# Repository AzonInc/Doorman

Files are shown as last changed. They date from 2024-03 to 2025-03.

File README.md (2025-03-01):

<h1 align="center">
    <br>
    Doorman S3
    <br>
    <br>
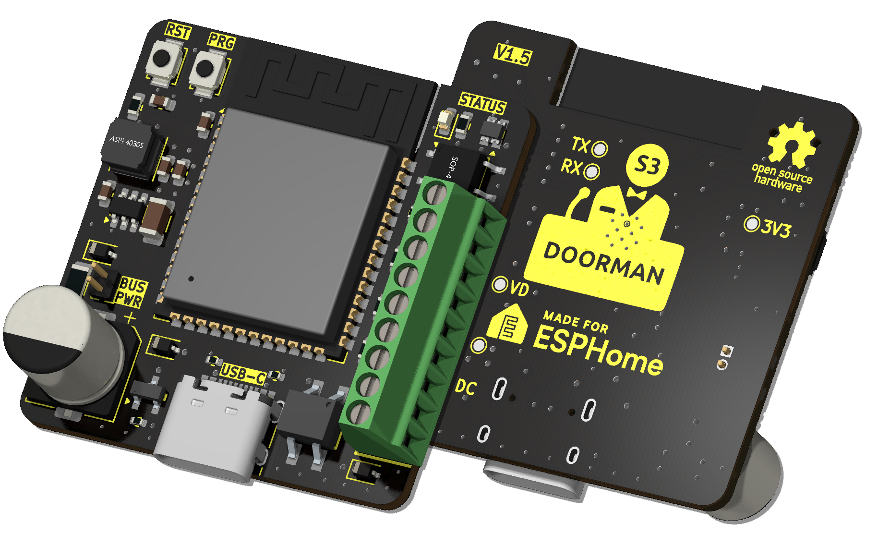
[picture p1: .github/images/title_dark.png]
Doorman S3
    
    <br>
</h1>

**Doorman S3** is a versatile intercom gateway designed to connect your [TCS](https://www.tcsag.de/) or [Koch](https://www.kochag.ch/) intercom system to any home automation platform. It's also compatible with rebranded versions of [Niko](https://www.niko.eu/), [Scantron](https://scantron.dk/), and older [Jung](https://www.jung-group.com/) intercom models.

But that's not all - the **Doorman S3** is more than just an intercom bridge. With its integrated relay, you can simulate button presses to control door openers or lights, supporting up to **40V** and a maximum of **2.5A**. 

Even if your intercom system isn't directly listed, if it operates on a **2-wire bus** in the **14-24V DC range**, you may still be able to implement other protocols. Additionally, you can monitor voltage levels from older intercom systems to trigger actions based on those readings.

For more information on the manufacturing process, head to the **Manufacturing** section further down.

---

<div id="toc">
  <ul style="list-style: none">
    <summary>
      <h1>🚀 Getting started</h1>
    </summary>
  </ul>
</div>

Before diving into the installation process, visit the [Doorman Docs](https://doorman.azon.ai/) for comprehensive setup guides. If you have questions, don't hesitate to reach out on [Discord](https://discord.gg/t2d34dvmBf) or [GitHub Issues](https://github.com/azoninc/doorman/issues). I'm here to assist!

---

<div id="toc">
  <ul style="list-style: none">
    <summary>
      <h1>📦 Interested in buying one?</h1>
    </summary>
  </ul>
</div>

You can get fully assembled **Doorman S3** units with the **[Stock Firmware](firmware/stock-firmware)** pre-installed and ready for immediate integration into **Home Assistant**. 

For inquiries, feel free to reach out via:
- [Discord](https://discord.gg/t2d34dvmBf)
- [E-Mail](mailto:flo@azon.ai?subject=Doorman)

---

<div id="toc">
  <ul style="list-style: none">
    <summary>
      <h1>🛠️ Built Your Own Hardware?</h1>
    </summary>
  </ul>
</div>

Check out the [TC:BUS ESPHome component documentation](https://doorman.azon.ai/reference/esphome-component) for detailed instructions on integrating your DIY hardware with the TC:BUS. Whether you're expanding your **Doorman project** or using it as a starting point for your own system, this resource will guide you through seamless integration.

---

<div id="toc">
  <ul style="list-style: none">
    <summary>
      <h1>🤖 Features</h1>
    </summary>
  </ul>
</div>

- **ESP32-S3 Powered** for robust performance
- **USB-C port** for effortless flashing (because USB-C is just cool 😎)
- **Compact design** fits into any setup
- **Configurable WS2812B RGB LED** for event-based visual indicators
- **Two additional GPIOs** for easy expansion (e.g., I²C sensors)
- **Solid-state relay** for switching up to 40V (max. 2.5A)—perfect for older intercom systems
- **External Button** (G + BTN) for manual triggering
- **Bridge Rectifier** for correcting polarity on bus-wire input
- **TC:BUS Communication** for door functions and detecting the doorbell
- **Nuki Bridge functionality** with the [Nuki Bridge Firmware](https://doorman.azon.ai/guide/firmware/nuki-bridge-firmware) (Note: Incompatible with Nuki app but works with **Home Assistant** app)

---

<div id="toc">
  <ul style="list-style: none">
    <summary>
      <h1>✔️ Compatibility</h1>
    </summary>
  </ul>
</div>

If your TCS or Koch intercom uses **screw terminals labeled `a`, `b`, and `P`** and operates on **24V DC**, it's most likely compatible with **Doorman**.

For more in-depth compatibility information, refer to the [Compatibility Docs](https://doorman.azon.ai/guide/hardware-compatibility).

---

<div id="toc">
  <ul style="list-style: none">
    <summary>
      <h1>🛠️ Manufacturing</h1>
    </summary>
  </ul>
</div>

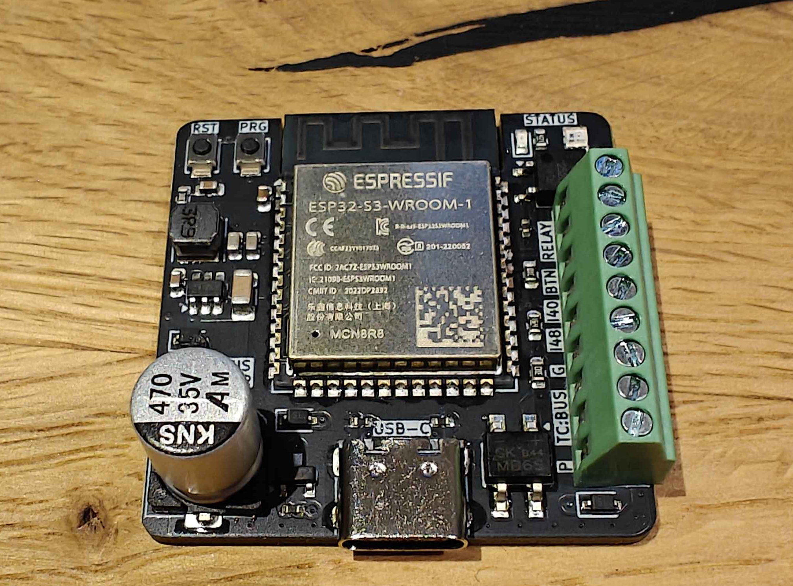
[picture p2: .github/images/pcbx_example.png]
PCBX Delivery


A huge thanks to [PCBX](https://www.pcbx.com/?mtm_campaign=review&mtm_kwd=BD&mtm_source=flo) for manufacturing and sponsoring 10 awesome PCBs for this project! Your support means a lot to us, and your prices are seriously hard to beat. We're thrilled to have you on board!

If you're looking for a reliable PCB manufacturer for your own project, definitely check out [PCBX](https://www.pcbx.com/?mtm_campaign=review&mtm_kwd=BD&mtm_source=flo). While their production might take a little longer than some others, the unbeatable prices and super-easy part sourcing make it absolutely worth it. They handle everything for you!  

You can find all the necessary files for manufacturing the **Doorman-S3** [here](https://github.com/azoninc/doorman/tree/master/pcb).

---

<div id="toc">
  <ul style="list-style: none">
    <summary>
      <h1>🙌 Contributing</h1>
    </summary>
  </ul>
</div>

Contributions to the **Doorman** project are always welcome! Whether it's code improvements, bug fixes, or documentation updates, your help is greatly appreciated. Please feel free to open a **Pull Request**.

---

<div id="toc">
  <ul style="list-style: none">
    <summary>
      <h1>🚩 Repository Structure</h1>
    </summary>
  </ul>
</div>

The repository is organized as follows:
- **`blueprints`**: Automation Blueprints for Home Assistant
- **`components`**: External component files for ESPHome
- **`docs`**: Documentation
- **`enclosure`**: STL design files for the enclosure
- **`firmware`**: ESPHome configuration files
- **`pcb`**: KiCad schematic and PCB design files

---

<div id="toc">
  <ul style="list-style: none">
    <summary>
      <h1>📜 Credits</h1>
    </summary>
  </ul>
</div>

The **Doorman S3** project heavily relies on contributions from several key sources. Without their efforts, this project wouldn't be where it is today. ❤️

**[TCSIntercomArduino](https://github.com/atc1441/TCSintercomArduino)**\
Different Methods to read from and write to the TCS Bus.\
Feel free to watch the [Reverse Engineering Video](https://www.youtube.com/watch?v=xFLoauqj9yA) if you're interested.

**[tcs-monitor](https://github.com/Syralist/tcs-monitor)**\
An mqtt monitor for listening to the TCS Bus.\
You can find more information in this [Blog Post](https://blog.syralist.de/posts/smarthome/klingel/).

**[Doorman](https://github.com/peteh/doorman)**\
A lot of this Doorman project is based on peteh's one.\
The main goal is to provide a proper PCB for his Doorman Project.

**[ESPHome_nuki_lock](https://github.com/uriyacovy/ESPHome_nuki_lock)**\
This module builds an ESPHome lock platform for Nuki Smartlock (nuki_lock).

**[AStrehlau](https://github.com/AStrehlau)**\
Thank you so much for your time, patience, expertise, and every piece of invaluable advice that helped make this project better, smaller, and more affordable.

**[calibanorg](https://github.com/calibanorg)**\
Thank you so much for your support, both in terms of encouragement and financial assistance, in the development of Doorman.

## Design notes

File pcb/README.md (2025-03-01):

# PCB KiCad Files

This directory contains everything PCB related.
You can also find an interactive BOM [here](https://github.com/azoninc/doorman/tree/master/pcb/bom).

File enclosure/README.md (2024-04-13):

# Enclosure Files

This directory contains all the STL Files to be able to print your own enclosure.

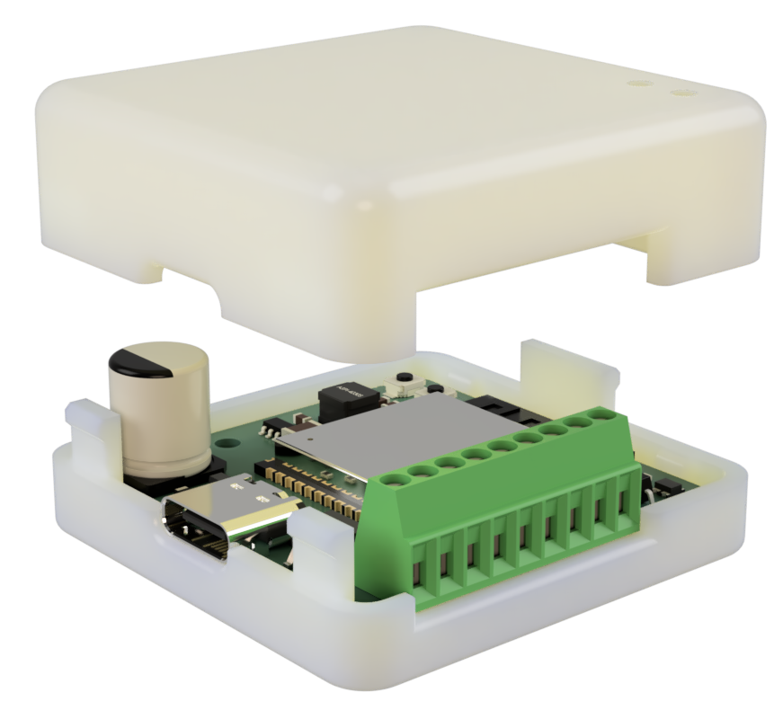
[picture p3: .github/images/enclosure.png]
Doorman S3


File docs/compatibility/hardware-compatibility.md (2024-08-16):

# Can I use Doorman?
If your TCS or Koch Intercom got a, b and P labeled Screw Terminals and is operating on 24V DC it's likely compatible.

There are also some rebranded Niko intercoms which are counterparts of the TCS and Koch ones.

:::danger READ - BEFORE YOU ORDER
Since this is a product of reverse engineering, there is no way to be 100% certain that a your intercom will or won't work without testing it yourself.

1. Make sure to check the wiring and measure the voltage before ordering a Doorman.

2. There is no guarantee that Doorman will work with your intercom due to the fact that every building is wired unique.

3. As stated below it is always possible that some other devices (your neighbors) using the P-line are taking too much current so it's not sufficient to power Doorman anymore. 

**You should understand this risk before purchasing.** If you have any questions, please contact me and I will be happy to help!
:::

## Wiring
If your Intercom is connected in 2-wire mode and you dont have a separate 24V P-Line you need to use an external Power Supply via USB-C or P (+5V to +30V DC) and B (Ground) Screw Terminal.
If it is connected in 3-wire mode you should be able to use the P-Line to power your Doorman in most cases.

::: tip
On some installations the a and b wires are twisted but it doesn't matter because Doorman has an integrated bridge rectifier to handles that for you.
Consider that when you check the voltage level on a, b and P lines.
:::

#### Intercom Screw Terminal Explanation
- **a** is usually the Bus line (+24V)
- **b** is usually GND
- **P** is the +24V line in 3-wire mode or just the apartment doorbell button in 2-wire mode

::: danger
**DO NOT USE THE +24V P-LINE AND USB-C AT THE SAME TIME**
:::

## Check the power supply
Use a multimeter to check the DC voltage.
Since the a and b lines can be twisted you have to measure the polarity first.

#### Expected voltage
- Between a and b: ~ 24.0V
- Between P and b: ~ 23.2V

::: warning
The minimum output current of the intercom power supply **must be 60mA** in order to achieve a stable operation!

However it is possible that some other devices using the P-line are taking too much current so it's not sufficient to power Doorman anymore.

A best case scenario would be that you can use the P-line with 60mA. That doesn't work for everyone tho.

**Please power your Doorman with an external Power Supply (USB-C or Screw Terminal) if your intercoms power supply provides less than 60mA or whenever you notice an unstable operation.** 
:::

## Known issues

Some intercom phones having a TTC1-B-1 connector module cause problems because the a and P Connector are somehow connected. However it's not clear which models are affected yet.

::: danger Problem
A loud beeping noise occurs whenever someone is talking.
:::

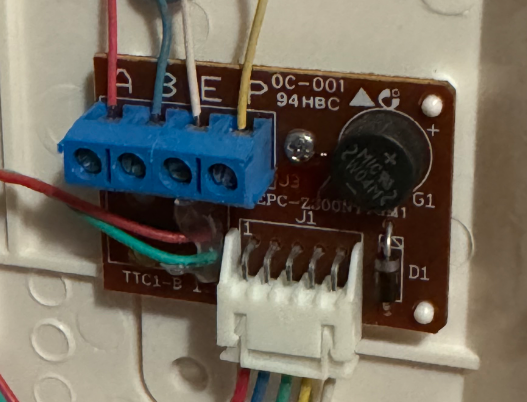
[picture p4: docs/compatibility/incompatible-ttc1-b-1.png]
ttc1-b-1-module


## Tested Hardware

- TCS ISH3030 / ISH3130
- TCS ISW3030 / ISW3130

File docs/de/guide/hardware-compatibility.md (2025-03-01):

# Kann ich Doorman benutzen?

Wenn deine [TCS](https://www.tcsag.de/), [Koch](https://www.kochag.ch/) oder [Scantron](https://scantron.dk/) Innenstation die Anschlussklemmen `a`, `b` und `P` hat und mit 24V DC betrieben wird, ist sie wahrscheinlich kompatibel.

Einige umgelabelte [Niko](https://www.niko.eu/) und ältere [Jung](https://www.jung-group.com/) Innenstationen, die den TCS- und Koch-Modellen entsprechen, könnten ebenfalls passen.

:::danger WICHTIG - BEVOR DU BESTELLST
Da dieses Produkt durch Reverse Engineering entwickelt wurde, gibt es keine Garantie, dass deine Sprechanlage ohne Tests funktioniert.

1. Überprüfe die Verkabelung und miss die Spannung, bevor du Doorman bestellst.
2. Es gibt keine Garantie, dass Doorman mit deiner Innenstation funktioniert, da die Verkabelung in jedem Gebäude einzigartig ist.
3. Andere Geräte an der `P`-Leitung (z.B. Geräte deiner Nachbarn) könnten zu viel Strom ziehen und Doorman beeinträchtigen.

**Verstehe diese Risiken, bevor du einen bestellst.** Wenn du Fragen hast, kontaktiere mich gerne und ich helfe dir weiter!
:::

## Verkabelung
**2-Draht-Modus:**\
Wenn deine Innenstation im 2-Draht-Modus angeschlossen ist und du keine separate 24V `P`-Leitung hast, verwende etweder die `BUS PWR` Jumper (ab rev. 1.5), eine externe Stromversorgung über USB-C oder die Schraubklemmen `P` (+5V bis +30V DC) und `G` (Ground).

**3-Draht-Modus:**\
Wenn sie im 3-Draht-Modus angeschlossen ist, solltest du in den meisten Fällen die `P`-Leitung zur Stromversorgung vom Doorman nutzen können.

::: tip
Bei einigen Installationen sind die `a`- und `b`-Drähte verdreht, das wird aber von dem integriertem Brückengleichrichter korrigiert.

Berücksichtige dies beim Überprüfen der Spannung auf den Leitungen `a`, `b` und `P`.
:::

#### Erklärung der Innenstation-Anschlussklemmen
- **a:** In der Regel die Bus-Leitung (+24V)
- **b:** Normalerweise Ground
- **P:** Entweder die +24V-Leitung im 3-Draht-Modus oder der Klingelknopf der Wohnung im 2-Draht-Modus. Oftmals gibt es trotzdem eine 24V Leitung irgendwo versteckt.

::: danger VORSICHT
**BENUTZE NICHT DIE +24V `P`-LEITUNG UND DEN USB-C PORT GLEICHZEITIG!**

**SCHLIEßE AUF KEINEN FALL EINE STROMQUELLE AN DIE TC:BUS-TERMINALE AN, SONST KÖNNTE DAS RICHTIG SCHADEN ANRICHTEN!**
:::

## Überprüfe die Stromversorgung
Verwende ein Multimeter, um die DC-Spannung zu messen.\
Miss zuerst die Polarität, da die `a`- und `b`-Leitungen verdreht sein können.

#### Erwartete Spannung
- Zwischen `a` und `b`: ~ 24,0V
- Zwischen `P` und `b`: ~ 23,2V

::: warning
Die Stromversorgung der Gegensprechanlage **muss mindestens 60mA Ausgangsstrom liefern**, um stabil zu funktionieren.

Wenn andere Geräte an der `P`-Leitung zu viel Strom ziehen, reicht es möglicherweise nicht aus, um Doorman zu betreiben.

**Verwende eine externe Stromversorgung (USB-C oder Schraubklemme), wenn die Stromversorgung deiner Sprechanlage weniger als 60mA liefert oder wenn du eine instabile Funktion bemerkst.**
:::

## Bekannte Probleme

Innenstationen mit einem TTC1-B-1 Anschlussmodul verursachen Probleme, da die `a`- und `P`-Anschlüsse verbunden sind.
Ab Hardware Revision `1.5` gibt es eine neue Anschlussmethode, welche nur noch ein leises, aber dennoch wahrnehmbares Rauschen im Lautsprecher erzeugt.

::: danger Problem von älteren Hardware revisionen vor 1.5
Es tritt ein lautes Piepen auf, wenn jemand spricht.
:::

ttc1-b-1-module

## Verifizierte Modelle

Schau dir die [unterstützten Modelle und Einstellungen](../../reference/esphome-component.md#model-setting-availability) an.  
Modelle mit verfügbaren Einstellungen sind auf jeden Fall kompatibel. Falls dein Modell nicht dabei ist, erstelle bitte ein Issue, um die Kompatibilität zu überprüfen.

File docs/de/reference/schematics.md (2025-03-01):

# Schaltpläne

Die Schaltpläne des Doorman-S3 sind vollständig Open Source. Du kannst alle Dateien im [GitHub-Repository](https://github.com/azoninc/doorman/tree/master/pcb) einsehen.

Nutze die interaktiven Viewer unten, um PCB- und Schaltplan-Designs anzusehen. Versuche die Seite neu zu laden, falls du Probleme mit den Viewern hast.

## Schaltplan-Viewer

<kicanvas-embed src="https://raw.githubusercontent.com/azoninc/doorman/master/pcb/doorman.kicad_sch" controls="full"></kicanvas-embed>

## PCB-Viewer

<kicanvas-embed src="https://raw.githubusercontent.com/azoninc/doorman/master/pcb/doorman.kicad_pcb" controls="full"></kicanvas-embed>

## Interactive BOM
Klicke [hier](../ibom.html){target="_self"}, um den interaktiven BOM-Viewer zu öffnen.

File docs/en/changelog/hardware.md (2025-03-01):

# PCB Revision History & Changelog
Welcome to the complete history of all PCB updates! This page highlights the new features, improvements, and changes made in each revision.

## 1.6.0 <Badge type="warning" text="Next" />
- Extend ground plane around power supply section
- Low impedance voltage divider
- Power supply redesign
- Add more filter capacitors to for noise on the bus

## 1.5.0 <Badge type="tip" text="Current" />
- Power supply redesign based on the reference design
- New method to power the Doorman-S3 via TC:BUS using a jumper cap
- Connected GPIO10 to the BUS line, thus it's not needed to change the firmware to work with the voltage anymore
- Removed copper around the wifi antenna to improve signal strength
- New ESPHome Logo

## 1.4.0
- Added a diode to prevent multiple power sources damage the circuit

## 1.3.0
Initial release

## 1.2.0
No changelog available / Development Board

## 1.1.0
No changelog available / Development Board

## 1.0.0
No changelog available / Development Board

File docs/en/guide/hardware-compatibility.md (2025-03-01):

# Can I use Doorman?
If your [TCS](https://www.tcsag.de/), [Koch](https://www.kochag.ch/) or [Scantron](https://scantron.dk/) indoor station has `a`, `b`, and `P` labeled screw terminals and operates on 24V DC, it's likely compatible.

Some rebranded [Niko](https://www.niko.eu/) and older [Jung](https://www.jung-group.com/) indoor stations, which are counterparts to the TCS and Koch models, may also be compatible.

:::danger READ - BEFORE YOU ORDER
Since this product is the result of reverse engineering, there is no guarantee that your indoor station will work without testing it yourself.

1. Check the wiring and measure the voltage before ordering a Doorman.

2. There is no guarantee that Doorman will work with your intercom due to the unique wiring in each building.

3. Other devices on the `P`-line (e.g., your neighbors' equipment) may draw too much current, potentially affecting Doorman's performance.

**Understand these risks before purchasing.** If you have any questions, please contact me, and I will be happy to help!
:::

## Wiring
**2-Wire Mode:**\
If your indoor station is connected in 2-wire mode and you don't have a separate 24V `P`-line, use either the `BUS PWR` jumper (starting with rev. 1.5), an external power supply via USB-C or the `P` (+5V to +30V DC) and `b` (Ground) screw terminals.

**3-Wire Mode:**\
If connected in 3-wire mode, you should be able to use the `P`-line to power your Doorman in most cases.

::: tip
In some installations, the `a` and `b` wires are twisted, but this is handled by Doorman's integrated bridge rectifier. Consider this when checking the voltage levels on the `a`, `b`, and `P` lines.
:::

#### Indoor Station Screw Terminal Explanation
- **a:** Typically the Bus line (+24V)
- **b:** Typically Ground
- **P:** The +24V line in 3-wire mode or the apartment doorbell button in 2-wire mode

::: danger
**AVOID USING THE +24V `P`-LINE AND USB-C PORT AT THE SAME TIME.**\
**NEVER CONNECT A POWER SOURCE TO THE TC:BUS TERMINALS - DOING SO CAN CAUSE SEVERE DAMAGE.**
:::

## Check the Power Supply
Use a multimeter to check the DC voltage.\
Measure the polarity first since the `a` and `b` lines can be twisted.

#### Expected Voltage
- Between `a` and `b`: ~ 24.0V
- Between `P` and `b`: ~ 23.2V

::: warning
The intercom power supply **must have a minimum output current of 60mA** for stable operation.

If other devices using the `P`-line draw too much current, it may not be sufficient to power Doorman.

**Use an external power supply (USB-C or screw terminal) if your intercom's power supply provides less than 60mA or if you notice unstable operation.** 
:::

## Known Issues

Indoor stations with a TTC1-B-1 connector module cause issues because the `a` and `P` lines are connected.
Starting with revision `1.5` this issue is addressed with a new power supply option which will only produce a subtle, yet noticeable hissing sound on the speaker using the mentioned module.

::: danger Problem for revisions older than 1.5
A loud beeping noise occurs whenever someone is talking.
:::

ttc1-b-1-module

## Verified Hardware

Check out the [supported models and settings](../reference/esphome-component.md#model-setting-availability).  
Models with available settings are guaranteed to be compatible. If your model isn't listed, please open an issue to verify its compatibility.

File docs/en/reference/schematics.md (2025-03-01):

# Schematics

The schematics for the Doorman-S3 are fully open source and available for reference. You can also access the KiCad source files in the [GitHub repository](https://github.com/azoninc/doorman/tree/master/pcb).

To view the PCB and schematic designs, use the interactive viewers below. If you encounter any issues with the viewers, try refreshing the page.

## Schematics Viewer

<kicanvas-embed src="https://raw.githubusercontent.com/azoninc/doorman/master/pcb/doorman.kicad_sch" controls="full"></kicanvas-embed>

## PCB Viewer

<kicanvas-embed src="https://raw.githubusercontent.com/azoninc/doorman/master/pcb/doorman.kicad_pcb" controls="full"></kicanvas-embed>

## Interactive BOM
Click [here](../ibom.html){target="_self"} to open the interactive BOM viewer.

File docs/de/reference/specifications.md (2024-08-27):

# Doorman Hardware-Spezifikationen
Hier findest du ein paar Infos zur Nutzung:

## Stromversorgung
Dank des breiten Spektrums des Spannungswandlers kann der Doorman S3 mit einer Spannung von 5 bis 30V DC betrieben werden.

## Gleichrichterbrücke
Die Gleichrichterbrücke sorgt dafür, dass die Polarität der Busleitung passt. Du musst dir darüber keine Gedanken machen.

## Relais
Beim Doorman-S3 wird ein Solid-State-Relais verwendet. Dieses kann Lasten bis zu 40V bei maximal 2,5A schalten.

## Externer Button
An der BTN Schraubklemme hängt ein 10 kΩ Pull-up Widerstand. Du kannst den Button an die Schraubklemmen BTN und G anschließen.

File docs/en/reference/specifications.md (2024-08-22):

# Doorman Hardware specifications
You can find a few information here about how to use 

## Power supply
Thanks to the wide voltage converter, the Doorman S3 can operate with a supply voltage ranging from 5 to 30V DC.

## Bridge Rectifier
The Bridge Rectifier will correct the Bus wire polarity. You don't have to worry about it.

## Relay
The relay is a solid-state type, capable of switching loads up to 40V with a maximum current of 2.5A.

## External Button
It is a pull-up button with a 10 kΩ resistor. You can connect the button to BTN and G screw terminals.

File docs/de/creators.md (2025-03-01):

<script setup>
import { VPTeamMembers } from 'vitepress/theme'

const members = [
  {
    avatar: 'https://www.github.com/azoninc.png',
    name: 'AzonInc',
    title: 'Ersteller vom Doorman-S3 PCB und der ESPHome-basierten Firmware',
    links: [
      { icon: 'github', link: 'https://github.com/azoninc' },
    ],
    sponsor: 'https://github.com/sponsors/azoninc',
  },
  {
    avatar: 'https://www.github.com/peteh.png',
    name: 'peteh',
    title: 'Entwickler der original Doorman custom Firmware',
    links: [
      { icon: 'github', link: 'https://github.com/peteh' },
    ],
    sponsor: 'https://github.com/sponsors/peteh',
  },
  {
    avatar: 'https://www.github.com/astrehlau.png',
    name: 'AStrehlau',
    title: 'Electronics Engineer',
    links: [
      { icon: 'github', link: 'https://github.com/astrehlau' },
    ]
  },
  {
    avatar: 'https://www.github.com/calibanorg.png',
    name: 'calibanorg',
    title: 'Sponsor für die Entwicklung',
    links: [
      { icon: 'github', link: 'https://github.com/calibanorg' },
    ]
  },
  {
    avatar: 'https://www.github.com/atc1441.png',
    name: 'atc1441',
    title: 'Reverse engineering der TCS Bus Kommunikation',
    links: [
      { icon: 'github', link: 'https://github.com/atc1441' },
    ],
    sponsor: 'https://paypal.me/hoverboard1'
  },
  {
    avatar: 'https://www.github.com/uriyacovy.png',
    name: 'uriyacovy',
    title: 'Entwickler der ESPHome Nuki Lock Komponente',
    links: [
      { icon: 'github', link: 'https://github.com/uriyacovy' },
    ]
  }
]
</script>

# Danke ❤️

Doorman basiert auf dem Code und den Informationen der folgenden Projekte und Personen. Ohne eure Beiträge wäre dieses Projekt nicht möglich gewesen.

### Coole Leute

<VPTeamMembers size="small" :members="members" />

### Projekte

**[TCSIntercomArduino](https://github.com/atc1441/TCSintercomArduino)**\
Verschiedene Methoden zum Lesen und Schreiben auf dem TCS-Bus.\
Wenn du interessiert bist, kannst du dir gerne das [Reverse Engineering Video](https://www.youtube.com/watch?v=xFLoauqj9yA) ansehen.

**[tcs-monitor](https://github.com/Syralist/tcs-monitor)**\
Ein MQTT-Monitor zum Überwachen des TCS-Bus.\
Weitere Informationen findest du in diesem [Blog Post](https://blog.syralist.de/posts/smarthome/klingel/).

**[Doorman](https://github.com/peteh/doorman)**\
Ein wesentlicher Teil des Doorman-Projekts basiert auf der Arbeit von peteh.\
Das Hauptziel war es, ein robustes PCB für sein Doorman-Projekt bereitzustellen.

**[ESPHome_nuki_lock](https://github.com/uriyacovy/ESPHome_nuki_lock)**\
Diese Komponente erstellt eine ESPHome-Schlossplattform für das Nuki Smartlock (nuki_lock).

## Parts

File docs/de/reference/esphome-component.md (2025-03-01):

# TC:BUS ESPHome Komponente

<div class="tip custom-block" style="padding-top: 8px">

Die Dokumentation dazu gibt es nur auf Englisch. Klicke [hier](../../reference/esphome-component) um zu wechseln.

</div>

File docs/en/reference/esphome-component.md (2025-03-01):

# TC:BUS ESPHome Component

The TC:BUS Component for ESPHome allows you to interface with a [TCS:Bus](https://www.tcsag.de/) or [Koch TC:Bus](https://kochag.ch/) intercom system, providing automation, monitoring, and interaction capabilities within the [ESPHome](https://esphome.io/) ecosystem.
This component can trigger automations based on specific commands received from the intercom system.

It also supports sending commands to the intercom and receiving various status updates (e.g., bus commands and door readiness).
Additionally, actions can be set up to respond to specific commands from the intercom system.

::: tip Note
This component requires hardware like the Doorman-S3 or a [DIY solution](https://github.com/peteh/doorman) in order to communicate on the bus.
:::

## Configuration Options

### TC:BUS Hub
The `tc_bus` hub component offers the following configuration options:

| Option | Description | Required | Default |
|---|---|---|---|
| `id` | Unique ID for the component. | Yes | |
| `rx_pin` | GPIO pin for receiving data from the TC:BUS intercom. | No | `9` |
| `tx_pin` | GPIO pin for transmitting data to the TC:BUS intercom. Should be connected to the transistor. | No | `8` |
| `event` | Event name to be generated in Home Assistant when a bus command is received. For example, if set to `tc`, the event will be `esphome.tc`. Set to `none` to disable event generation. | No | `tc` |
| `on_command` | Defines actions to be triggered when a command is received from the intercom. Returns a `CommandData` structure as the `x` variable. | No | |
| `on_read_memory_complete` | Defines actions to be triggered when the memory reading is complete. Returns a `std::vector<uint8_t>` buffer as the `x` variable. | No | |
| `on_read_memory_timeout`  | Defines actions to be triggered when the memory reading times out. | No | |
| `on_identify_complete` | Defines actions to be triggered when the identification of the indoor station is complete. Returns a `ModelData` object as the `x` variable.  | No | |
| `on_identify_timeout` | Defines actions to be triggered when the identification of the indoor station times out. | No | |

### Number Inputs
The `tc_bus` Number Input component offers the following configuration options:

| Option | Description | Required | Default |
|---|---|---|---|
| `serial_number` | Indoor Station Serial Number Input to set the serial number of the predefined indoor station. | No | |
| `volume_handset_door_call` | Door Call Handset Volume Number Input to set the handset volume for door calls of your indoor station. | No | |
| `volume_handset_internal_call` | Internal Call Handset Volume Number Input to set the handset volume for internal calls of your indoor station.| No | |
| `volume_ringtone` | Ringtone Volume Number Input to set the ringtone volume of your indoor station. | No | |

### Text Sensors
The `tc_bus` Text Sensor component offers the following configuration options:

| Option | Description | Required | Default |
|---|---|---|---|
| `bus_command` | Text Sensor to display the last received bus command. | No | |
| `hardware_version` | Text Sensor to display the Doorman-S3 hardware version. | No | |

### Select Inputs
The `tc_bus` Select component offers the following configuration options:

| Option | Description | Required | Default |
|---|---|---|---|
| `model` | Model Select to set the model of your indoor station (used to read and write settings). Take a look at the [supported models and settings](#model-setting-availability).| No | `None` |
| `ringtone_entrance_door_call` | Entrance Door Call Ringtone Select to set the entrance door call ringtone of your indoor station. | No | |
| `ringtone_second_entrance_door_call` | Second Entrance Door Call Ringtone Select to set the second entrance door call ringtone of your indoor station.| No | |
| `ringtone_floor_call` | Floor Call Ringtone Select to set the floor call ringtone of your indoor station. | No | |
| `ringtone_internal_call` | Internal Call Ringtone Select to set the internal call ringtone of your indoor station. | No | |

### Binary Sensors

The **TC:BUS Binary Sensor** detects binary states such as doorbell presses. It can be configured to trigger based on a predefined command or a lambda expression.

| Option | Description | Required | Default |
|---|---|---|---|
| `id` | Unique ID for the binary sensor component. | Yes | |
| `icon` | Icon to represent the sensor in the UI. | No | `mdi:doorbell`|
| `name` | Name of the binary sensor. | No | `Doorbell` |
| `auto_off` | Time period after which the sensor automatically turns off, useful for momentary signals like doorbell presses.  | No | `3s` |
| `command` | A specific 32-bit hexadecimal command that triggers the binary sensor when received from the TC:BUS intercom.| Yes | `0` |
| `command_lambda` | Lambda expression used to dynamically generate the command that will trigger the binary sensor, instead of using a fixed command. Cannot be used with `command`.  | No | |
| `type` | Command type that will trigger the binary sensor, used alongside `address` and `serial_number`. Cannot be used with `command`.  | Yes | `unknown` |
| `address` | 8-bit address that serves as a condition to trigger the binary sensor. If you set it to `255`, it will catch all addresses. | No | `0` |
| `address_lambda` | Lambda expression to evaluate whether the binary sensor should trigger based on the address. | No | |
| `payload` | 32-bit payload that serves as a condition to trigger the binary sensor.  | No | `0` |
| `payload_lambda` | Lambda expression to evaluate whether the binary sensor should trigger based on the payload. | No | |
| `serial_number`  | Specific intercom serial number that serves as a condition to trigger the binary sensor. If you set it to `255`, it will catch all serial numbers. | No | `unknown` |

::: info
You can use **either** `command`/`command_lambda` **or** a combination of `type`, `address`/`address_lambda`, `payload`/`payload_lambda`, and `serial_number`, but **not both** simultaneously.\
This ensures the binary sensor triggers either through a specific command or a combination of parameters, preventing conflicts.
:::

## Callbacks
### Received Command
The `on_command` callback of the `tc_bus` hub allows you to utilize the [CommandData](#command-data) structure, accessible as the `x` variable.

```yaml
on_command:
  - lambda: |-
      ESP_LOGD("TAG", "Received Command Type: %s", command_type_to_string(x.type));

      if (x.type == COMMAND_TYPE_OPEN_DOOR) {
        ESP_LOGD("TAG", "Opened Door of outdoor station %i", x.address);
      }
```

### Read Memory Complete
The `on_read_memory_complete` callback of the `tc_bus` hub allows you to work with the memory buffer, accessible as the `x` variable.

```yaml
on_read_memory_complete:
  - logger.log: "Completed memory reading!"
  - lambda: |-
      std::string hexString = str_upper_case(format_hex(x));
      ESP_LOGI("tc_bus", "Memory Dump: %s", hexString.c_str());
```

### Read Memory Timeout
The `on_read_memory_timeout` callback of the `tc_bus` hub allows you to detect a failed memory reading. Most probably when a model doesn't support the related commands.

```yaml
on_read_memory_timeout:
  - logger.log: "Failed to read Memory"
```

### Identification of Indoor Station Complete
The `on_identify_complete` callback of the `tc_bus` hub allows you to utilize the [ModelData](#model-data) structure, accessible as the `x` variable.

```yaml
on_identify_complete:
  - logger.log: "Completed identification!"
  - lambda: |-
      std::string hexString = str_upper_case(format_hex(x));
      ESP_LOGI("tc_bus", "Memory Dump: %s", hexString.c_str());
```

### Identification of Indoor Station Timeout
The `on_identify_timeout` callback of the `tc_bus` hub allows you to detect a failed identification of the indoor station. Most probably when a model is too old doesn't support this process.

```yaml
on_identify_timeout:
  - logger.log: "Failed to identify indoor station!"
```

## Actions
### Read Memory
The `tc_bus.read_memory` action allows you to read the memory of any indoor station using the serial number.

```yaml
on_...:
  - tc_bus.read_memory:
      serial_number: 123456
```

### Identify Indoor Station
The `tc_bus.identify` action allows you to identify the model of any indoor station using the serial number.
::: tip Note
Not all models support this feature. For older indoor stations, you may need to select the model manually.
:::

```yaml
on_...:
  - tc_bus.identify:
      serial_number: 123456
```

### Set Programming Mode
The `tc_bus.set_programming_mode` action allows you to enable or disable the programming mode of the control unit.

```yaml
on_...:
  - tc_bus.set_programming_mode:
      programming_mode: true
```

### Update Setting
The `tc_bus.update_setting` action allows you to change the supported settings of any indoor station.
Take a look at the [supported models and settings](#model-setting-availability).

```yaml
on_...:
  - tc_bus.update_setting:
      type: volume_ringtone
      value: 7
      serial_number: 123456
```

### Sending Commands

You can send commands on the bus using the `tc_bus.send` action.

::: tip Note
You can either use the `command` field to send a specific command or use the `type`, `address`, `payload`, and `serial_number` fields to create a more complex message. **Both cannot be used at the same time**.

You can explicitly send a 32-bit command by using the optional `is_long` property, which is useful when the command begins with leading zeros.
:::

#### Example 1: Sending a raw Command

```yaml
on_...:
  - tc_bus.send:
      command: 0x1A2B3C4D
```
#### Example 2: Sending a raw Command with fixed size

```yaml
on_...:
  - tc_bus.send:
      command: 0x00000280
      is_long: True
```

#### Example 3: Sending a Command via Command Builder

```yaml
on_...:
  - tc_bus.send:
      type: open_door
      address: 0
      payload: 0
      serial_number: 123456
```

#### Example 3: Sending Multiple Commands

For some configurations, you may need to send multiple commands consecutively. In these cases, you must insert at least a 100ms delay between the commands.

```yaml
on_...:
  - tc_bus.send:
      command: 0x1100
  - delay: 100ms
  - tc_bus.send:
      command: 0x2100
```

## Event Handling
If the `event` parameter is set (and not `none`), an event is generated each time a command is received. You can monitor these events in Home Assistant on the [developer tools](https://my.home-assistant.io/redirect/developer_events/) page.

Each time a command is received, an event like the following is generated:

```yaml
event_type: esphome.doorman
data:
  device_id: xxxxxxxxxxxxxxxxxxxxxxxxx
  command: "0x00002400"
  type: "end_of_door_readiness"
  address: "0"
  payload: "0"
  serial_number: "0"
origin: LOCAL
time_fired: "2024-01-01T00:00:00.000000+00:00"
context:
  id: xxxxxxxxxxxxxxxxxxxxxxxx
  parent_id: null
  user_id: null
```

To trigger a Home Assistant automation based on this event, you can use an `event` trigger:

```yaml
platform: event
event_type: esphome.doorman
event_data:
  command: "0x00002480"
```

```yaml
platform: event
event_type: esphome.doorman
event_data:
  type: "end_of_door_readiness"
  address: "0"
  serial_number: "0"
```

Be sure to modify the command and event name as needed based on your configuration.

## Example YAML Configuration

Here is an example configuration for the TC:BUS component in ESPHome:

```yaml
external_components:
  - source: github://azoninc/doorman
    components: [ tc_bus ]

# TC:BUS configuration
tc_bus:
  id: my_tc_bus
  rx_pin: GPIO9
  tx_pin: GPIO8
  event: "doorman"
  on_command:
    - logger.log: "Received command from intercom!"

number:
  - platform: tc_bus
    serial_number:
      name: "Serial Number"

text_sensor:
  - platform: tc_bus
    bus_command:
      name: "Last Bus Command"

# Binary sensor for doorbell press
binary_sensor:
  - platform: tc_bus
    id: doorbell_sensor_raw
    name: "Outdoor Station Doorbell (raw)"
    icon: "mdi:doorbell"
    command: 0x0C30BA80
    auto_off: 2s

  - platform: tc_bus
    id: doorbell_sensor_new
    name: "Outdoor Station Doorbell (parser)"
    icon: "mdi:doorbell"
    type: door_call
    auto_off: 2s

  - platform: tc_bus
    id: doorbell_sensor_new_other
    name: "Outdoor Station Doorbell of other serial number (parser)"
    icon: "mdi:doorbell"
    type: door_call
    serial_number: 123456

  - platform: tc_bus
    id: door_opener_sensor
    name: "Someone opened the door of outdoor station 0"
    icon: "mdi:door"
    type: open_door
    address: 0
    serial_number: 255 # 255 is used to catch all

# Sending commands
button:
  - platform: template
    name: "Open Door (raw)"
    on_press:
      - tc_bus.send:
          command: 0x1100

  - platform: template
    name: "Open Door (builder)"
    on_press:
      - tc_bus.send:
          type: open_door
          address: 0
```

## Advanced Configuration

### Accessing intercom settings
If you need to access the supported settings in the memory buffer you can use the `get_setting` method of the `tc_bus` hub.
Take a look at the [setting types](#setting-types).

Example (read and write setting):
```yaml
button:
  - platform: template
    name: "Read Handset volume"
    on_press:
      -lambda: |-
          ESP_LOGD("TAG", "Handset volume: %i", id(tc_bus_intercom)->get_setting(SETTING_VOLUME_HANDSET_DOOR_CALL));

  - platform: template
    name: "Set Handset volume"
    on_press:
      - tc_bus.update_setting:
          type: volume_handset_door_call
          value: 7
```

## Command Data
The `CommandData` structure is used internally and can also be used in the `on_command`.

```c++
struct CommandData {
    uint32_t command;
    std::string command_hex;
    CommandType type;
    uint8_t address;
    uint32_t serial_number;
    uint32_t payload;
    bool is_long;
};
```

## Model Data
The `ModelData` structure is used internally in the identification process.

```c++
struct ModelData {
    Model model = MODEL_NONE;
    uint32_t firmware_version = 0;
    uint8_t firmware_major = 0;
    uint8_t firmware_minor = 0;
    uint8_t firmware_patch = 0;
    uint8_t hardware_version = 0; 
    uint8_t category = 0;
    uint8_t memory_size = 0; 
};
```

## Command Types
You can use command types in binary sensors and also when [sending commands](#sending-commands):

- door_call <Badge type="tip" text="COMMAND_TYPE_DOOR_CALL" />
- floor_call <Badge type="tip" text="COMMAND_TYPE_FLOOR_CALL" />
- internal_call <Badge type="tip" text="COMMAND_TYPE_INTERNAL_CALL" />
- control_function <Badge type="tip" text="COMMAND_TYPE_CONTROL_FUNCTION" />
- start_talking_door_call <Badge type="tip" text="COMMAND_TYPE_START_TALKING_DOOR_CALL" />
- start_talking <Badge type="tip" text="COMMAND_TYPE_START_TALKING" />
- stop_talking_door_call <Badge type="tip" text="COMMAND_TYPE_STOP_TALKING_DOOR_CALL" />
- stop_talking <Badge type="tip" text="COMMAND_TYPE_STOP_TALKING" />
- open_door <Badge type="tip" text="COMMAND_TYPE_OPEN_DOOR" />
- open_door_long <Badge type="tip" text="COMMAND_TYPE_OPEN_DOOR_LONG" />
- light <Badge type="tip" text="COMMAND_TYPE_LIGHT" />
- door_opened <Badge type="tip" text="COMMAND_TYPE_DOOR_OPENED" />
- door_closed <Badge type="tip" text="COMMAND_TYPE_DOOR_CLOSED" />
- end_of_ringtone <Badge type="tip" text="COMMAND_TYPE_END_OF_RINGTONE" />
- end_of_door_readiness <Badge type="tip" text="COMMAND_TYPE_END_OF_DOOR_READINESS" />
- initialize_door_station <Badge type="tip" text="COMMAND_TYPE_INITIALIZE_DOOR_STATION" />
- reset <Badge type="tip" text="COMMAND_TYPE_RESET" />
- select_device_group <Badge type="tip" text="COMMAND_TYPE_SELECT_DEVICE_GROUP" />
- select_device_group_reset <Badge type="tip" text="COMMAND_TYPE_SELECT_DEVICE_GROUP_RESET" />
- search_devices <Badge type="tip" text="COMMAND_TYPE_SEARCH_DEVICES" />
- found_device <Badge type="tip" text="COMMAND_TYPE_FOUND_DEVICE" />
- found_device_subsystem <Badge type="tip" text="COMMAND_TYPE_FOUND_DEVICE_SUBSYSTEM" />
- programming_mode <Badge type="tip" text="COMMAND_TYPE_PROGRAMMING_MODE" />
- read_memory_block <Badge type="tip" text="COMMAND_TYPE_READ_MEMORY_BLOCK" />
- select_memory_page <Badge type="tip" text="COMMAND_TYPE_SELECT_MEMORY_PAGE" />
- write_memory <Badge type="tip" text="COMMAND_TYPE_WRITE_MEMORY" />
- request_version <Badge type="tip" text="COMMAND_TYPE_REQUEST_VERSION" />

## Setting Types
Here are the available setting types you can use to update the settings of your indoor station:

- ringtone_floor_call <Badge type="tip" text="SETTING_RINGTONE_FLOOR_CALL" />
- ringtone_entrance_door_call <Badge type="tip" text="SETTING_RINGTONE_ENTRANCE_DOOR_CALL" />
- ringtone_second_entrance_door_call <Badge type="tip" text="SETTING_RINGTONE_SECOND_ENTRANCE_DOOR_CALL" />
- ringtone_internal_call <Badge type="tip" text="SETTING_RINGTONE_INTERNAL_CALL" />
- volume_ringtone <Badge type="tip" text="SETTING_VOLUME_RINGTONE" />
- volume_handset_door_call <Badge type="tip" text="SETTING_VOLUME_HANDSET_DOOR_CALL" />
- volume_handset_internal_call <Badge type="tip" text="SETTING_VOLUME_HANDSET_INTERNAL_CALL" />

## Model Setting availability
Below are the available settings for specific indoor station models:

| Model | Available settings |
|---|---|
| TCS ISH1030 / Koch TTS25 | `ringtone_floor_call`, `ringtone_entrance_door_call`, `ringtone_internal_call` |
| TCS ISH3030 / Koch TCH50 / Scantron Lux2 | `ringtone_floor_call`, `ringtone_entrance_door_call`, `ringtone_internal_call`, `volume_ringtone`, `volume_handset_door_call` |
| TCS ISH3130 / Koch TCH50P / Scantron LuxPlus | `ringtone_floor_call`, `ringtone_entrance_door_call`, `ringtone_internal_call`, `volume_ringtone`, `volume_handset_door_call` |
| TCS ISH3230 / Koch TCH50 GFA | `ringtone_floor_call`, `ringtone_entrance_door_call`, `ringtone_internal_call`, `volume_ringtone`, `volume_handset_door_call` |
| TCS ISH3340 | `ringtone_floor_call`, `ringtone_entrance_door_call`, `ringtone_internal_call`, `volume_ringtone`, `volume_handset_door_call` |
| TCS ISW3030 / Koch TC50 / Scantron Stilux | `ringtone_floor_call`, `ringtone_entrance_door_call`, `ringtone_internal_call`, `volume_ringtone`, `volume_handset_door_call` |
| TCS ISW3230 / Koch TC50 GFA  | `ringtone_floor_call`, `ringtone_entrance_door_call`, `ringtone_internal_call`, `volume_ringtone`, `volume_handset_door_call` |
| TCS ISW3340 | `ringtone_floor_call`, `ringtone_entrance_door_call`, `ringtone_internal_call`, `volume_ringtone`, `volume_handset_door_call` |
| TCS ISW3130 / Koch TC50P | `ringtone_floor_call`, `ringtone_entrance_door_call`, `ringtone_internal_call`, `volume_ringtone`, `volume_handset_door_call` |
| TCS IVH3222 / Koch VTCH50 / Scantron VLux | `ringtone_floor_call`, `ringtone_entrance_door_call`, `ringtone_internal_call` |
| TCS IVH4222 / Koch VTCH50/2D | `ringtone_floor_call`, `ringtone_entrance_door_call`, `ringtone_internal_call` |
| TCS ISW3330 / Koch TC50 BW | `ringtone_floor_call`, `ringtone_entrance_door_call`, `ringtone_internal_call`, `volume_ringtone`, `volume_handset_door_call` |
| TCS ISW5010 / Koch TC60 | `ringtone_floor_call`, `ringtone_entrance_door_call`, `ringtone_second_entrance_door_call`, `ringtone_internal_call`, `volume_ringtone`, `volume_handset_door_call`, `volume_handset_internal_call` |
| TCS ISW5020 | `ringtone_floor_call`, `ringtone_entrance_door_call`, `ringtone_second_entrance_door_call`, `ringtone_internal_call`, `volume_ringtone`, `volume_handset_door_call`, `volume_handset_internal_call` |
| TCS ISW5030 | `ringtone_floor_call`, `ringtone_entrance_door_call`, `ringtone_second_entrance_door_call`, `ringtone_internal_call`, `volume_ringtone`, `volume_handset_door_call`, `volume_handset_internal_call` |
| TCS ISW5031 | `ringtone_floor_call`, `ringtone_entrance_door_call`, `ringtone_second_entrance_door_call`, `ringtone_internal_call`, `volume_ringtone`, `volume_handset_door_call`, `volume_handset_internal_call` |
| TCS ISW5033 | `ringtone_floor_call`, `ringtone_entrance_door_call`, `ringtone_second_entrance_door_call`, `ringtone_internal_call`, `volume_ringtone`, `volume_handset_door_call`, `volume_handset_internal_call` |
| TCS IVW511x / Koch VTC60/2D / Scantron VIVO | `ringtone_floor_call`, `ringtone_entrance_door_call`, `ringtone_second_entrance_door_call`, `ringtone_internal_call`, `volume_ringtone`, `volume_handset_door_call`, `volume_handset_internal_call` |
| TCS IVW521x | `ringtone_floor_call`, `ringtone_entrance_door_call`, `ringtone_second_entrance_door_call`, `ringtone_internal_call`, `volume_ringtone`, `volume_handset_door_call`, `volume_handset_internal_call` |
| TCS ISW6010 | Verification and implementation required |
| TCS ISW6031 | Verification and implementation required |
| TCS IVW6511 | Verification and implementation required |
| TCS ISW7030 / Koch TC70 | Verification and implementation required |
| TCS IVW7510 / Koch VTC70 | Verification and implementation required |
| TCS ISH7030 / Koch TCH70 | Verification and implementation required |
| TCS IVH7510 / Koch VTCH70 | Verification and implementation required |
| TCS ISWM7000 | Verification and implementation required |
| TCS IVWM7000 | Verification and implementation required |
| TCS ISW4100 / Koch TC31 | Verification and implementation required |
| TCS IMM2100 / Koch TCE31 | Verification and implementation required |
| TCS IVW2210 / Koch Ecoos | Verification and implementation required |
| TCS IVW2211 / Koch Ecoos | Verification and implementation required |
| TCS IVW2212 / Koch Ecoos / Scantron SLIM60T | Verification and implementation required |
| TCS VTC42V2 | Verification and implementation required |
| TCS TC40V2 | Verification and implementation required |
| TCS VTC40 | Verification and implementation required |
| TCS TC40 | Verification and implementation required |
| TCS TC2000 | Verification and implementation required |
| TCS TC20P | Verification and implementation required |
| TCS TC20F | Verification and implementation required |
| TCS ISH3022 | Verification and implementation required |
| TCS ISW3022 | Verification and implementation required |
| TCS IMM1000 / Koch TCH30 | Verification and implementation required |
| TCS IMM1100 / Koch TCHE30 | Verification and implementation required |
| TCS IMM1300 / Koch VTCH30 | Verification and implementation required |
| TCS IMM1310 / Koch VTCHE30 | Verification and implementation required |
| TCS IMM1110 / Koch TCHEE30 | Verification and implementation required |
| TCS IMM1500 | Verification and implementation required |
| TCS IVW2220 / Koch Sky | Verification and implementation required |
| TCS IVW2221 / Koch Sky R1.00 | Verification and implementation required |
| TCS IVW3011 / Koch Skyline Plus | Verification and implementation required |
| TCS IVW3012 / Koch Skyline/Aldup | Verification and implementation required |
| TCS VMH / Koch VMH | Verification and implementation required |
| TCS VML / Koch VML | Verification and implementation required |
| TCS VMF / Koch VMF | Verification and implementation required |
| Jung TKIS | Verification and implementation required |
| Jung TKISV | Verification and implementation required |
| TCS CAIXXXX / Koch CAIXXXX | Verification and implementation required |
| TCS CAI2000 / Koch Carus | Verification and implementation required |
| TCS ISW42X0 | Verification and implementation required |
| TCS IVW9010 | None |
| TCS IVW9011 / Koch VTP10 | None |
| TCS IVW9110 | None |
| TCS IVW9030 / Scantron SLIM50T | None |
| TCS IVE70 | None |

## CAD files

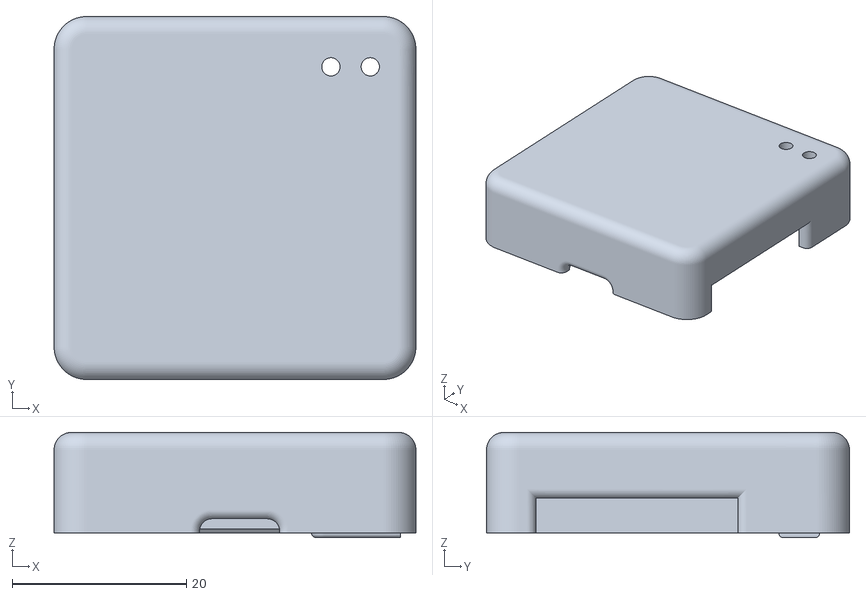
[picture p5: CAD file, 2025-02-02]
enclosure/Top.stl
41.6 x 41.7 x 12.1

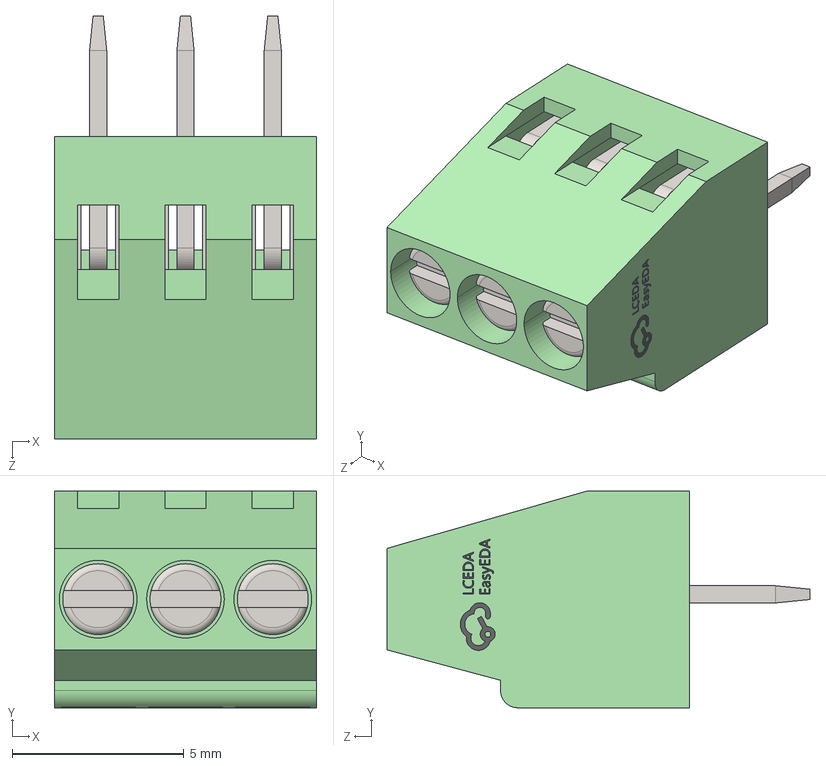
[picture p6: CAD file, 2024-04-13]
pcb/shapes3D/CONN-TH_3P-P2.54_KF128-2.54-3P.step
7.62 x 6.30 x 12.3 mm

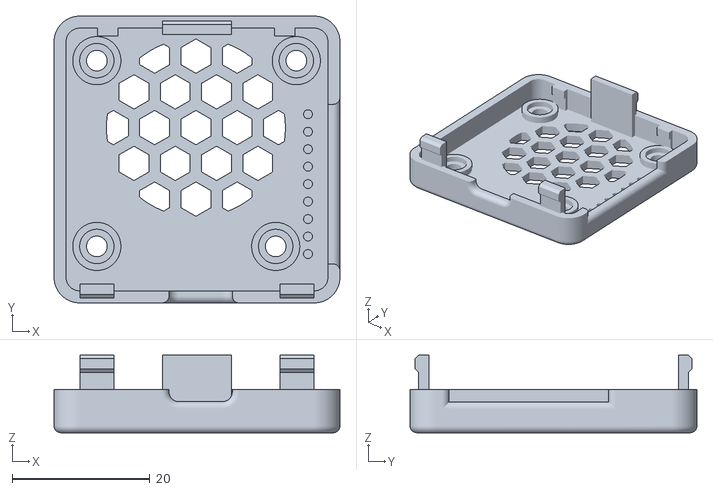
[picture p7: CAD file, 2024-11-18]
enclosure/Bottom.stl
41.6 x 41.7 x 11.3

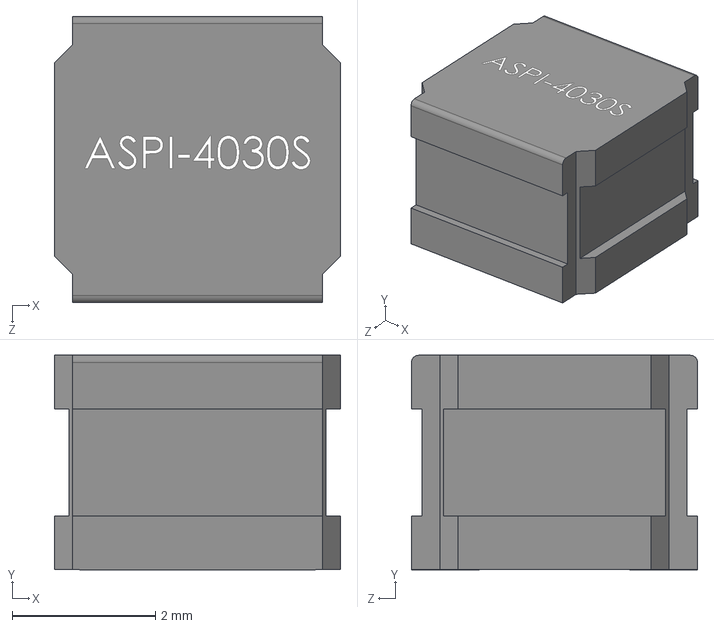
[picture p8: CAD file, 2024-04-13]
pcb/shapes3D/ASPI-4030S-100M-T--3DModel-STEP-400430.STEP
4.00 x 3.00 x 4.00 mm

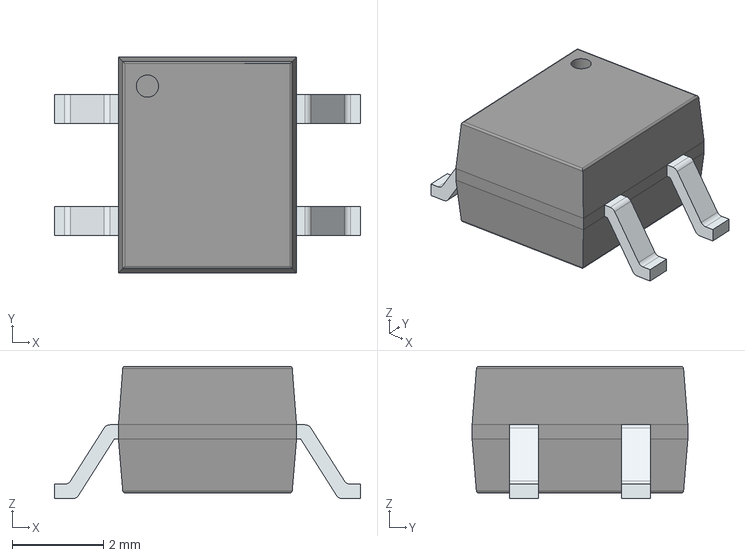
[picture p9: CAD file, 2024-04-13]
pcb/shapes3D/MB2S.step
6.70 x 4.72 x 2.90 mm
PinsArrayLR

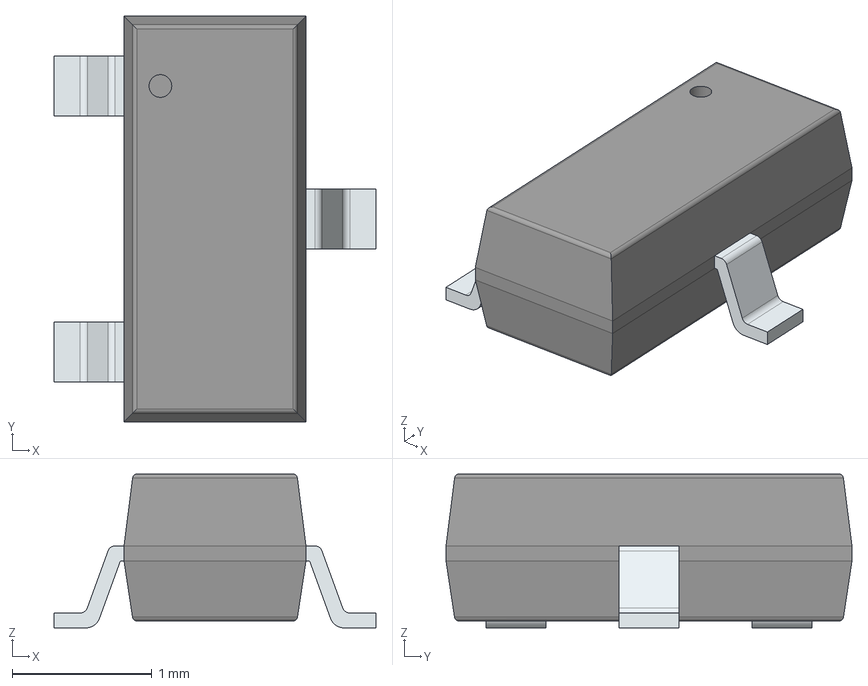
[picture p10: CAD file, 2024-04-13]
pcb/shapes3D/BC817.step
2.30 x 2.90 x 1.10 mm
PinsArrayL
FilletPinR

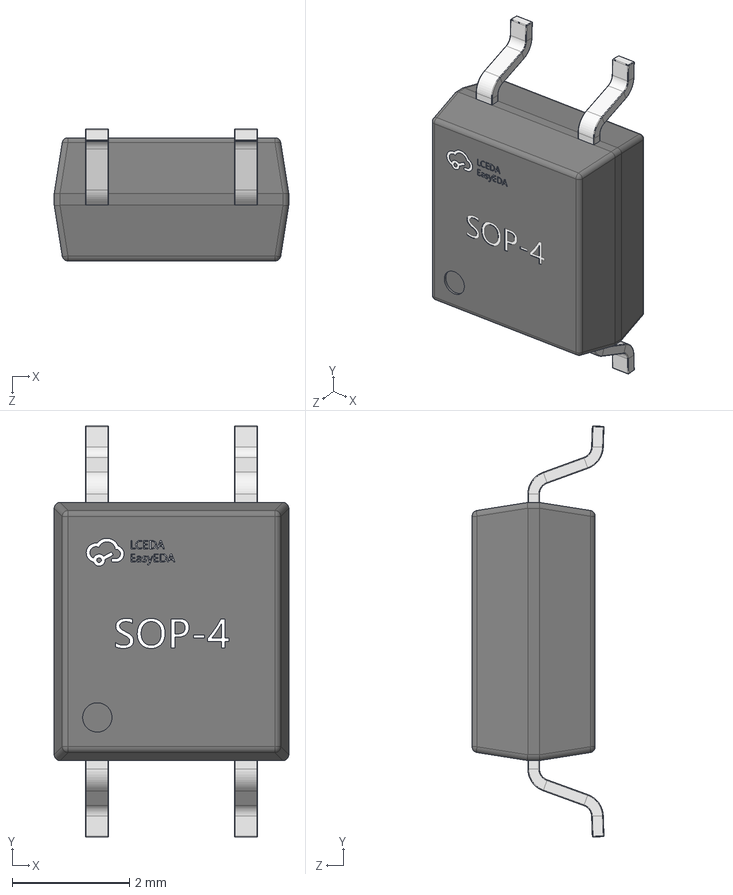
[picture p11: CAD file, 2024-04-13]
pcb/shapes3D/SOP-4_L4.0-W4.4-H2.1-LS7.0-P2.54.step
4.00 x 7.01 x 2.25 mm

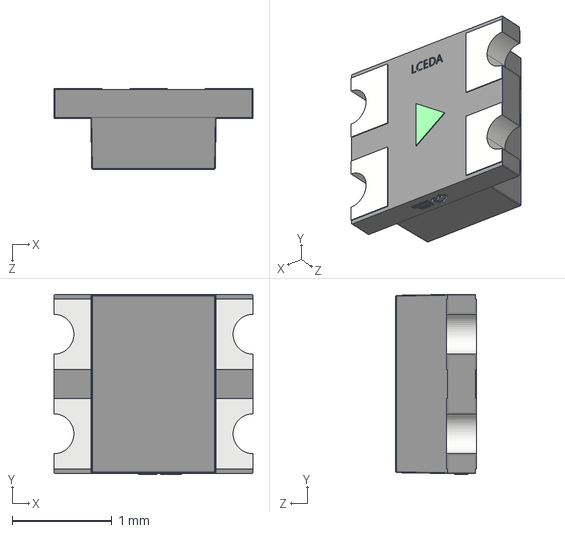
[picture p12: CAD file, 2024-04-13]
pcb/shapes3D/LED-SMD_4P-L2.0-W1.8_CY-0807.step
2.00 x 1.81 x 0.81 mm

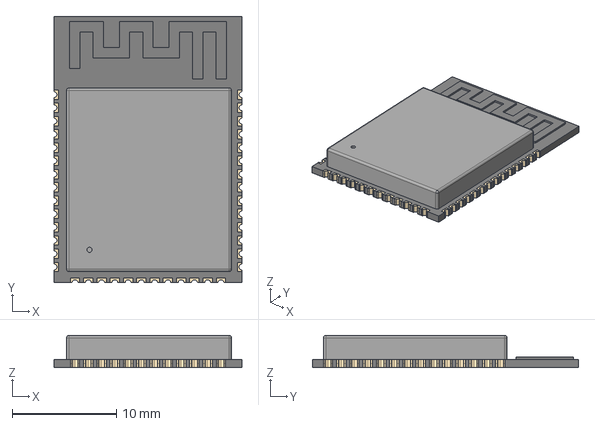
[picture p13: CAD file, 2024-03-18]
pcb/shapes3D/ESP32-S3-WROOM-1.step
18.0 x 25.5 x 3.10 mm

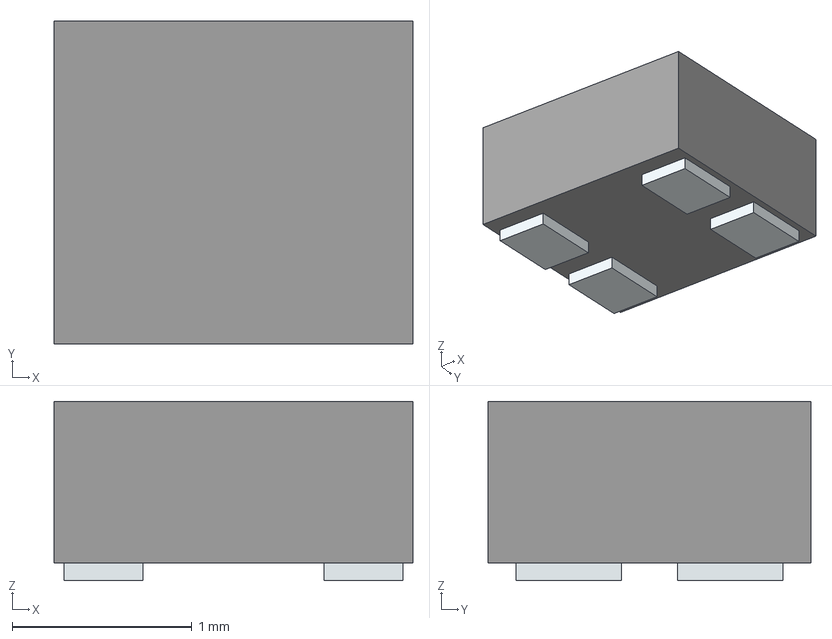
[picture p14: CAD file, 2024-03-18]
pcb/shapes3D/XL-0807RGBC-WS2812B.stp
2.00 x 1.80 x 1.00 mm
Pins

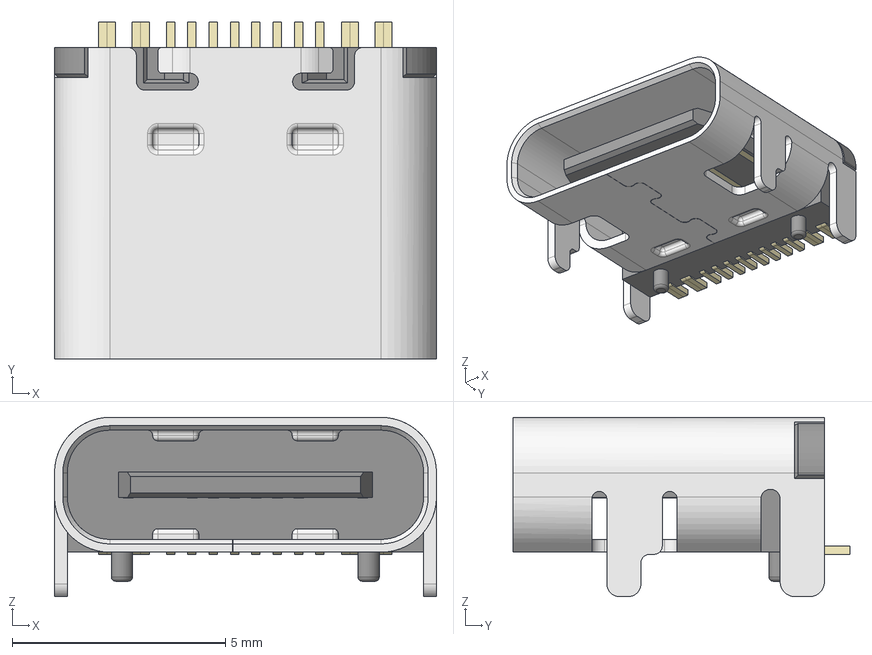
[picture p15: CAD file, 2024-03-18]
pcb/shapes3D/HRO_TYPE-C-31-M-12.step
8.95 x 7.90 x 4.20 mm

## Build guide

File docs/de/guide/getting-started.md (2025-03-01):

# Erste Schritte

Ist das dein erster Besuch hier? Keine Sorge, wir haben alles für dich vorbereitet!
Unten findest du eine ausführliche Anleitung zur Ersteinrichtung deines Doormans.

Bitte beachte, dass diese Anweisungen auf dem bereits geflashten Doorman-PCB basieren welches ich verkaufe.
Sofern du selbst ein PCB produzieren lassen hast, musst du zuerst die Firmware flashen. Solltest du dem nicht nachgehen, kannst du lange warten, dass irgendwas von dem unten beschriebenen passiert. 😄

**Vielen Dank, dass du Doorman verwendest! ❤️**

## Verkabelung
Öffne als Erstes das Gehäuse deiner Innenstation. In den meisten Fällen findest du dort eine Schraubklemme mit den Bezeichnungen `a`, `b`, `E` und `P`.

::: danger VORSICHT
**SCHLIEßE AUF KEINEN FALL EINE EXTERNE STROMQUELLE AN DIE TC:BUS-TERMINALE AN.  
DAS KÖNNTE DAS RICHTIG SCHADEN ANRICHTEN!**
:::

Schließe die `b`-Leitung (Ground) an einen der TC:BUS-Anschlüsse deines Doorman an und die `a`-Leitung (24V Bus) an den anderen TC:BUS-Anschluss deines Doorman. Doorman ist wie jedes andere Gerät am Bus und wird **parallel angeschlossen**.

::: warning HINWEIS
Standardmäßig versende ich Revision 1.5 mit einer Jumper-Kappe auf `BUS PWR`. Bitte entferne diese, sofern du Doorman nicht nach dem Schema `2-Draht-Modus über die Innenstation` anschließt.
:::

### Stromversorgungsoptionen:
::: details 3-Draht-Modus über die Innenstation <Badge type="tip" text="Empfohlen" />
Verbinde die `P`-Leitung (+24V) mit dem `P`-Terminal an deinem Doorman.

> [!WARNING]
> Die Stromversorgung der Gegensprechanlage muss mindestens 60mA liefern.

Beispiel:
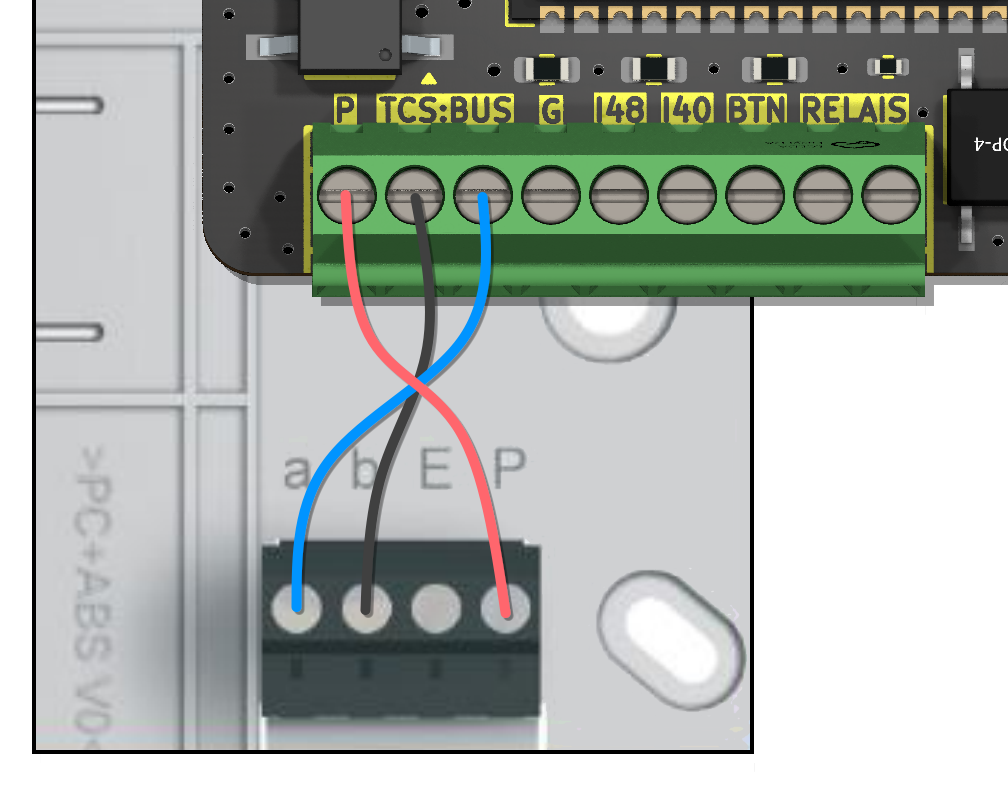
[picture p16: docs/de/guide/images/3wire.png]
3-wire

:::

::: details 2-Draht-Modus über externe Stromversorgung
Schließe die externe Stromversorgung an deinen Doorman an. Nutze dazu die `P` (+5V bis +30V) und `G` (Ground) Schraubklemmen an deinem Doorman.

Beispiel:
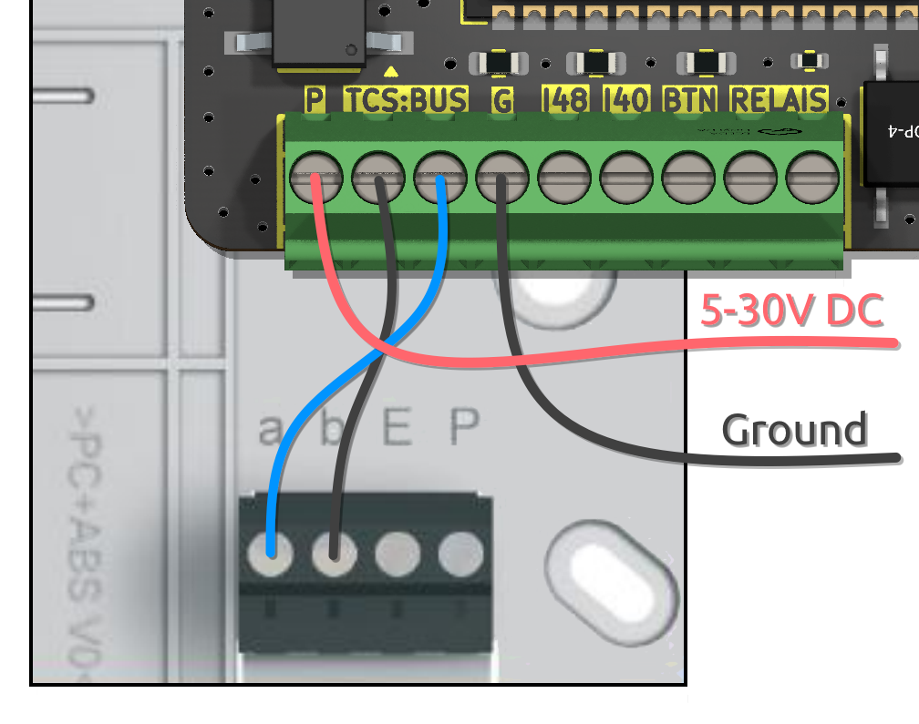
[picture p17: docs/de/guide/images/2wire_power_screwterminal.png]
2-wire external via screw terminal

:::

::: details 2-Draht-Modus über externe USB-C-Stromversorgung
Schließe die externe Stromversorgung über den USB-C-Anschluss an.

Beispiel:
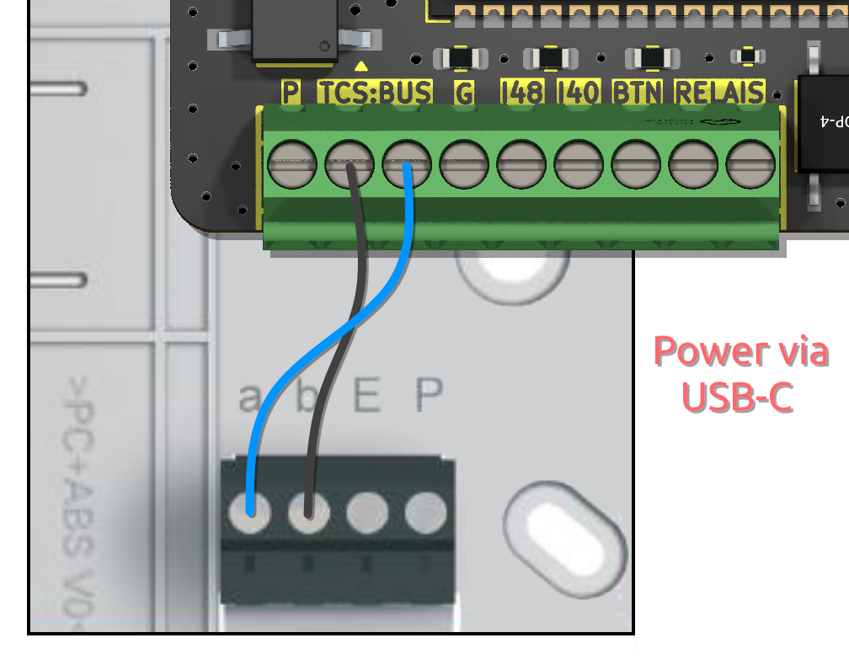
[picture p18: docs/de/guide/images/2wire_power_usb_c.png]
2-wire external via usb

:::

::: details 2-Draht-Modus über die Innenstation <Badge type="danger" text="Hardware Revision 1.5 und neuer" />
> [!DANGER] Wichtig
> Die Nutzung der `a`-Bus-Leitung als Stromquelle bei älteren Hardware Revisionen als `1.5` führt zu einem lauten Piepton. Dieses Problem tritt wahrscheinlich aufgrund der Hochfrequenz-Schaltstromversorgung auf.
>
> Ab Hardware Revision `1.5` erzeugt diese Methode nur noch ein leises, aber dennoch wahrnehmbares Rauschen im Lautsprecher.

Nachdem du die `a` und `b` Leitung angeschlossen hast musst du noch `BUS PWR` mittels Jumper Kappe verbinden.

Beispiel:
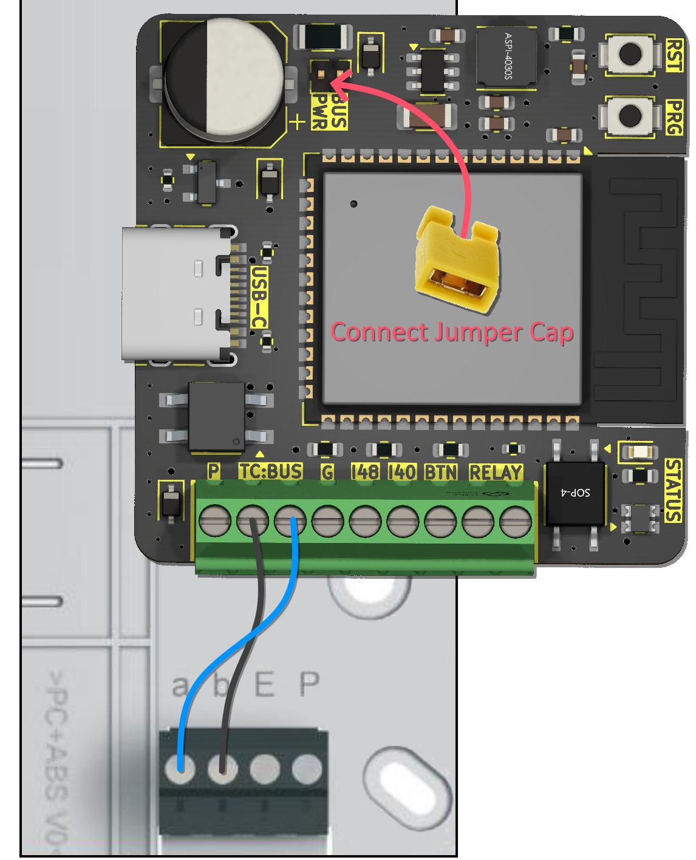
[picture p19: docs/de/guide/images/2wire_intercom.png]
2-wire via intercom jumper

:::

## Einrichtung

### Schritt 1: Mit Wi-Fi verbinden
Wenn du deinen Doorman-S3 zum ersten Mal einschaltest, wird er schnell (orange) blinken und einen neuen Access Point namens `Doorman-S3 Setup` erstellen. Du kannst deine WiFi-Zugangsdaten über den Access Point, Improv Serial oder Improv Bluetooth einrichten.

Das Passwort für den Access Point lautet `open-sesame`.

Sobald du mit dem Access Point verbunden bist, sollte sich die Web-Oberfläche automatisch öffnen (siehe auch Netzwerk-Benachrichtigungen).\
Falls nicht, kannst du manuell zu http://192.168.4.1/ in deinem Browser navigieren.

::: tip
Wenn dein Home Assistant Bluetooth aktiviert hat, kannst du die automatische Einrichtung nutzen.

Dank mDNS-Unterstützung wird Home Assistant deinen Doorman automatisch entdecken, sobald er mit dem WiFi verbunden ist.
:::
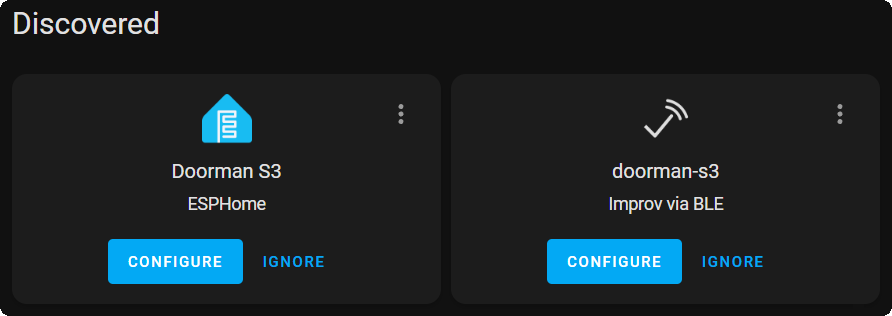
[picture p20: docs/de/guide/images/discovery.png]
Home Assistant Discovery


### Schritt 2: Mit Home Assistant verbinden
Nachdem du deinen Doorman mit deinem Netzwerk verbunden hast, wird die RGB Status LED langsam (blau) blinken. Er sollte automatisch von Home Assistant entdeckt werden. Klicke einfach auf `Konfigurieren`, um das neu entdeckte ESPHome-Gerät hinzuzufügen.

Falls nicht, kannst du ihn manuell per IP Addresse hinzufügen.

Nach erfolgreicher Verbindung leuchtet er für 3 sekunden lang durchgehend blau.

### Schritt 3: Interaktive Einrichtung
::: tip
Wenn du deinen Doorman zum ersten Mal mit Home Assistant verbindest,\
befindet er sich bereits im `Setup Mode` für die interaktive Einrichtung.

Du musst den Modus nicht manuell aktivieren; er wird bei jedem Neustart automatisch gestartet, solange der Einrichtungsprozess nicht abgeschlossen oder abgebrochen wurde.
:::

1. **Zugriff auf die Einstellungen:**
   Öffne die Einstellungen entweder über die Weboberfläche deines Doormans oder besuche die [ESPHome Integrationsseite](https://my.home-assistant.io/redirect/integration/?domain=esphome) und wähle das Doorman S3-Gerät aus.

2. **Aktiviere den Setup-Modus:**  
   Geh zum Bereich `Konfiguration` und schalte den `Setup-Modus` ein, um mit der interaktiven Einrichtung zu beginnen.  
   Sobald der Setup-Prozess beginnt, wird die RGB-Status-LED grün-türkis pulsieren.

::: warning BEVOR DU WEITERMACHST
Deine Innenstation muss angeschlossen und das Gehäuse verschlossen sein, damit die Einrichtung abgeschlossen werden kann.
:::

3. **Warte, bis du auf die Klingel drückst:**  
   Wenn du den Klingelknopf an deiner Wohnung oder am Eingang drückst, speichert das System die Seriennummer deiner Innenstation und versucht, das Modell zu erkennen.

   Sobald das Modell erfolgreich erkannt wurde, wird der Speicher deiner Innenstation ausgelesen.  
   **Hinweis:** Der gesamte Prozess kann **bis zu 30 Sekunden** dauern.

   Wenn das Modell erfolgreich erkannt wurde oder die Zeit abläuft, wird die Einrichtung abgeschlossen.

4. **Einrichtung abgeschlossen:**  
   Die LED leuchtet 3 Sekunden lang grün-türkis und geht dann aus, der Setup-Modus wird deaktiviert. Die Einrichtung ist abgeschlossen.

Wenn du mehrere Außenstationen hast, wird die Firmware versuchen, die zusätzliche Station automatisch zu erkennen.
Um die Erkennung der zweiten Türklingel und das Öffnen der zweiten Tür zu ermöglichen, musst du die zweite Türklingel einmal betätigen oder den physischen Entsperrknopf der zweiten Tür mindestens einmal betätigen, damit die Adresse gespeichert wird.

::: tip MEHRERE INNENSTATIONEN
Wenn du mehrere Innenstationen hast, wird's etwas tricky. Du musst dann eine eigene YAML-Konfiguration erstellen, damit alle zusammen funktionieren. Die Standard-Firmware kann nämlich nur mit einer Innenstation umgehen.
:::

## ESPHome adoption
Wenn du die Firmware deines Doorman anpassen möchtest, kannst du diesen zu deinem [ESPHome-Dashboard](https://my.home-assistant.io/redirect/supervisor_ingress/?addon=5c53de3b_esphome) hinzufügen und deine angepasste [Stock](firmware/stock-firmware.md) oder [Nuki Bridge](firmware/nuki-bridge-firmware.md) Firmware flashen.

Nach dem Hinzufügen wird deine Konfiguration ungefähr so aussehen:
::: details Beispiel
> [!NOTE]
> Hier kannst du neue Komponenten hinzufügen und bestehende ändern. Weitere Informationen zu den Möglichkeiten findest du im Abschnitt [Beispiele](firmware/stock-firmware#beispiele).
>
> Wenn du die Firmware vollständig anpassen möchtest, solltest du die `base.yaml`-Datei aus dem Repository verwenden.

```yaml
<!--@include: ./firmware/minimal.example.yaml-->
```
:::

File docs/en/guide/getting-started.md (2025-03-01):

# Getting Started

Is this your first time here? Don't worry, we've got you covered!
Below, you'll find a detailed guide for setting up your Doorman for the first time.

Please note that these instructions are based on the pre-flashed Doorman PCB that I sell. If you've had a PCB manufactured yourself, make sure to flash the firmware first; otherwise, you might be waiting a long time for anything described below to happen. 😄

**Thank you so much for using Doorman! ❤️**

## Wiring
First, open your indoor station enclosure. On most models, you will find a screw terminal labeled with `a`, `b`, `E`, and `P`.

::: danger
**NEVER CONNECT AN EXTERNAL POWER SOURCE TO THE TC:BUS TERMINALS  
DOING SO CAN CAUSE SEVERE DAMAGE.**
:::

Connect the `b` line (Ground) to one of the TC:BUS terminals on your Doorman, and connect the `a` line (24V Bus) to the other TC:BUS terminal on your Doorman. Doorman is just like any other device on the bus, **connected in parallel**.

::: warning NOTE
By default, I ship version 1.5 with a jumper cap on `BUS PWR`. Please remove this if you are not connecting Doorman in the `2-Wire Mode via indoor station` configuration.
:::

### Power supply options:
::: details 3-Wire Mode via indoor station <Badge type="tip" text="Recommended" />
Connect the `P` line (+24V) to the `P` terminal on your Doorman.

> [!WARNING]
> The intercom power supply must provide at least 60mA.

Example:
3-wire
:::

::: details 2-Wire Mode via external wired Power Supply
Connect the external power supply to your Doorman using the `P` (+5V to +30V) and `G` (Ground) screw terminals.

Example:
2-wire external via screw terminal
:::

::: details 2-Wire Mode via external USB-C Power Supply
Connect the external power supply via the USB-C port.

Example:
2-wire external via usb
:::

::: details 2-Wire Mode via indoor station <Badge type="danger" text="Hardware revision 1.5 and later" />
> [!DANGER] Important Info
> Using the `a`-bus line as a power source on revisions older than `1.5` results in a loud beeping noise. This issue is likely due to the high-frequency switching power supply.
>
> Starting with revision `1.5` this method will only produce a subtle, yet noticeable hissing sound on the speaker.

After connecting the `a` and `b` lines, you need to connect `BUS PWR` using a jumper cap.

Example:
2-wire via bus pwr jumper
:::

## Setup

### Step 1: Connect to Wi-Fi
When you power on your Doorman-S3 for the first time, it will blink rapidly (orange) and create a new Access Point named `Doorman-S3 Setup`. You can set up your WiFi credentials using the Access Point, Improv Serial, or Improv Bluetooth.

The Access Point password is `open-sesame`.

Once connected to the Access Point, the web interface should open automatically (see also login to network notifications).\
If it doesn't, you can manually navigate to http://192.168.4.1/ in your browser.

::: tip
You can take advantage of automatic setup in Home Assistant if your Home Assistant has Bluetooth enabled.

Additionally, with mDNS support, Home Assistant will automatically discover your Doorman once it's connected to WiFi.
:::
Home Assistant Discovery

### Step 2: Connect to Home Assistant
After connecting Doorman to your network, it will blink slowly (blue) and should be automatically discovered by Home Assistant. Simply click on `Configure` to add the newly discovered ESPHome node.

### Step 3: Interactive Setup
::: tip
When you first connect your Doorman to Home Assistant, it will be in `Setup Mode` for interactive setup already.

You don't need to manually activate this mode; it will start automatically at each reboot as long as the setup process has not been completed or canceled.
:::

1. **Access the Settings:**  
   Open the settings either through your Doorman's Webinterface or visit the [ESPHome Integration page](https://my.home-assistant.io/redirect/integration/?domain=esphome) and select the Doorman S3 device.

2. **Activate Setup Mode:**  
   Go to the `Configuration` section and enable `Setup Mode` to begin the interactive setup.  
   Once the setup process begins, the RGB status LED will pulse green-turquoise.

::: warning BEFORE YOU PROCEED
The indoor station must be connected, and the enclosure securely closed, to complete the setup process.
:::

3. **Wait until you ring the doorbell:**  
    When you press the doorbell button at your apartment or entrance, the system will save your indoor station's serial number and attempt to detect the model.

    Once the model is successfully detected, the system will read the memory of your indoor station.
    **Note:** This entire process can take **up to 30 seconds**.

    If the model detection is successful or if it times out, the setup will be considered finished.

4. **Setup complete:**  
   The LED will remain green-turquoise for 3 seconds, then turn off, and the setup mode will be turned off. The setup is complete.

If you have multiple door stations, the firmware will attempt to automatically detect the additional station.
To enable detection of the second doorbell and the ability to unlock the second door, you need to press the second doorbell or physically push the unlock button for the second door at least once to store its address.

::: tip MULTIPLE INDOOR STATIONS
If you have multiple indoor stations, things become a bit more complex. You'll need to create a custom YAML configuration to integrate all the indoor stations. The default firmware only supports a single indoor station.
:::

## ESPHome adoption

If you want to customize your Doorman firmware, you can add the Doorman device to your [ESPHome Dashboard](https://my.home-assistant.io/redirect/supervisor_ingress/?addon=5c53de3b_esphome) and flash your customized [Stock](firmware/stock-firmware.md) or [Nuki Bridge](firmware/nuki-bridge-firmware.md) firmware.

After adding the device, your configuration will look like this:
::: details Example
> [!NOTE]
> You can add new components and modify existing ones here. For more information on the possibilities, check out the [Examples](firmware/stock-firmware#examples) section.
>
> If you need to deeply customize the firmware, you'll need to use the `base.yaml` file from the repository.

```yaml
<!--@include: ./firmware/minimal.example.yaml-->
```
:::

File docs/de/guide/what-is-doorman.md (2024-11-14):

PCB front and back

# Was ist Doorman?

Doorman ermöglicht es dir, deine [TCS](https://www.tcsag.de/) oder [Koch](https://www.kochag.ch/) Gegensprechanlage mit jedem Heimautomatisierungssystem zu verbinden. Zusätzlich sind einige umgebrandete [Niko](https://www.niko.eu/), [Scantron](https://scantron.dk/) und ältere [Jung](https://www.jung-group.com/) Gegensprechanlagen Gegenstücke zu den TCS- und Koch-Modellen.

### Was ist mit anderen Gegensprechanlagen?
Doorman ist nicht auf TCS- oder Koch-Gegensprechanlagen beschränkt.\
Du kannst ihn auch verwenden, um einen Tastendruck zu simulieren und damit einen Türöffner oder Licht mit dem integrierten Solid-State-Relais (bis zu 40V, max. 2,5A) auszulösen.

Wenn deine Gegensprechanlage auf einem 2-Draht-Bus im Bereich von 14-24V DC arbeitet, könnte es möglich sein, auch andere Protokolle zu implementieren.

Alternativ kannst du den Spannungspegel auf älteren Gegensprechanlagen (14-24V DC) mithilfe des internen ADC überwachen und spezifische Aktionen basierend auf den Messwerten auslösen.

<div class="tip custom-block" style="padding-top: 8px">

Du hast gerade deinen Doorman erhalten? Geh direkt zur [Quickstart](getting-started) Anleitung.

</div>

## Features

- ESP32-S3 mit Dual-Core-CPU, integriertem PSRAM und Bluetooth 
- USB-C Anschluss zum einfachen Flashen (und weil USB-C einfach cool ist 😎)
- Kompaktes Design, das fast überall passt
- Einstellbare WS2812B RGB LED zur Anzeige bestimmter Ereignisse
- Zwei zusätzliche GPIOs zur einfachen Erweiterung mit eigenen Sensoren und Geräten (z.B. I²C)
- Solid-State-Relais zum Schalten von Lasten bis zu 40V (max. 2,5A), ideal für ältere Gegensprechanlagen
- Externer Button (G + BTN)
- Brückengleichrichter zur Korrektur der Bus-Leitung-Polarität
- TC:BUS-Kommunikation für Funktionen wie das Öffnen der Haustür und das Erkennen der Klingel
- Kann als Nuki Bridge mit der [Nuki Bridge Firmware](firmware/nuki-bridge-firmware) verwendet werden. Beachte, dass diese Firmware nicht mit der Nuki App kompatibel ist, aber mit der Home Assistant App funktioniert.

## Möchtest du auch einen?

Wenn du Fragen hast, kannst du mich gerne auf [Discord](https://discord.gg/t2d34dvmBf) oder per [E-Mail](mailto:flo@azon.ai?subject=Doorman) erreichen.

Ich habe auch vollständig gelötete und getestete Doorman-S3 im Angebot, die schon mit der [Stock Firmware](firmware/stock-firmware) geflasht sind. Diese können direkt in Home Assistant integriert werden.

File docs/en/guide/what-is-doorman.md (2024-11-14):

PCB front and back

# What is Doorman?

Doorman allows you to connect your [TCS](https://www.tcsag.de/) or [Koch](https://www.kochag.ch/) intercom to any home automation system. Additionally, some rebranded [Niko](https://www.niko.eu/), [Scantron](https://scantron.dk/) and older [Jung](https://www.jung-group.com/) intercoms are counterparts to the TCS and Koch models.

### What about other intercoms?
Doorman isn't limited to TCS or Koch intercoms.\
You can use it to simulate a button press to trigger a door opener or light with the integrated solid-state relay (up to 40V, max 2.5A).

If your intercom operates on a 2-wire bus within the 14-24V DC range, it might be possible to implement other protocols as well.

You can also monitor the voltage level on older intercoms (14-24V DC) using the internal ADC and trigger specific actions based on the readings.

<div class="tip custom-block" style="padding-top: 8px">

Just received your Doorman? Jump to the [Quickstart](getting-started) guide.

</div>

## Features

- Powered by ESP32-S3
- USB-C port for easy flashing (and because USB-C is cool 😎)
- Compact design that fits almost anywhere
- Configurable WS2812B RGB LED to indicate specific events
- Two additional GPIOs for easy expansion with your own sensors and devices (e.g., I²C)
- Solid-state relay for switching up to 40V (max. 2.5A), ideal for older intercom systems
- External Button (G + BTN)
- Bridge rectifier for bus-wire input to correct polarity
- TC:BUS communication for functions like opening the front door and detecting the doorbell
- Can be used as a Nuki Bridge with the [Nuki Bridge Firmware](firmware/nuki-bridge-firmware). Note that this firmware is incompatible with the Nuki app, but it works with the Home Assistant app.

## Interested in Buying One?

Feel free to contact me on [Discord](https://discord.gg/t2d34dvmBf) or via [E-Mail](mailto:flo@azon.ai?subject=Doorman).

I offer fully assembled and tested Doorman-S3 units with the [Stock Firmware](firmware/stock-firmware) pre-installed, ready for direct integration and adoption into Home Assistant.

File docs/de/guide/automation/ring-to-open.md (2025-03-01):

# Ring To Open <Badge type="warning" text="Party Mode" />

Die Doorman-Firmware bietet eine **Ring To Open**-Automation, die früher als **Party Mode** bekannt war.

### Was macht es?
Wie der Name schon sagt, öffnet sich die Eingangstür automatisch, wenn jemand die Türklingel betätigt. Diese Funktion ist besonders nützlich während einer Party, da Gäste einfach durch Klingeln das Gebäude betreten können.

### Wie benutze ich es?
Du kannst die Ring To Open-Automation entweder über den Schalter in Home Assistant umschalten oder durch Ausführen des `Function Button` Commands.

#### Konfigurationsoptionen:
::: info Confirmation
Wenn du diese Einstellung aktivierst, wird deine Wohnungs-Klingel jedes Mal klingeln, wenn du die Ring To Open-Automation per Befehl (Funktionstaste) aktivierst.
:::

::: info Delay
Diese Einstellung erlaubt es dir, eine Verzögerung für den Türöffner zu konfigurieren. Wenn du die Verzögerung auf 60 Sekunden einstellst, wird bei jeder Ausführung der Automation zufällig eine Verzögerung zwischen 5 und 15 Sekunden ausgewählt.
:::

::: info Timeout
Du kannst die Ring To Open-Automation nach 5 bis 60 Minuten, nach einem einzigen Klingeln oder nie automatisch deaktivieren.
:::

::: info Door Station
Du kannst entscheiden welche Außenstelle (Tür) die Automation auslöst.
:::

::: info Display Status
Du kannst entscheiden ob die Status LED blinkt während die Automation aktiv ist.
:::

::: info Toggle Trigger
Du kannst entscheiden durch was die Automation umgeschaltet wird.
:::

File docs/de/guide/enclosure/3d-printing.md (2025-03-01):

# Gehäuse

Falls du ein Gehäuse benötigst, kannst du dein eigenes drucken.\
Klicke [hier](https://github.com/azoninc/doorman/blob/master/enclosure) um die STL-Dateien von GitHub herunterzuladen.

::: tip
Da die STL-Dateien für Resin-Drucker optimiert sind, erzielst du mit einem solchen die besten Ergebnisse.
:::

## Interaktiver Viewer
### Deckel
<ClientOnly>
    <div style="aspect-ratio: 16/9; height: auto; margin: 2rem 0; border-radius: 8px; overflow:hidden;">
      <ModelViewer file="https://raw.githubusercontent.com/azoninc/doorman/master/enclosure/Top.stl" />
    </div>
</ClientOnly>

### Gehäuseboden
<ClientOnly>
    <div style="aspect-ratio: 16/9; height: auto; margin: 2rem 0; border-radius: 8px; overflow:hidden;">
      <ModelViewer file="https://raw.githubusercontent.com/azoninc/doorman/master/enclosure/Bottom.stl" />
    </div>
</ClientOnly>

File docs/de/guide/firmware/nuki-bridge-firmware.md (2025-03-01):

# Nuki Bridge Firmware <Badge type="tip" text="ESP-IDF Framework" />

Diese Konfiguration übernimmt alle Funktionen der Stock Firmware und fügt eine [Nuki Bridge](https://github.com/uriyacovy/ESPHome_nuki_lock)-Komponente über BLE hinzu. Beachte, dass Improv über Bluetooth LE nicht unterstützt wird, da der BLE-Stack von der Nuki Bridge-Komponente verwendet wird.

## Firmware installieren oder aktualisieren

Es gibt verschiedene Möglichkeiten, die Firmware zu aktualisieren.

::: warning WARNUNG
Manche **Updates können Breaking Changes mit sich bringen** — lies dir die Changelogs immer genau durch, damit dein System auch in wichtigen Situationen zuverlässig funktioniert.  
:::

#### Web Serial <Badge type="tip" text="Neueste Release-Version, keine Anpassungen" />
Verbinde deinen **Doorman-S3** per USB-C und klicke auf den Button unten, um die neueste Firmware direkt über Web Serial zu installieren oder zu aktualisieren. So kannst du das Gerät nahtlos mit der Home Assistant API nutzen und zukünftig einfach Community-Updates einspielen.

<esp-web-install-button manifest="../../../firmware/release/esp32-s3.ha.nuki-bridge/manifest.json">
    <button slot="activate">
        <div class="custom-layout">
            <a class="btn">Firmware (Doorman-S3) installieren oder updaten</a>
        </div>
    </button>
    <div slot="unsupported">
        <div class="danger custom-block">
            <p class="custom-block-title">OH NEIN!</p>
            <p>Dein Browser unterstützt leider kein Web Serial :(</p>
        </div>
    </div>
    <div slot="not-allowed">
        <div class="danger custom-block">
            <p class="custom-block-title">OH NEIN!</p>
            <p>Das funktioniert mit HTTP nicht :(</p>
        </div>
    </div>
</esp-web-install-button>

#### HTTP OTA-Updates <Badge type="tip" text="Neueste Release-Version, keine Anpassungen" />  
Wenn du Doorman in Home Assistant hinzugefügt hast, kannst du von automatisierten Firmware-Builds und einfachen Updates profitieren. Das Update erscheint direkt in deiner Update-Liste – ein Klick auf den Update-Button genügt, und das OTA-Update startet sofort. Einfach, effizient und stressfrei.

#### ESPHome CLI / Dashboard <Badge type="warning" text="Vollständige Anpassung" />  
Für maximale Kontrolle und individuelle Anpassungen kannst du die Firmware in dein ESPHome Dashboard übernehmen oder das ESPHome CLI nutzen, indem du folgenden Befehl ausführst:  
`esphome run <yamlfile.yaml>`  

Falls du lieber die MQTT-Only-Firmware verwenden möchtest, nutze einfach das passende MQTT-Beispiel-YAML für dein Board unten.

##### Board Konfigurationsoptionen:

::: details Doorman-S3 (1.5) / ESP32-S3 (Octal PSRAM)
::: code-group
```yaml [Home Assistant]
<!--@include: ../../../../firmware/examples/esp32-s3.ha.stock.master.example.yaml-->
```
```yaml [MQTT]
<!--@include: ../../../../firmware/examples/esp32-s3.mqtt.stock.master.example.yaml-->
```
:::

::: details Doorman-S3 (1.4) / ESP32-S3 (Quad PSRAM)
::: code-group
```yaml [Home Assistant]
<!--@include: ../../../../firmware/examples/esp32-s3-quad.ha.stock.master.example.yaml-->
```
```yaml [MQTT]
<!--@include: ../../../../firmware/examples/esp32-s3-quad.mqtt.stock.master.example.yaml-->
```
:::

::: details Generic ESP32
#### GPIO Konfiguration
- **TC:BUS RX:** GPIO 22
- **TC:BUS TX:** GPIO 23
- **Status LED:** GPIO 2
- **RGB Status LED:** GPIO 4
- **Relay:** GPIO 21
- **External button:** GPIO 20
- **ADC Input:** GPIO 36

::: code-group
```yaml [Home Assistant]
<!--@include: ../../../../firmware/examples/esp32.ha.stock.master.example.yaml-->
```
```yaml [MQTT]
<!--@include: ../../../../firmware/examples/esp32.mqtt.stock.master.example.yaml-->
```
:::

::: details Generic ESP8266
#### GPIO Konfiguration
- **TC:BUS RX:** GPIO 12
- **TC:BUS TX:** GPIO 13
- **Status LED:** GPIO 2
- **RGB Status LED:** Dummy
- **Relay:** GPIO 14
- **External button:** GPIO 15
- **ADC Input:** A0

::: code-group
```yaml [Home Assistant]
<!--@include: ../../../../firmware/examples/esp8266.ha.stock.master.example.yaml-->  
```
```yaml [MQTT]  
<!--@include: ../../../../firmware/examples/esp8266.mqtt.stock.master.example.yaml-->  
```
:::

## Nuki Smart Lock koppeln

::: warning WARNUNG
Wenn dein Smart Lock bereits gekoppelt ist, wird es durch diesen Vorgang entkoppelt!
:::

Drücke je nach PCB-Revision entweder die FLASH- oder PRG-Taste auf der Doorman-S3 Platine für 5 Sekunden, bis die Status-LED lila zu blinken beginnt, oder aktiviere den Nuki Pairing Mode-Schalter in Home Assistant / ESPHome Weboberfläche. Drücke dann die Taste an deinem Smart Lock für 5 Sekunden, bis der Leuchtring aufleuchtet.

Nach erfolgreicher Kopplung bleibt die Status-LED für 3 Sekunden konstant an und schaltet sich dann aus.

## Nuki Smart Lock entkoppeln

Du kannst dein Smart Lock entweder über den `Nuki Unpair Device`-Button in Home Assistant / ESPHome Weboberfläche oder die physische `FLASH`- oder `PRG`-Taste auf der Doorman-S3 Platine entkoppeln.

::: info Physische Taste
Falls dein Smart Lock bereits mit Doorman gekoppelt ist, drücke die `FLASH`- oder `PRG`-Taste auf der Doorman-S3 Platine für 5 Sekunden, bis die RGB-Status-LED lila zu blinken beginnt. Dein Smart Lock wird dann entkoppelt. Beachte, dass der Pairing-Modus nach 30 Sekunden abläuft.
:::

<!--@include: ./additions.md-->

<!--@include: ./mqtt.md-->

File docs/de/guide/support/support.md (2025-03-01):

# Support

If you're experiencing issues with your Doorman, help is available through several channels:

- The below troubleshooting guide covers many common issues
- The [Discord server](https://discord.gg/t2d34dvmBf) is a great place to get assistance from me and the community
- The [GitHub issues](https://github.com/azoninc/doorman/issues) may contain solutions to problems you're encountering

Please note that support is provided on a best-effort basis. While I will assist as much as possible, please understand that I may not be able to help immediately or with every situation, as this is not my full-time job. Thank you for your understanding.

## Common Issues

::: details Web Serial (Flashing via ESP Web Tools) Connect-Disconnect loop
If you've received a Doorman-S3 PCB that hasn't been pre-flashed with the [Stock Firmware](../firmware/stock-firmware.md), the ESP will not have any firmware installed. As a result, it will enter a continuous restart loop by default, making it impossible to flash using ESP Web Tools or any other tool.

#### Solution
To resolve this, hold down the button labeled `FLASH` while connecting the USB cable to your computer. This will put the ESP into bootloader mode, preventing it from constantly restarting.
:::

::: details A loud beeping noise occurs on the phone
Please take a look [here](../hardware-compatibility#bekannte-probleme).
:::

::: details Home Assistant can't connect / BAD_INDICATOR errno=11
If Home Assistant can't connect to your Doorman, or you are receiving the error Reading failed: BAD_INDICATOR errno=11 in the logs, this indicates Home Assistant may be trying to connect with an incorrect encryption key.

First, try restarting Home Assistant entirely to see if the issue persists. If it does, here are some things to try based on how you manage your Doorman's firmware updates.

#### OTA Updates / Firmware Binary

The pre-compiled firmware binaries that are used for OTA updates do not have an API encryption key built-in, therefore Home Assistant must be attempting to connect with an encryption key or deprecated API password. To remedy this, please try removing the integration entry for your Doorman by going to Settings > Devices & Services, then remove the ESPHome integration for your Doorman there. Then re-add your Doorman to Home Assistant by creating a new ESPHome integration using the device's IP or hostname. Do not specify an encryption key or password if prompted.

#### ESPHome Dashboard

If you manage updates with an ESPHome YAML, you must make sure that the encryption key you specify in the api: section of your configuration matches the encryption key that Home Assistant uses. Try re-adding the integration to Home Assistant, and make sure to specify the encryption key when prompted. You may also try removing the encryption key from your configuration to see if this remedies the issue. If it does, this may indicate an issue with Home Assistant or ESPHome itself.
:::

::: details Receiving commands does not work
If your Doorman is unable to receive commands there could be several reasons.

#### Check the wiring
Please make sure you wired everything correctly.\
You can find the guide [here](../getting-started#verkabelung).

#### Check the Bus voltage
There are cases where the bus voltage is inusfficient and causing the reading to fail.\
This can happen when other devices are drawing too much current.

You can check the a+b Bus voltage when receiving commands using an oscillosope.
If the bus voltage constantly goes up and down there's an issue with the power draw of other bus participants.
:::

## Other Issues

If you are experiencing other issues, here are some things to try:

- Reflash the firmware [here](../firmware/stock-firmware).

If everything else fails, please join the [Discord server](https://discord.gg/t2d34dvmBf) for support. If necessary, we will work to triage an issue on the GitHub repository.

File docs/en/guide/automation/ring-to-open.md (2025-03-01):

# Ring To Open <Badge type="warning" text="Party Mode" />

The Doorman firmware features a Ring To Open automation, which was previously known as Party Mode.

### What does it do?
As the name implies, the entrance door will open automatically when someone rings the doorbell.
This feature is especially useful during a party, allowing guests to enter the building simply by ringing the bell.

### How do I use it?
You can enable or disable the Ring To Open automation using the switch in Home Assistant or by issuing the `Function Button` command.

#### Configuration Options:
::: info Confirmation
If you enable this setting, your apartment doorbell will ring each time you activate the Ring To Open automation via command (function button).
:::

::: info Delay
This setting allows you to configure a delay for the door opener. If you set the delay to 60 seconds, it will randomly select a delay between 5 and 15 seconds whenever the automation is executed.
:::

::: info Timeout
You can choose to disable the Ring To Open automation after 5 to 60 minutes, after a single ring, or never.
:::

::: info Door Station
You can choose which door station will trigger the automation.
:::

::: info Display Status
You can choose whether the status LED blinks while the automation is active.  
:::

::: info Toggle Trigger
You can decide which trigger will toggle the automation.  
:::

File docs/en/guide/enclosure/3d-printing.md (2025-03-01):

# Enclosure

If you need an enclosure, you can print your own.\
Click [here](https://github.com/azoninc/doorman/blob/master/enclosure) to download the files on GitHub.

::: tip
The STL files are optimized for resin printers, so you'll achieve the best results using one.
:::

## Interactive Viewer
### Top Component
<ClientOnly>
    <div style="aspect-ratio: 16/9; height: auto; margin: 2rem 0; border-radius: 8px; overflow:hidden;">
      <ModelViewer file="https://raw.githubusercontent.com/azoninc/doorman/master/enclosure/Top.stl" />
    </div>
</ClientOnly>

### Bottom Component
<ClientOnly>
    <div style="aspect-ratio: 16/9; height: auto; margin: 2rem 0; border-radius: 8px; overflow:hidden;">
      <ModelViewer file="https://raw.githubusercontent.com/azoninc/doorman/master/enclosure/Bottom.stl" />
    </div>
</ClientOnly>

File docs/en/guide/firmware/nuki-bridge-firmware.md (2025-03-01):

# Nuki Bridge Firmware <Badge type="tip" text="ESP-IDF Framework" />

This configuration inherits all features from the Stock Firmware and adds a [Nuki Bridge](https://github.com/uriyacovy/ESPHome_nuki_lock) component via BLE. Note that it does not support Improv via Bluetooth LE, as the BLE stack is used by the Nuki Bridge component.

## Install or Update Firmware

There are several ways to update the firmware.

::: warning
Be aware that some **updates may introduce breaking changes** — always review the changelogs carefully to ensure your system functions reliably in critical situations.
:::

#### Web Serial <Badge type="tip" text="Latest release build, no customization" />
Connect your **Doorman-S3** via USB-C and click the button below to install or update the latest firmware directly via Web Serial, enabling seamless integration with the Home Assistant API. This setup ensures you can effortlessly apply community-driven updates in the future.

<esp-web-install-button manifest="../../firmware/release/esp32-s3.ha.nuki-bridge/manifest.json">
    <button slot="activate">
        <div class="custom-layout">
            <a class="btn">Install or Update Firmware (Doorman-S3)</a>
        </div>
    </button>
    <div slot="unsupported">
        <div class="danger custom-block">
            <p class="custom-block-title">OH SNAP!</p>
            <p>Your Browser doesn't support Web Serial :(</p>
        </div>
    </div>
    <div slot="not-allowed">
        <div class="danger custom-block">
            <p class="custom-block-title">OH SNAP!</p>
            <p>You are not allowed to use this on HTTP :(</p>
        </div>
    </div>
</esp-web-install-button>

#### HTTP OTA Updates <Badge type="tip" text="Latest release build, no customization" />
By integrating Doorman with Home Assistant, you unlock the convenience of automated firmware builds and seamless updates to the latest releases. The Update will appear directly in your Update list, allowing you to initiate an OTA update with just a click of the Update button — simple, efficient, and hassle-free.

#### ESPHome CLI / Dashboard <Badge type="warning" text="Full customization" />
For full customization and complete control over the firmware, you can adopt it into your ESPHome Dashboard or utilize the ESPHome CLI by executing:  
`esphome run <yamlfile.yaml>`

If you prefer using the MQTT-only firmware, simply apply the provided MQTT example YAML tailored for your board below.

##### Board Configuration Options: 
::: details Doorman-S3 (1.5) / ESP32-S3 (Octal PSRAM)
::: code-group
```yaml [Home Assistant]
<!--@include: ../../../../firmware/examples/esp32-s3.ha.nuki-bridge.master.example.yaml-->
```
```yaml [MQTT]
<!--@include: ../../../../firmware/examples/esp32-s3.mqtt.nuki-bridge.master.example.yaml-->
```
:::

::: details Doorman-S3 (1.4) / ESP32-S3 (Quad PSRAM)
::: code-group
```yaml [Home Assistant]
<!--@include: ../../../../firmware/examples/esp32-s3-quad.ha.nuki-bridge.master.example.yaml-->
```
```yaml [MQTT]
<!--@include: ../../../../firmware/examples/esp32-s3-quad.mqtt.nuki-bridge.master.example.yaml-->
```
:::

::: details Generic ESP32
#### GPIO configuration
- **TC:BUS RX:** GPIO 22
- **TC:BUS TX:** GPIO 23
- **Status LED:** GPIO 2
- **RGB Status LED:** GPIO 4
- **Relay:** GPIO 21
- **External button:** GPIO 20
- **ADC Input:** GPIO 36

::: code-group
```yaml [Home Assistant]
<!--@include: ../../../../firmware/examples/esp32.ha.nuki-bridge.master.example.yaml-->
```
```yaml [MQTT]
<!--@include: ../../../../firmware/examples/esp32.mqtt.nuki-bridge.master.example.yaml-->
```
:::

::: details Generic ESP8266
#### GPIO configuration
- **TC:BUS RX:** GPIO 12
- **TC:BUS TX:** GPIO 13
- **Status LED:** GPIO 2
- **RGB Status LED:** Dummy
- **Relay:** GPIO 14
- **External button:** GPIO 15
- **ADC Input:** A0

::: code-group
```yaml [Home Assistant]
<!--@include: ../../../../firmware/examples/esp8266.ha.nuki-bridge.master.example.yaml-->
```
```yaml [MQTT]
<!--@include: ../../../../firmware/examples/esp8266.mqtt.nuki-bridge.master.example.yaml-->
```
:::

## Pair your Nuki Smart Lock

::: warning
If your Smart Lock is already paired, this process will unpair it!
:::

Depending on the PCB revision, either press the `FLASH`- or `PRG`-button on the Doorman-S3 PCB for 5 seconds until the status LED starts flashing purple, or enable the Nuki Pairing Mode switch in Home Assistant / ESPHome Webinterface. Then, press the button on your Smart Lock for 5 seconds until the light ring turns on.

After a successful pairing, the status LED will remain steadily on for 3 seconds.

## Unpair your Nuki Smart Lock
You can unpair your device using either the `Nuki Unpair Device` button in Home Assistant / ESPHome Webinterface or the physical `FLASH`- or `PRG`-button on the Doorman-S3 PCB.

::: info Physical Button
If your Smart Lock is already paired with Doorman, press the `FLASH`- or `PRG`-button on the Doorman-S3 PCB for 5 seconds until the RGB status LED starts flashing purple. Your Smart Lock will then be unpaired. Note that the pairing mode will time out after 30 seconds.
:::

<!--@include: ./additions.md-->

<!--@include: ./mqtt.md-->

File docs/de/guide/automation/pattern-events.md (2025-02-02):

# Muster-Ereignisse

Die Doorman-Firmware enthält Muster-Ereignis-Entitäten, die du in [Home Assistant](https://www.home-assistant.io/) Automatisierungen verwenden kannst.

Jedes Muster ist wie folgt konfiguriert:
- Drücken
- Maximal 1 Sekunde Pause
- Drücken

Sieh dir die [fortgeschrittenen Beispiele](../firmware/stock-firmware#fortgeschrittene-beispiele) an, um zu lernen, wie du eigene Muster erstellen und anpassen kannst.

## Klingelmuster

### Ereignis Sensoren
- Entrance Doorbell <Badge type="tip" text="entrance_doorbell" />
- Second Entrance Doorbell <Badge type="tip" text="second_entrance_doorbell" />
- Apartment Doorbell <Badge type="tip" text="apartment_doorbell" />

### Ereignistypen
- single
- double
- triple

### Beispiel-Automatisierung
::: details Tür automatisch öffnen, wenn die Eingangsklingel zweimal in einem bestimmten Muster gedrückt wird.
Stelle sicher, dass du die `entity_id` durch deine spezifischen Doorman-Entitäten ersetzt.
```yaml
alias: Eingangstür automatisch öffnen
description: "Öffne die Eingangstür, nachdem die Eingangsklingel zweimal gedrückt wurde."
trigger:
  - platform: state
    entity_id:
      - event.doorman_s3_entrance_doorbell
    attribute: event_type
    to: double
condition: []
action:
  - service: button.press
    metadata: {}
    data: {}
    target:
        entity_id: button.doorman_s3_open_entrance_door
mode: single
```
:::

## Phone Hang up-Muster

### Ereignistypen
- single
- double
- triple

### Beispiel-Automatisierung
::: details Ring-To-Open-Modus umschalten, indem du schnell dreimal den Telefonhörer auflegst.
Stelle sicher, dass du die `entity_id` durch deine spezifischen Doorman-Entitäten ersetzt.
```yaml
alias: Ring-To-Open-Modus umschalten (Telefon-Auflegen-Muster)
description: "Schalte den Ring-To-Open-Modus um, wenn du schnell dreimal den Telefonhörer auflegst."
trigger:
  - platform: state
    entity_id:
      - event.doorman_s3_phone_pick_up
    attribute: event_type
    to: triple
condition: []
action:
  - service: switch.toggle
    metadata: {}
    data: {}
    target:
        entity_id: switch.doorman_s3_ring_to_open
mode: single
```
:::

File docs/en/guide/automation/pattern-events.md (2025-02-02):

# Pattern Events

The Doorman firmware includes pattern event entities that you can use in [Home Assistant](https://www.home-assistant.io/) automations.

Each pattern is configured as follows:
- Push
- Maximum 1-second break
- Push

Check out the [advanced examples](../firmware/stock-firmware#advanced-examples) to learn how to create and customize your own patterns.

## Doorbell Pattern

### Event Sensors
- Entrance Doorbell <Badge type="tip" text="entrance_doorbell_pattern" />
- Second Entrance Doorbell <Badge type="tip" text="second_entrance_doorbell" />
- Apartment Doorbell <Badge type="tip" text="apartment_doorbell" />

### Event Types
- single
- double
- triple

### Example Automation
::: details Automatically open the door when the Entrance Doorbell is pressed twice in a specific pattern.
Make sure to replace the `entity_id` with your specific Doorman entities.
```yaml
alias: Automatically open the entrance door
description: "Open the entrance door after pressing the entrance doorbell two times."
trigger:
  - platform: state
    entity_id:
      - event.doorman_s3_entrance_doorbell
    attribute: event_type
    to: double
condition: []
action:
  - service: button.press
    metadata: {}
    data: {}
    target:
        entity_id: button.doorman_s3_open_entrance_door
mode: single
```
:::

## Phone pickup Pattern

### Event Types
- single
- double
- triple

### Example Automation
::: details Toggle Ring To Open Mode by quickly picking up the phone three times.
Make sure to replace the `entity_id` with your specific Doorman entities.
```yaml
alias: Toggle Ring To Open Mode (Phone pick up Pattern)
description: "Toggle Ring To Open Mode when you quickly pick up the phone 3 times."
trigger:
  - platform: state
    entity_id:
      - event.doorman_s3_phone_pick_up
    attribute: event_type
    to: triple
condition: []
action:
  - service: switch.toggle
    metadata: {}
    data: {}
    target:
        entity_id: switch.doorman_s3_ring_to_open
mode: single
```
:::

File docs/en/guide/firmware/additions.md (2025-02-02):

## Examples

::: details Create a simple TC Command Binary Sensor
You can easily add additional binary sensors for any TC Command, alongside the preconfigured ones.

Command Builder:
```yaml
<!--@include: minimal.example.yaml-->

binary_sensor: // [!code ++] // [!code focus]
  - platform: tc_bus // [!code ++] // [!code focus]
    name: "Custom Command" // [!code ++] // [!code focus]
    type: open_door // [!code ++] // [!code focus]
    address: 0 // [!code ++] // [!code focus]
    web_server: // [!code ++] // [!code focus]
      sorting_group_id: sorting_group_listeners // [!code ++] // [!code focus]
```

32-Bit Commands:
```yaml
<!--@include: minimal.example.yaml-->

binary_sensor: // [!code ++] // [!code focus]
  - platform: tc_bus // [!code ++] // [!code focus]
    name: "Custom Command" // [!code ++] // [!code focus]
    command: 0x00001100 // [!code ++] // [!code focus]
    web_server: // [!code ++] // [!code focus]
      sorting_group_id: sorting_group_listeners // [!code ++] // [!code focus]
```
:::

::: details Controlling the internal RGB Status LED
If you want to control the onboard RGB LED with a button (for example), simply use the Light ID: `doorman_rgb_status_led`.
```yaml
<!--@include: minimal.example.yaml-->

button: // [!code ++] // [!code focus]
  - platform: template // [!code ++] // [!code focus]
    name: "Turn on Status RGB LED to red" // [!code ++] // [!code focus]
    on_press: // [!code ++] // [!code focus]
      - light.turn_on: // [!code ++] // [!code focus]
          id: doorman_rgb_status_led // [!code ++] // [!code focus]
          red: 100% // [!code ++] // [!code focus]
          green: 0% // [!code ++] // [!code focus]
          blue: 0% // [!code ++] // [!code focus]
```
:::

::: details Use the External Hardware Button
If you want to use the external button to trigger automations, you can simply extend your YAML configuration.
```yaml
<!--@include: minimal.example.yaml-->

binary_sensor: // [!code ++] // [!code focus]
  - id: !extend doorman_external_button // [!code ++] // [!code focus]
    on_press: // [!code ++] // [!code focus]
      - logger.log: "External button pressed!" // [!code ++] // [!code focus]
```
:::

::: details Use I²C Sensors
If you want to add sensors via the I²C bus, you can use the two available GPIO pins and add the I²C component to your configuration. You can then attach your sensors to these two I²C GPIO pins.
```yaml
<!--@include: minimal.example.yaml-->

i2c: // [!code ++] // [!code focus]
  sda: GPIO40 // [!code ++] // [!code focus]
  scl: GPIO48 // [!code ++] // [!code focus]
  scan: true // [!code ++] // [!code focus]
  id: i2c_bus // [!code ++] // [!code focus]
```
:::

## Advanced Examples
### Home Assistant
::: details Sending Bus commands
You can use Home Assistant actions (formerly known as services) to send commands on the bus.
Either use the `command` to send raw commands or `type`, `address`, `payload` and `serial_number` to send commands via the command builder.

> [!INFO]
> Remember to include the leading `0x` when calling the action with the `command` property. If you omit it, you'll need to convert the HEX command to a decimal number first.

Command Builder:
```yaml
service: esphome.doorman_s3_send_tc_command
data:
  type: open_door
  address: 0
  payload: 0
  serial_number: 123456
```

Hexadecimal Commands via `command`:
```yaml
service: esphome.doorman_s3_send_tc_command_raw
data:
  command: 0x11E24080
```
:::

::: details Listening for ESPHome events
Doorman will send esphome.doorman events to Home Assistant every time a command is received.

Each event is structured as follows:
```yaml
event_type: esphome.doorman
data:
  device_id: 373c62d6788cf81d322763235513310e
  command: "00001100"
  type: "open_door"
  address: "0"
  payload: "0"
  serial_number: "0"
origin: LOCAL
time_fired: "2024-08-12T12:34:13.718317+00:00"
context:
  id: 01J5399Y2PP2XS2VRYKBT3H3AV
  parent_id: null
  user_id: null
```

Automation Example (HEX Command):
```yaml
alias: Trigger on Doorman TC Open Door Command
description: ""
trigger:
  - platform: event
    event_type: esphome.doorman
    event_data:
      command: "00001100"
condition: []
action: []
mode: single
```

Automation Example (Command Builder):
```yaml
alias: Trigger on Doorman TC Open Door Command
description: ""
trigger:
  - platform: event
    event_type: esphome.doorman
    event_data:
      type: "open_door"
condition: []
action: []
mode: single
```
:::

### ESPHome
::: details Create Your Own Doorbell Pattern
If you want to create a custom doorbell pattern, you can easily extend the existing doorbell entities. For more information about patterns, refer to the [ESPHome Docs](https://esphome.io/components/binary_sensor/index.html#on-multi-click).
```yaml
<!--@include: minimal.example.yaml-->

# Extend the doorbell_pattern event entity // [!code ++] // [!code focus]
# Add a new apartment_special event type // [!code ++] // [!code focus]
event: // [!code ++] // [!code focus]
  - id: !extend apartment_doorbell_pattern // [!code ++] // [!code focus]
    event_types: // [!code ++] // [!code focus]
      - "apartment_special" // [!code ++] // [!code focus]

# Extend the apartment_doorbell / entrance_doorbell entity // [!code ++] // [!code focus]
# and add your new special pattern // [!code ++] // [!code focus]
binary_sensor: // [!code ++] // [!code focus]
  - id: !extend apartment_doorbell // [!code ++] // [!code focus]
    on_multi_click: // [!code ++] // [!code focus]
      # Special Pattern // [!code ++] // [!code focus]
      - timing: // [!code ++] // [!code focus]
          # Press twice with no more than one second between each press. // [!code ++] // [!code focus]
          - ON for at most 0.5s // [!code ++] // [!code focus]
          - OFF for at most 1s // [!code ++] // [!code focus]
          - ON for at most 0.5s // [!code ++] // [!code focus]
          - OFF for at least 2s // [!code ++] // [!code focus]
        then: // [!code ++] // [!code focus]
          - logger.log: "Special pattern detected!" // [!code ++] // [!code focus]
          - event.trigger: // [!code ++] // [!code focus]
              id: apartment_doorbell_pattern // [!code ++] // [!code focus]
              # Use the previously defined new event type here // [!code ++] // [!code focus]
              event_type: apartment_special // [!code ++] // [!code focus]
```
:::

::: details Turn on the light when someone rings the entrance doorbell
You can turn on the light when someone rings the entrance doorbell.
```yaml
<!--@include: minimal.example.yaml-->

binary_sensor: // [!code ++] // [!code focus]
  - id: !extend entrance_doorbell // [!code ++] // [!code focus]
    on_press: // [!code ++] // [!code focus]
      - tc_bus.send: // [!code ++] // [!code focus]
          type: "light" // [!code ++] // [!code focus]
```

If you want to account for the sun's elevation as well, you can adjust it accordingly.
```yaml
<!--@include: minimal.example.yaml-->

# Import the Home Assistant sun elevation sensor // [!code ++] // [!code focus]
sensor: // [!code ++] // [!code focus]
  - platform: homeassistant // [!code ++] // [!code focus]
    id: sun_elevation // [!code ++] // [!code focus]
    entity_id: sun.sun // [!code ++] // [!code focus]
    attribute: elevation // [!code ++] // [!code focus]

# Extend the entrance doorbell sensor // [!code ++] // [!code focus]
binary_sensor: // [!code ++] // [!code focus]
  - id: !extend entrance_doorbell // [!code ++] // [!code focus]
    on_press: // [!code ++] // [!code focus]
      # Sun elevation is <= 0 (dark) // [!code ++] // [!code focus]
      - if: // [!code ++] // [!code focus]
          condition: // [!code ++] // [!code focus]
            sensor.in_range: // [!code ++] // [!code focus]
              id: sun_elevation // [!code ++] // [!code focus]
              below: 1 // [!code ++] // [!code focus]
          then: // [!code ++] // [!code focus]
            # Turn on the light // [!code ++] // [!code focus]
            - tc_bus.send: // [!code ++] // [!code focus]
                type: "light" // [!code ++] // [!code focus]
```
:::

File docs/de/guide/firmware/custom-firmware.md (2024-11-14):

# Custom Doorman Firmware <Badge type="tip" text="Arduino Framework" />

GitHub-Nutzer [peteh](https://github.com/peteh) hat eine Custom Firmware für Doorman entwickelt.

Für weitere Informationen zur Firmware [klicke hier](https://github.com/peteh/doorman).

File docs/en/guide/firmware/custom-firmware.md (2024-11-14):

# Custom Doorman Firmware <Badge type="tip" text="Arduino Framework" />

Github user [peteh](https://github.com/peteh) has developed custom firmware for Doorman circuits.

For more information about the custom firmware, [click here](https://github.com/peteh/doorman).

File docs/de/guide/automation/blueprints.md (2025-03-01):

# Blueprints für Home Assistant

Dies ist eine Sammlung von Community-beigesteuerten Blueprints.

## Bestätigbare Tür-Öffnen-Benachrichtigung

Mit diesem Blueprint kannst du eine bestätigbare Benachrichtigung an ein Gerät mit der Home Assistant-App senden, wann immer jemand an der Tür klingelt.

Die Standard-Bestätigungsaktion löst einen Befehl zum Öffnen der Eingangstür aus, aber du kannst sie nach Belieben anpassen.



## Tür bei Klingelmuster öffnen

Mit diesem Blueprint kannst du die Tür automatisch öffnen, wenn jemand die Klingel in einem bestimmten Muster betätigt.  

Standardmäßig wird die Eingangstür geöffnet, aber du kannst die Aktion nach deinen Wünschen anpassen.  



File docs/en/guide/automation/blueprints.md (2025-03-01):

# Blueprints for Home Assistant

This is a collection of community-contributed blueprints.

## Confirmable Open Door Notification

This blueprint enables you to send a confirmable notification to a device with the Home Assistant app whenever someone rings the doorbell.

The default confirmation action triggers a command to open the entrance door, but you can customize it to suit your needs.



## Open Door on Doorbell Pattern

This blueprint enables you to open the door whenever someone rings the doorbell in the specified pattern.

The default action triggers a command to open the entrance door, but you can customize it to suit your needs.



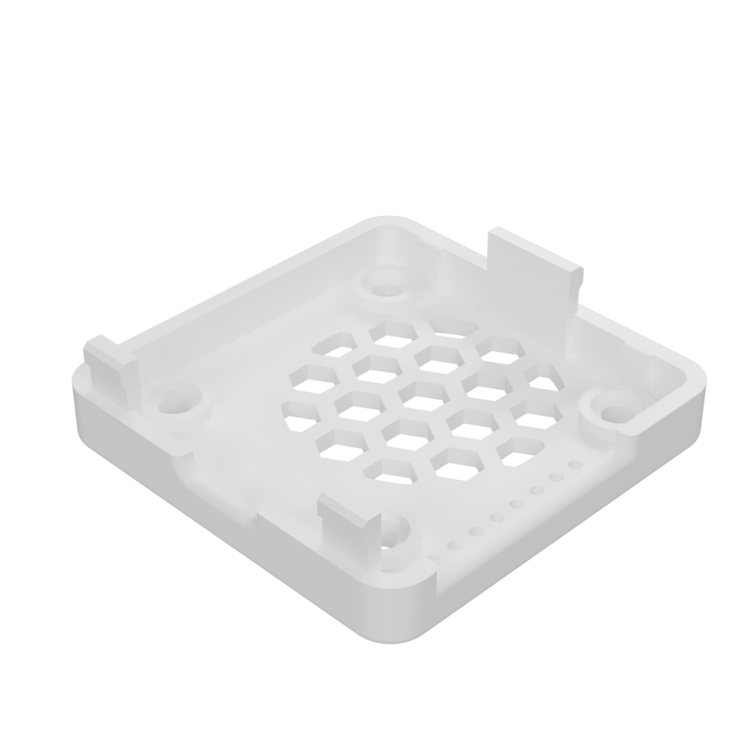
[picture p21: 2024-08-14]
docs/de/guide/enclosure/enclosure_bottom.png

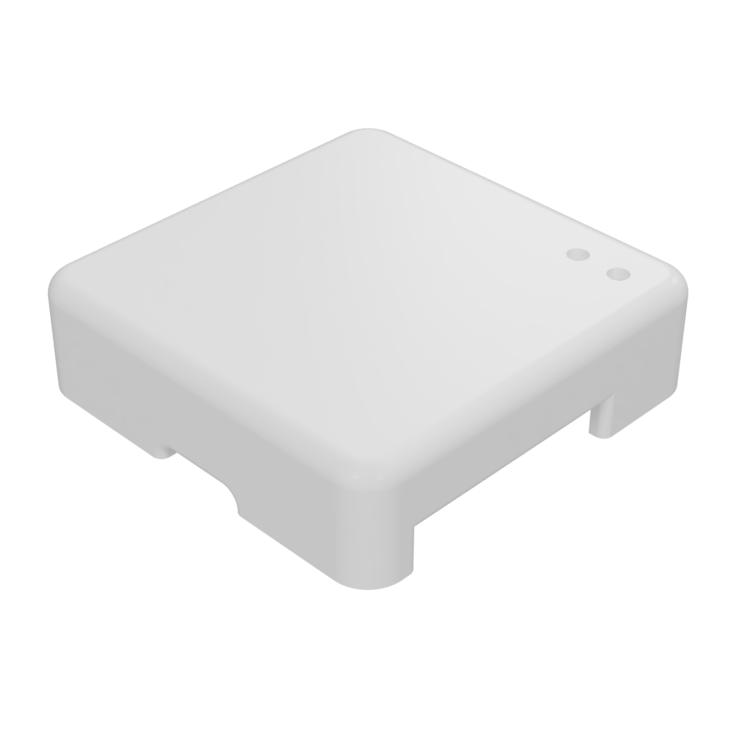
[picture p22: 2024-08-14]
docs/de/guide/enclosure/enclosure_top.png

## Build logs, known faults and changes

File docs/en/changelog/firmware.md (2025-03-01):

# Release Notes & Changelog
Welcome to the latest updates! Here's a breakdown of all the **new features**, **improvements**, and important **changes** you need to know. Be sure to check out the **Breaking Changes** section for any actions needed to keep everything running smoothly.

## 2025.3.0
### ✨ Improvements
- **Fix Update Process**  
   Firmware updates are now correctly identified and retrieved for each specific firmware variant.

- **Ring to Open Toggle Trigger**  
   You can now choose which trigger will toggle the Ring To Open automation as some models use the button for specific purposes.

- **Expanded Support for Model Detection**  
   Now, models without configuration settings are also detected.
   
- **Setup mode delays**  
   By introducing some delay, we allow the ringtone to finish on setup mode.

### 📝 Other Updates
- **Nuki Component**  
   The [ESPHome_nuki_lock](https://github.com/uriyacovy/ESPHome_nuki_lock) component now runs on IDF, removing the need for the Arduino framework.

- **Configuration YAML Files Restructured**  
   The configuration files have been reorganized to enhance modularity and enable support for additional host platforms.

- **Precompiled binaries for ESP32-S3, ESP32 and ESP8266**  
   The Doorman ESPHome firmware is finally available for these platforms as well.

### 🚨 Breaking Changes
- **Ring to Open Toggle Trigger**  
   The new option is set to `Manual` by default. You'll need to set it to `Function Button` to restore the previous behavior.

- **Minimum ESPHome Version Set**  
   We’ve bumped the minimum required version to **2025.2.0**.

## 2025.2.0
### 🚀 What's New?
- **Added a Switch to turn off the Status LED while Ring to Open is active**  
   If you don't want the Status LED to blink while Ring to Open is active, you can now easily turn it off.

- **Automatic Model Detection**  
   The setup mode now attempts to automatically identify the indoor station model. However, this process is not compatible with all models, as some do not support automatic detection.

- **Introduced a button to identify your indoor station model**  
   You can now effortlessly determine the correct model for your settings by simply pressing the "Identify Indoor Station" button, perfect for cases where you're unsure which model you own.

- **Expand Support for Model Settings**  
   Implemented settings compatibility for TCS TASTA (Koch TC60) IVW5xxx and ISW5xxx models.

### ✨ Improvements
- **Fix Parser Command Length**  
   Previously, the command length was not properly parsed, which occasionally led to 32-bit commands being misinterpreted. This issue has now been resolved.
   
- **Configure Entrance Outdoor Station ID**  
   It is now feasible to replace the entrance outdoor station in the exceptional instances where non-default addresses are utilized. The setup mode will also set the entrance outdoor station address.

- **Automatically Disable BLE Server When Not Needed**  
   The BLE Server is now automatically disabled once Wi-Fi is connected. Note: This behavior applies exclusively to the Stock Firmware.

- **Fixed Memory Reading for Some Intercom Models**  
   The memory will now be correctly read from your indoor station.

- **Automatic Intercom Memory Reading**  
   The intercom memory is now automatically read during boot and after model identification. Manual memory readings are still possible but no longer necessary.

- **Experimental Update Switch**   
   Instead of having two separate update entities, there's now a single one that checks for updates based on a new switch. This switch lets you easily toggle experimental updates from the dev branch on or off.

### 📝 Other Updates
- **Nuki Component**  
   The [ESPHome_nuki_lock](https://github.com/uriyacovy/ESPHome_nuki_lock) component now leverages Doorman-S3's PSRAM, potentially enhancing the overall performance.

### 🚨 Breaking Changes
- **PSRAM Compatibility**  
   Some users, particularly those with Revision 1.4 PCBs, may encounter issues due to the newly added PSRAM component. This is because certain Revision 1.4 boards use the N16R2 variant of the ESP32S3, which requires a different configuration for proper PSRAM booting.
   
   For assistance, please contact me via [Discord](https://discord.gg/t2d34dvmBf) or open an issue on [GitHub](https://github.com/azoninc/doorman/issues).

- **Hexadecimal Command-String Length changed**  
   With the command parser now fixed, the hexadecimal string representation has been updated to correctly display the [Last Bus Command](../reference/entities#last-bus-command) sensor.

- **Separate Event entities**  
   [Skaronator](https://github.com/azoninc/doorman/pull/37) introduced separate event entities for each physical doorbell button.  
   This enhancement enables event tracking on a per-button basis, providing more granular and precise support for doorbell interactions.  
   You will need to adjust your automations if you previously used the Doorbell Pattern Event Entity. Additionally, the event types have been changed.

   👉 **Check the [Entities](../reference/entities#events) for details!**

- **Intercom Models Renamed**  
   As part of streamlining the models for each manufacturer, you may need to reconfigure your intercom model.
   Now, you can also see the Koch and Scantron models.

   👉 **Check the [Model Setting availability](../reference/esphome-component#model-setting-availability) for details!**

- **Intercom Settings Updated**  
   To accommodate compatibility with new models, the settings `ringtone_door_call` and `volume_handset` have been renamed.  

   👉 **Refer to the [Setting Types](../reference/esphome-component#setting-types) for the updated names and additional settings!**

## 2024.11.2
### ✨ Improvements
- **Fixed open door command**  
   Use the short open door command instead of the long one (with serial number) as this seems to cause issues on some setups.

## 2024.11.1
### ✨ Improvements
- **Fixed dev branch name**  
   Updated the development branch name to resolve future issues.

### 📝 Other Updates
- **Switch Nuki Component branch**  
   Migrated the `nuki_lock` component to the main branch as the new features got merged.

## 2024.11.0
### 🚀 What's New?
- **TC:BUS Protocol Support**  
   Unleash more power with the **new protocol support**!
   You can now use intuitive command types with parameters like `address`, `payload`, and `serial_number`.  

   👉 **Explore the [Supported Commands](../reference/esphome-component#command-types)**

- **Interactive Setup Enhancements**  
   The system now **remembers** your indoor station's serial number and automatically detects any additional outdoor stations during setup.

- **Expanded Doorbell Functionality**  
   Got more than one entrance? No problem! Your **doorbell and phone pickup patterns** now work seamlessly for a **second entrance**.

- **New Memory Management Tools**  
   You can now **customize ringtones** and **adjust volumes** of indoor stations.  

   👉 **Check the [Supported Models and Settings](../reference/esphome-component#model-setting-availability)**

- **Programming Mode Actions**  
   Just **toggle the control unit’s programming mode** using ESPHome for instant actions.

- **New Nuki Lock Settings**  
   With this release, we fully harness the expanded settings options of the Nuki Lock component, unlocking enhanced customization and control for an elevated user experience.

### ✨ Improvements
- **Better Entity Grouping**  
   Navigate with ease! **Entities** are now more logically grouped on the webserver for effortless control and access.

- **Simplified ESPHome Configuration**  
   We’ve made the ESPHome config files **more modular**! Configurations are now split into separate add-ons for smoother management.

- **Doorman Discovery**  
   We've introduced a new custom protocol that enables seamless discovery of other devices running this firmware for troubleshooting, as well as those utilizing the [custom Doorman firmware](../guide/firmware/custom-firmware) .

### 📝 Other Updates
- **Component Name Change**  
   The `tcs_intercom` component has been renamed to **`tc_bus`** and merged into this repository. All documentation is now centralized [here](../reference/esphome-component).

### 🚨 Breaking Changes
- **Re-setup Required!**  
   The new protocol means you’ll need to **reconfigure** your system. Old stored commands won't work anymore. Simply **press the apartment or entrance doorbell** to start the setup again.  

   👉 **Check the [setup guide](../guide/getting-started#step-3-interactive-setup) for details!**

- **New Service Names**  
   We’ve made changes to the Home Assistant service names to make them easier to understand and use:
   - **Old Format**:
     ```yaml
     service: esphome.doorman_s3_send_tcs_command
     data:
       command: 0x1C30BA41
     ```
   - **New Format**:
     ```yaml
     service: esphome.doorman_s3_send_tc_command_raw
     data:
       command: 0x1C30BA41
     ```
   - **New User-Friendly Option**:
     ```yaml
     service: esphome.doorman_s3_send_tc_command
     data:
       type: floor_call  # Command type (e.g., 'floor_call', 'door_open')
       address: 0        # Address, for example the Outdoor Station
       payload: 0        # Data payload
       serial_number: 0  # Indoor Station serial number
     ```
     **Why it’s awesome**: It’s now **more readable** and lets you **easily specify** command types!

## 2024.8.5
### 🚀 What's New?
- **Enhanced Interactive Setup**  
   Setup is even easier! **Automatically capture and store bus commands** during first-time setup if no previous commands are detected.

### ✨ Improvements
- **Dashboard Import Fix**  
   Fixed those pesky import file name issues—no more confusion!

- **Better Status Colors**  
   We’ve revamped the **status colors** to improve visibility and clarity, making it easier to track everything at a glance.

### 📝 Other Updates
- **Development Builds**  
   We now use the [tcs_intercom](<https://github.com/azoninc/esphome_tcs_intercom>) development branch for development builds.

## 2024.8.3
### 🚀 What's New?
- **Simplified Setup**  
   Initial setup is now a breeze with options like **Access Point**, **Improv Serial**, or **Improv BLE**.

- **Runtime Configuration**  
   Easily configure **bus commands** and settings on the fly!

- **New Event Entities**  
   New entities for doorbell and handset patterns (like **entrance or apartment doorbell**, and **lift handset**).

- **Ring to Open 2.0**  
   Enjoy an enhanced **Ring to Open** mode with fully customizable timeout settings.

- **New Door Opener Button**  
   Added a **button for secondary door** controls (if applicable).

- **Hallway Light Button**  
   Turn on your hallway lights with the new **dedicated button** (if applicable).

- **HTTP OTA Updates**  
   Seamlessly upgrade to the latest Doorman firmware via **Home Assistant**—no need for ESPHome Dashboard!

### ✨ Improvements
- **Direct Stock Firmware Updates**  
   Now you can **install or update** the stock firmware directly from the documentation page. No need to compile it separately!

- **General Tweaks**  
   Several small but useful improvements for a smoother experience.

### 📝 **Other Updates**
- **Webserver Enabled**  
   The webserver feature is now enabled for quicker access.

### 🚨 Breaking Changes
- **Command Reset**  
   Due to the simplified setup process and configurable commands, the substituations are not used anymore. Thus you’ll need to **reconfigure** them using the new input entities.
   
- **Minimum ESPHome Version Set**  
   We’ve bumped the minimum required version to **2024.8.0**.

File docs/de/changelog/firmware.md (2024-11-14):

# Firmware Changelog

<div class="tip custom-block" style="padding-top: 8px">

Changelogs gibt es nur auf Englisch. Klicke [hier](/changelog/firmware) um zu wechseln.

</div>

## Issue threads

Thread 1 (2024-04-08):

Produktion

AzonInc, 2024-04-08:
This issue keeps track of interested people for PCBA orders.

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

### Preorder List:
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

peteh, 2024-04-08:
Gibts noch ein groesseres Risiko dass was nicht funktioniert, also dass man ggf 2 Iterationen einplanen muss oder bist du relativ sicher, dass der erste Wurf schon ganz gut passen wird?

AzonInc, 2024-04-08:
Also ich bin relativ zuversichtlich aber das Risiko liegt ja letztenendes bei mir.
Schauen wir mal aber es sollte in der Theorie passen.

alkue1, 2024-04-08:
1x , wenn möglich gerne mit ESP :)

gee33, 2024-04-09:
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

@AzonInc ja bitte nehm doch den ESP gleich dazu

gee33, 2024-04-09:
ich brauche aber kein case  , ich baue das dann hinter die TC50

AzonInc, 2024-04-10:
> ich brauche aber kein case , ich baue das dann hinter die TC50
Und die Schraubklemme hast du schon verfügbar?

gee33, 2024-04-10:
> > ich brauche aber kein case , ich baue das dann hinter die TC50
>
> Und die Schraubklemme hast du schon verfügbar? Weil du sagtest du möchtest deine eigenen Teile verwenden.

ja, danke , Schraubklemmen habe ich

dannyyy, 2024-04-19:
Darf man sich einer Sammelbestellung / Produktion noch anschliessen?
Wäre an dem Board inkl ESP32 interessiert. Gerne die SMD Variante wie sie in der README.md abgebildet ist.

Habe bei mir auch ein TC50. Benötige kein Case. Entweder drucke ich es selbst oder finde noch eine andere Lösung.
In welcher Preisregion wird sich das ganze bewegen?

AzonInc, 2024-04-19:
Hi,
ja klar das ist nicht möglich.

Also der endgültige Preis steht noch nicht fest aber wird absolutes Maximum 30€ sein zuzüglich Versand dann.
Hoffen wir mal dass es bei ca. 25 landet.
Ich prüfe aktuell noch die Verfügbarkeit von Teilen bei verschiedenen Herstellern.

dannyyy, 2024-04-19:
@AzonInc super, dann darfst du mich gerne auf die Liste setzen. Nehme das rundum Wohlfühlpaket. THT Löten kann ich, bei SMD fehlt mir nötige Zubehör (Paste, Heizbett, ...). Du darfst da gerne etwas draufschlagen, für die zusätzliche Arbeit, die allenfalls anfällt. Werde definitiv was dazu sponsern, habe ewig darauf gewartet, dass jemand eine alternative Lösung für Nello / Nuki findet.

zopieux, 2024-05-02:
Hallo!

I hope English is fine? My German isn't great. :sweat_smile:

I'm also interested in getting the assembled Doorman v1.3 / N8R8, mit Schraubklemme. This is for a two-wire operated TC50. I don't believe I need the relay though. Can you ship to Switzerland, assuming I provide the shipping fee?

Also, I'm a bit confused, is this issue about ordering preassambled boards or PCB + parts + stencil for manual assembly & soldering?

AzonInc, 2024-05-02:
> I hope English is fine? My German isn't great. 😅

Absolutely no problem :)

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

Thanks for your interest.
I only ordered 5 of the rev 1.3 boards in order to test them first - that's also the reason why the list continues with rev 1.4.
When everything is fine in rev 1.3 I'll order a few rev 1.4 which only has a minimal change to allow two-wire operation on the bus and gnd wires only.
And as it's full assembly it always includes the relay even if people don't really use it.

I would probably include you in the 1.4 order then if you want :)

> Can you ship to Switzerland, assuming I provide the shipping fee?

Sure that's no problem I guess.

> Also, I'm a bit confused, is this issue about ordering preassambled boards, or rather PCB + parts + stencil for manual assembly & soldering?

It's about ordering the preassembled board.
Revision 1.3 needs manual assembly of the ESP32 (which I would do) but I'm planning to include the ESP32 in general assembly of rev 1.4 as well.
I'm not sure whether I order 5 or more of rev 1.4. Because there is another revision without the ESP32 Module which uses the ESP32-S3 Chip itself. But it doesn't really change the costs in general - just the components footprint.

And I don't include the screw terminal in the PCBA in order to reduce the costs for THT components.
So you can decide which screw terminal you really want to use and I'll solder it for you. But if you want to solder the screw terminal yourself you're free to do it as well haha.

Just let me know how you decide :)

zopieux, 2024-05-02:
Thanks for the quick reply.

>include you in the 1.4 order then if you want

Yes, please count me in! No problem for the screw terminal, if you're doing then tyvm, otherwise I can definitely solder it myself if it can save you time.

smartforcedev, 2024-05-07:
I am in too if this is still open. What are the next steps?

Cool project! Thank you very much!

AzonInc, 2024-05-07:
> I am in too if this is still open. What are the next steps?
>
> Cool project! Thank you very much!

Glad you like it :)
I ordered 5 REV1.3 boards and will order more as soon as I can verify that they work as designed.
I'll add you to the preorder-list - just tell me your requirements i.e. screw terminal.

dannyduando, 2024-05-08:
Moin,

Ich würde gerne auch noch eins nehmen mit Case ums in die Wand zu schrauben.

AzonInc, 2024-05-08:
@dannyduando auch für TCS dann? und was für eine Schraubklemmen Variante würdest du wollen + in welchem Land wohnst du?

Wlad2288, 2024-05-14:
Hey @AzonInc!
Cooles Projekt ... vielen Dank dafür.
Ich wäre auch interessiert, weiß aber nicht welche Details du von mir benötigst.
Ich habe eine TCS IMM1300 --> https://www.tcsag.de/fileadmin/user_upload/TCS_DE/Metanavigation/Downloads/Produktinformationen/Innenstationen/PI_IMM1300.pdf
Ich hoffe die ist kompatibel.
VG,
Wlad

AzonInc, 2024-05-15:
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

Hi,

Also soweit ich das sehe brauchen die Videostationen 26V als Spannungsversorgung. Das sollte aber kein Problem sein da die eh auf 3,3V gewandelt werden. Die Busleitung ist wohl weiterhin 24V.

Somit sollte das passen.
@peteh was meinst du dazu?

dannyyy, 2024-05-15:
@AzonInc Zielland wäre die Schweiz

dannyduando, 2024-05-15:
Hey @AzonInc ich hatte auf die Email geantwortet, aber ich weiß gar nicht ob das ankommt, ich hab meinen GitHub Account aufgemacht, weil ich das Projekt cool finde.
Ich bräuchte die 9 Pin Variante und nach Deutschland, Danke dir!

AzonInc, 2024-05-15:
> Hey @AzonInc ich hatte auf die Email geantwortet, aber ich weiß gar nicht ob das ankommt, ich hab meinen GitHub Account aufgemacht, weil ich das Projekt cool finde. Ich bräuchte die 9 Pin Variante und nach Deutschland, Danke dir!

Da kam leider nichts an aber jetzt hab ich es hier mal nachgetragen :)

AzonInc, 2024-05-18:
@alkue1 du wolltest nur 3P Schraubklemme als minimalvariante oder?

alkue1, 2024-05-18:
Das sieht ja richtig gut aus! Ich bräuchte erstmal nur die 3 Pins, um das Format möglichst klein zu halten. Und im Zweifelsfall bekomme ich die Pins auch angelötet... Machst du den ESP mit einer Heizplatte oder Kolben fest?
Bin sehr gespannt auf deine Tests:)

AzonInc, 2024-05-18:
> Machst du den ESP mit einer Heizplatte oder Kolben fest? Bin sehr gespannt auf deine Tests:)

Also in dem Fall werd ich es erstmal mit der Heizplatte versuchen, ansonsten Heißluft

AzonInc, 2024-05-18:
Testen konnte ich bisher LEDs, Relais, Spannungsversorgung, Brückengleichrichter.

Soweit ist alles bestens👌🏼

Die Buskommunikation kann ich erst testen wenn ich wieder in der Wohnung bin.

samdolt, 2024-05-19:
Ich bin auch interessiert. 9P und Schweiz. Ich habe dieses Model: https://www.kochag.ch/de/item/innensprechstelle-tc40-classic_DF41.7000

alkue1, 2024-05-19:
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

Dann bin ich sehr zuversichtlich, dass auch der Rest funktioniert. Starke Arbeit!
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
dannyyy, 2024-06-05:
@AzonInc habe heute dein Doorman erhalten und gleich installiert. Was soll ich sagen... absolut tolle Arbeit!! Alles funktionierte auf Anhieb.
Wie würde sich die fehlende Leistung der Speisung bemerkbar machen? Ich habe das Gefühl, dass die Speisung die 60mA aufbringen kann. Aber das muss ich mal beobachten, ob es zu Reboots und Timeouts kommt.

Ich hätte gleich noch einen Vorschlag für ein nächstes Softwarerelease, bin mir nicht sicher, ob ESPHome das kann:
- Anstelle des Loggens und neu Flashens mit den korrekten Commands, könnte man diese nicht via Sensor Komponente oder Text Komponente in Home-Assistant gleich eintragen (manuell) und nutzen?
- Ich selbst habe keine ESPHome Integration in HA, weil mir dort die Möglichkeit für Add-Ons fehlt (Kubernetes). Ich habe das Update entsprechend mit `> esphome dashboard ./` gemacht, welches lokal das ESPHome Dashboard bereitstellt unter `http://localhost:6052`. Vielleicht könnte man das in der Anleitung noch ergänzen. Kann dir aber bis zum Wochenende auch ein PR machen mit einer ergänzenden Beschreibung und Screenshots

peteh, 2024-06-05:
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

In meiner mqtt Firmware habe ich das tatsaechlich so umgesetzt, ist allerdings kein ESPhome. Aber eigentlich sollte es damit auch gehen. Im Prinzip ists ja nur eine int Zahl.

Wenn man fuer den Text Sensor den Configuration Type setzt, dann taucht der auch nur in der Device Page auf. Ich speichere das dann in einem config file auf dem esp32.

AzonInc, 2024-06-06:
@dannyyy bei Gelegenheit werde ich nochmal schauen ob ich es vereinfachen kann :)

Und zwecks Anleitung kannst du gern etwas auf Basis vom dev Branch hinzufügen

K-r-i-s-t-i-a-n, 2024-06-08:
Sehr interessantes Projekt, bitte mich auch auf die Liste setzten. Details habe ich per Email geschickt.

AzonInc, 2024-06-13:
@zopieux did you receive my email regarding the wires? Maybe there is still a wire with 24V hidden behind.
By the way: I can't receive mails at the moment because the mailserver is down.

In case you're not interested anymore just let me know so I can continue with shipping to switzerland :)

zopieux, 2024-06-14:
Apologies, I won't be at my place until Monday to reply. I also access to the PSG02 in the common areas, I'll check if the P wire is even connected there. I do in fact have 4 wires coming out the wall but one is for the door bell, and I suspect the "P" wire is just the door bell return wire. I'll check the potential between b and P. The PCB is configured in two-wire mode, that much I checked, but maybe there is more hidden wire in the wall.

AzonInc, 2024-06-14:
No problem.

> one is for the door bell of course.

Yea actually two of them are connected to the apartment doorbell button.

zopieux, 2024-06-14:
Yeah, I suppose the P screw is the bell return wire, not the 24V :(

zopieux, 2024-06-19:
No dice. :frowning_face:  While the P wire is indeed connected on the BVS20, whatever arrives at my place is just a two-wire cable, and I confirm the other two are the door bell button.

>there is a beeping noise interference on the line
>only operates smoothly with P

I'm not sure I understand what that means. Is the point that we can _try_ running the ESP from just a+b, but it introduces noise in the a+b comms? Are you talking about the voice transport (affecting all residents), or the protocol messages being unreliable?

If it means e.g. the software needs to send messages a few time before it goes through, I think I can live with that. However if you're saying this makes my neighbors' intercom noisy, that's obviously a no go. :-)

Thanks for testing!

matejbart, 2024-06-29:
@AzonInc Bitte 1x die 9P Variante (DE), danke.

AzonInc, 2024-07-11:
@smartforcedev lebst du noch? :)

BiasF, 2024-08-05:
Moin,

Wir hatten grade per E-Mail kontakt, kannst mich also auf die Bestellliste setzen

Ich hab grade bei mir die Station mal aufgemacht und gesehen das alle 4 Anschlüsse belegt sind. Also A, B, E & P.
Macht das einen Unterschied?

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

AzonInc, 2024-08-05:
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

Das sollte passen. An E&P hängt wahrscheinlich der Etagen Klingeltaster von der Wohnung wie bei mir.

BiasF, 2024-08-05:
Ich messe da 1,2V bei 0,81mA.
Kommt mir ein bisschen wenig vor.

protyposis, 2024-08-08:
Received my Doorman today, installed it into TSC ISH3030, and works nicely👍 Great hardware build quality, stable firmware, simple config - thanks @AzonInc!

diaznet, 2024-12-06:
Installed with 3 wires on TC40 and works like a charm, thanks.

Closed 2025-02-11.

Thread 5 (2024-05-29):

Feature: Audio Support

AzonInc, 2024-05-29:
It would be a nice addition to add audio support to the board as well.
If you have any knowledge about audio processing or ideas how to send audio on the bus feel free to share it here.

I've been able to enable and disable the audio mode already but now we need to process the data somehow as a first step.

BiasF, 2024-08-08:
I tried ring intercom last year, it worked but the audio quality was very bad with a high frequent beep in the background.
Didn't feel comfortable with the cloud connection and sent the device back, but it shows that its possible to build that feature.

artifactdev, 2024-11-29:
Might it be possible to "debug" what the ring intercom does, when enabling audio and reverse engineer it? Especially as it is available pretty cheap right now. But as I have it here already and will get a doorman soon, I might be able to support on this.

artifactdev, 2024-12-03:
Here someone also played with audio on tcs bus a bit already, maybe worth a watch even if its some older: https://www.youtube.com/watch?v=TMwRrWqhUkE

AzonInc, 2024-12-03:
Mhh I'm just not sure how to debug it.
I will have an oscilloscope in the next days, sooo maybe I'll find out something new (after figuring out how to use that oscilloscope haha).

Let me know when u find out anything new :)

colinmarc, 2025-02-14:
It seems like it's possible to compile libopus for the esp32 (see for example https://github.com/XasWorks/esp-libopus). One could feed it from an ADC, maybe one of these:

https://github.com/pschatzmann/arduino-audio-tools/wiki/External-ADC

AzonInc, 2025-02-14:
Would it be possible to work with the raw 24V data?
The audio stream is somewhat modulated on the DC but I'm not sure, I couldn't measure any AC.
It's ~22V DC base and ~1-2V audio on top

colinmarc, 2025-02-14:
Disclaimer: I have no idea what I'm talking about

I think what's need is an op-amp to measure the difference between the audio signal and the 22v baseline, and then amplify it to the range that the ADC wants (usually 5v or so?). See "difference amplifier" here https://forum.arduino.cc/t/using-operational-amplifiers-in-your-arduino-project/692648/4

AzonInc, 2025-06-21:
I just found this:
https://electronics.stackexchange.com/a/692106/580470

Somebody created the schematic to achieve the audio reading. However I am also not a professional so I don't know how to implement that properly.

2nv2u, 2025-07-12:
Although I have no clue how and if even feasible, but it would be great to add video support (2 channels for 2 door systems) as well using ONVIF Profile S (RTSP, also for audio), perhaps even support the Profile A for controlling the door locks.
https://www.onvif.org
https://www.home-assistant.io/integrations/onvif
https://en.wikipedia.org/wiki/Real-Time_Streaming_Protocol

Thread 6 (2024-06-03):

Problem: Noise/Beep when using the Bus wire as power supply

AzonInc, 2024-06-03:
In Revision 1.3 sowie 1.4 tritt ein lautes piepgeräusch auf sofern man die a-Busleitung als Spannungsquelle verwendet.
Dieses wird höchstwahrscheinlich durch das Hochfrequente Schaltnetzteil verursacht.

Bei Spannungsversorgung über P-Leitung oder via externer Quelle tritt dieses Problem nicht auf.

--

In revisions 1.3 and 1.4, a loud beeping noise occurs if the a-bus line is used as a power source.
This is most likely caused by the high-frequency switching power supply.

This problem does not occur when the power is supplied via the P-line or via an external source.

AzonInc, 2024-09-07:
Workaround: Bridge P and Bus Wire (positive +24V) using a 50-100 Ohm resistor).
This reduces the noise to a minimum, still present but not annoying and beeping anymore.

Closed 2025-02-11.

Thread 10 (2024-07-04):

Buying doorman

gregmag, 2024-07-04:
Hi, i am interested to buy a Doorman S3 ...
Can you send it to switzerland ? How much does it costs ?
Thank you and congratulation for this amazing developement ?

AzonInc, 2024-07-07:
Hi, thanks for ur interest. Just send me a mail to discuss further details :)
flo@azon.ai

AzonInc, 2024-07-18:
Are you still interested?

pumabaer, 2024-07-25:
Hello, I would also be interested in a circuit board.
What do you want for it?

AzonInc, 2024-07-27:
Hi,

for a the fully assembled Doorman it's 30€ + shipping.

Best regards
Flo

Am Donnerstag, 25. Juli 2024 22:22 CEST, schrieb pumabaer ***@***.***>:
 
 
Hello, I would also be interested in a circuit board.
What do you want for it?
—
Reply to this email directly, view it on GitHub, or unsubscribe.
You are receiving this because you modified the open/close state.Message ID: ***@***.***>[ { ***@***.***": "http://schema.org", ***@***.***": "EmailMessage", "potentialAction": { ***@***.***": "ViewAction", "target": "https://github.com/AzonInc/Doorman/issues/10#issuecomment-2251330169", "url": "https://github.com/AzonInc/Doorman/issues/10#issuecomment-2251330169", "name": "View Issue" }, "description": "View this Issue on GitHub", "publisher": { ***@***.***": "Organization", "name": "GitHub", "url": "https://github.com" } } ]***>

Closed 2024-07-07.

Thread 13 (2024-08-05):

Kompatibilitätsprüfung

AzonInc, 2024-08-05:
Ich messe da 1,2V bei 0,81mA.
Kommt mir ein bisschen wenig vor.

_Originally posted by @BiasF in https://github.com/AzonInc/Doorman/issues/1#issuecomment-2269732936_

Das ist durchaus etwas wenig.
Und wie schaut's auf den anderen Leitungen aus?

BiasF, 2024-08-05:
Ich messe gleich mal gegen A, normal müsste die Spannung ja bei 24v liegen.

BiasF, 2024-08-06:
Zwischen A und P beträgt die Spannung 22,8V, kommt schon eher hin

AzonInc, 2024-08-06:
Okay und zwischen a und b müssen es auch ähnlich viel sein wie a und p

BiasF, 2024-08-06:
jop, da sind es 23,8.

AzonInc, 2024-08-06:
Dann ist alles kompatibel und die Leitungen nur vertauscht. Die Doorman Platine dreht sich die eh so wie sie gebraucht werden.
Da klemmst du dann a & b je an ein TCS:Bus und P an P.

BiasF, 2024-08-06:
TOP dann bin ich schon sehr gespannt ob alles funktioniert :)

AzonInc, 2024-09-07:
Ein Workaround für das Piepen wäre ein 56 oder 100 Ohm Widerstand als Brücke zwischen P und Bus +24V

AzonInc, 2024-09-07:
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
Das ganze würde dann so aussehen.

BiasF, 2024-09-07:
Das teste ich mal in den nächsten Tagen wenn ich wieder daheim bin, so einen Widerstand müsste ich noch rumfliegen haben 👍

AzonInc, 2024-09-07:
mit 100 peipt es nicht mehr aber es kommen auch keine commands rein weil die spannung wahrscheinlich davon zu beeinträchtigt ist
mit 56 piept es auch nicht aber damit könnten wieder commands rein (muss ich selbst mal testen)

AzonInc, 2024-09-07:
Okay also das läuft nicht wie gewünscht.
Stromversorgung ohne große Störgeräusche ja, Daten lesen nein 🥲

AzonInc, 2024-12-06:
Moin, wie betreibst du das Teil derzeit? Wahrscheinlich mit externer Spannungsversorgung oder?

BiasF, 2025-02-09:
Moin,

Ich habs aktuell einfach per USB Angeschlossen.

AzonInc, 2025-02-11:
Okay, denke dann passt das erstmal. Ich habe leider erst mit rev 1.5 eine mehr oder weniger schöne lösung gefunden

Closed 2025-02-11.

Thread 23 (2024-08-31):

Feature: Automatic Setup

AzonInc, 2024-08-31:
Anlage auslesen per Service Commands.

1. AS select: 5802
2. Suchen: 5200
3. Incoming Commands sammeln (5 **9E5D2** 1A)
4. IA select: 5800
5. Suchen: 5200
6. Incoming Commands sammeln (5 **00007** 1C)

Ergebnis: Seriennummern der Innen und Außenstationen
Dadurch auch die Anzahl der Außenstationen/Türen

Closed 2024-09-29.

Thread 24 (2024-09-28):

Feature: Second Doorbell

m4n0v31, 2024-09-28:
### Description

Hi,
I received and installed the doorman3 and it is grerat.
I've the following question.

my building has a setup a little different:
- Entrance Door: with Doorbell and Camera
- Second Door: with Doorbell and Camera
- Apartment Door: with Doorbell

The system has:
- command to open entrance door (already supported in the stock configuration)
- command to open second door (already supported in the stock configuration)
- command for doorbell at entrance (already supported in the stock configuration)
- command for doorbell at second door (not available in stock configuration)
- command to pick up phone at entrance, show video at entrance (already supported in the stock configuration)
- command to pick up phone at second door, show video at entrance
- command to hang up at entrance
- command to hang up at second door
- command to switch from entrance video to second door video

There is only one button to pick up phone, and it starts showing the video last seen or where the last doorbell was rang. So if I press the button it could be any of the two command picking up the phone.

I would like to :
- be able to configure the command for the doorbell at second door and show this as an entity (in the same way "apartment doorbell" and "entrance doorbell" are made)
- be able to detect and react on pattern at second doorbell
- be able to have "ring to open" active also at second doorbell, or have the possibility of configure "ring to open" so that the entrance door is open and after 10s the second door is open.
- be able to insert two command for the phone pick up (any of the two is valid as phone pick up)
- be able to insert two command for the phone hand up (any of the two is valid as phone hang up)

What's the best way to support this setup?

### Logs

_No response_

### Which version of the ESPHome Doorman firmware config are you running?

Firmware: 2024.9.1

### How do you manage your Doorman's updates?

None

### If you're using an ESPHome YAML config, which version of ESPHome are you running?

2024.9.1

### ESPHome Config

_No response_

AzonInc, 2024-09-29:
Are you running the latest Dev firmware or stable one?

m4n0v31, 2024-09-30:
I'm running stable.
I'll try out dev and let you know. Thx

AzonInc, 2024-09-30:
> I'm running stable.
> I'll try out dev and let you know. Thx

But please note that the Dev version is mostly a rewrite and works differently.

It doesn't really use commands in the way stable used them. So you have to set it up again.

Please follow the getting started guide of the Dev version. It has all the information you will need.

m4n0v31, 2024-09-30:
OK,
I tried to switch to dev by changing the package in the doorman-s3.yaml file from esphome to:
`AzonInc.Doorman: github://AzonInc/doorman/firmware/doorman-stock.yaml@dev`

but I get the following:
```
Failed config

number.template: [source /config/.esphome/packages/efae6b5d/firmware/addons/memory-utils.yaml:22]

  optimistic cannot be used with lambda.
```

AzonInc, 2024-09-30:
> but I get the following:

Should be fixed now

m4n0v31, 2024-09-30:
On the other side. How long until the changes I'm interested in make it to "stable"?
Is it worth to switch to dev and then stay there?

AzonInc, 2024-09-30:
> On the other side. How long until the changes I'm interested in make it to "stable"?
> Is it worth to switch to dev and then stay there?

Maybe two or three more weeks when im Back in Germany with more time.

The dev version improves the Plug & Play experience a lot as no commands are needed and the TCS protocol is implemented to some extent. But also has some breaking changes due to removal or renaming some entities.

I will write everything down(Discord announcements) in detail when it's ready.

m4n0v31, 2024-09-30:
do you know if it is possible to override the "initial_value" of the globals in the yaml file, so I can already put in my commands and don't care if I switch from one branch to the other?

AzonInc, 2024-09-30:
Thats not gonna work as these commands are subject of removal.

They dont exist in dev.

AzonInc, 2024-09-30:
The new system is using serial numbers only and is saving them separately.

AzonInc, 2024-09-30:
I just looked at the code and it's like that:
There is a pick up phone sensor which triggers whenever you talk to the entrance or second door.
So both of them trigger the pickup phone pattern.

It's the same behaviour for the hang up phone sensor. it doesn't matter which station youre talking to. Whenever you hang up the phone it will trigger.

The second doorbell sensor triggers the same doorbell pattern event entity.
But it uses the second_ event types:
      - "apartment_single"
      - "apartment_double"
      - "apartment_triple"
      - "entrance_single"
      - "entrance_double"
      - "entrance_triple"
      - "second_entrance_single"
      - "second_entrance_double"
      - "second_entrance_triple"

So based on your request the following is already in dev:
- be able to configure the command for the doorbell at second door and show this as an entity (in the same way "apartment doorbell" and "entrance doorbell" are made)
- be able to detect and react on pattern at second doorbell
- be able to insert two command for the phone pick up (any of the two is valid as phone pick up)
- be able to insert two command for the phone hand up (any of the two is valid as phone hang up)

This needs to be done:
- be able to have "ring to open" active also at second doorbell, or have the possibility of configure "ring to open" so that the entrance door is open and after 10s the second door is open.

AzonInc, 2024-11-16:
Please check the latest release and open a new issue if there is still something missing.

Closed 2024-11-16.

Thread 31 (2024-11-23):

open_door command always uses persisted serial_number

matejbart, 2024-11-23:
### Description

Hi @AzonInc ,

I have updated to the latest v1.5.0 and the `open_door` command no longer works (for my outer station) because the command is now built differently (with the internal station's serial_number):

https://github.com/AzonInc/Doorman/blob/2340d89c2fc572b41363b56cfcb34ecd43f633d2/components/tc_bus/protocol.cpp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

The firmware [always tries](https://github.com/AzonInc/Doorman/blob/2340d89c2fc572b41363b56cfcb34ecd43f633d2/components/tc_bus/tc_bus.cpp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) to pass the persisted `serial_number` to the buildCommand (if it's not set by the caller or if it's just 0).

I therefore modified the `protocol.cpp` by building the `open_door` without the `serial_number` and that solves the problem for me.

I'm just curious why the composition of that command has changed, is this necessary for any other model types? (I'm using a `ISH 1030` internal station).

Another thing that I have noticed is the last byte of the open_door command: In the case without the `serial_number` the address has no longer the leading `8`.

For example, my internal station always sends `1180`, but that is no longer possible (even though `1100` works just fine). However, since `COMMAND_TYPE_STOP_TALKING_DOOR_CALL` also uses the `8`, I was wondering if this should be aligned with the open_door cmd as well.

Best regards,
Matej

### Logs

_No response_

### If you're using an ESPHome YAML config, which version of ESPHome are you running?

2024.11.1

### ESPHome Config

_No response_

matejbart, 2024-11-24:
> I just noticed that this could be a streamlined way of building this command while looking at the protocol definitions.

Are you referring to the cmd `langer Türöffner` from the [protocol definitions](https://github.com/user-attachments/files/17893181/TCSBusProt.xml.zip) (starting from line 250)?

From my humble understanding I believe this command serves a different purpose, maybe to keep doors opened until another command is issued (even though I couldn't find such a command). However, in my case the outdoor station uses a door opener relay ("buzzer") to open the door, so I think that the `langer Türöffner` is simply not designed to work with this setup. (But please correct me if I'm wrong, maybe this works at your outdoor station?)

Furthermore, as all the other indoor stations always just use the `11XX` command, I would basically prefer to stick with that and try to mimic the behavior of the indoor stations as good as possible.

> I couldn't find any definition of that byte in the protocol definitions. That's why I didn't implement it.

It seems that an `8` (in hex) denotes that the address is coming or targeting an outdoor unit, and when it's `4` then it's from an indoor station. It's the bit before the 6-bit address (definitions starting from line 139 for example, but this is also valid for the `3xxx` cmds as well).

> We could just remove the long version of the open door command or include a flag to use the king version but when it's not set always use the short 11xx version.

Sounds good, I just think that using the "long" version should probably not be the default option.

> Another question: Could it be related to your outdoor station changing its address? #32

No, the "changing address" thing happened afterwards.

> But as u send 1100 with address 0, which works, it's not related to the address.

It's really interesting that even though the outer stations address has changed, sending `1100`, `1180` and `1181` still works. Maybe there is a setting in the outdoor stations unit to always react on 11xx`?

AzonInc, 2024-11-24:
> Are you referring to the cmd langer Türöffner from the protocol definitions (starting from line 250)?

Yea, that's the one. Here in this building they also have the door buzzer and probably the same control unit as in urs (there is only option as far as I know). Here it worked just fine (also at other peoples setup) so I thought implementing it is fine but I will remove the serial number version.

> It seems that an 8 (in hex) denotes that the address is coming or targeting an outdoor unit, and when it's 4 then it's from an indoor station. It's the bit before the 6-bit address (definitions starting from line 139 for example, but this is also valid for the 3xxx cmds as well).

I'm not sure if an outdoor station is opening the door itself (at least I've never seen an outdoor station sending 11xx by itself, but never say never).
For the 3xxx its just the door readiness flag to pickup calls (after ringing)

> It's really interesting that even though the outer stations address has changed, sending 1100, 1180 and 1181 still works. Maybe there is a setting in the outdoor stations unit to always react on 11xx`?

If there are two outdoor stations 1100 won't work for both of them (tested).

AzonInc, 2024-11-24:
It's changed in [2024.11.2](https://github.com/AzonInc/Doorman/releases/tag/2024.11.2)

AzonInc, 2024-11-25:
Can I close this or do we still need to do smth here?

matejbart, 2024-11-25:
Thx for the update, and yes I have also seen in the manual of the service device that there is a difference between the short and long open door command, but I couldn't figure out which command to send to check if the limitation on the outer station is active or not, maybe this is something that can be only programmed via the configo software?

AzonInc, 2024-11-25:
> Thx for the update, and yes I have also seen in the manual of the service device that there is a difference between the short and long open door command, but I couldn't figure out which command to send to check if the limitation on the outer station is active or not, maybe this is something that can be only programmed via the configo software?

Yes that's what the guy told me today, it's an advanced feature only configurable via configo.

matejbart, 2024-11-26:
Just for the sake of documentation, the [online configo manual](http://tcs-forum.de/download/download_tcsag/configo_Online-Hilfe/#8) reveals that the setting `Lange Türöffnerfunktion als Rufprotokoll` is set on the control unit (and not the outer unit as I have wrongly guessed before), it would be just interesting to figure out how the internal stations know that the long command should be used - this could be also tracked by the firmware and adjusted automatically.

Another thing worth noting is that the [outer stations](http://tcs-forum.de/download/download_tcsag/configo_Online-Hilfe/#6.1) have a setting to only allow the open door command to be "executed" while being in `Türbereitschaft` or even only during a voice call, but this seems to be deactivated by default.

AzonInc, 2024-11-26:
> Another thing worth noting is that the outer stations have a setting to only allow the open door command to be "executed" while being in Türbereitschaft or even only during a voice call, but this seems to be deactivated by default.

Some have it enabled which is quite annoying because it prevents the open door button to work properly.

> it would be just interesting to figure out how the internal stations know that the long command should be used - this could be also tracked by the firmware and adjusted automatically.

I have a TCS test system at home so I could try whatever but I just need to know what.

AzonInc, 2024-11-27:
It somehow "just works" without further doingOn 27 Nov 2024 16:45, Matej Bartalsky ***@***.***> wrote:

I have a TCS test system at home so I could try whatever but I just need to know what.

As you have mentioned in #32 (comment) that your TCS system starts to use the long_door command after the control button of any internal station is hit. Does every other indoor station react on that command immediately, or does it need to be called out by the outer station first?
Because if it's the latter, then this information - that the indoor stations need to use the long_door command - must be somehow encoded in the door call command.

—Reply to this email directly, view it on GitHub, or unsubscribe.You are receiving this because you were mentioned.Message ID: ***@***.***>
[
{
***@***.***": "http://schema.org",
***@***.***": "EmailMessage",
"potentialAction": {
***@***.***": "ViewAction",
"target": "https://github.com/AzonInc/Doorman/issues/31#issuecomment-2504203503",
"url": "https://github.com/AzonInc/Doorman/issues/31#issuecomment-2504203503",
"name": "View Issue"
},
"description": "View this Issue on GitHub",
"publisher": {
***@***.***": "Organization",
"name": "GitHub",
"url": "https://github.com"
}
}
]

matejbart, 2024-11-27:
ok, then I think we're done here 👍 feel free to close the issue.

Closed 2025-01-12.

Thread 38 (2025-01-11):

Either main OR second entrance is not recognized after setup mode

falschparker82, 2025-01-11:
### Description

I've tried setup mode multiple times (after each one resetting the Doorman v1.5 to factory defaults). The problem is that just one of the doors is ever recognized — interestingly enough, both as "Second Entrance" — and the other one ignored. I just see the other door as bus events. Here are the corresponding logs. I guess something doesn't quite work with guessing the second entrance ID?

Below are the corresponding bus events. In the meantime, is there any way to hardcode both addresses, and if yes, which part is the ID? (I guess the middle hex part?)

Help very much appreciated.

### Logs

```plain text
Main Entrance:
changed to 0E88C683
14:30:41 - 9 minutes ago
changed to 1E88C683
14:23:08 - 17 minutes ago

Second Entrance:
changed to 0E88C681
14:34:21 - 5 minutes ago
changed to 1E88C681
14:23:34 - 16 minutes ago

Some misc bus events of questionable relevance (I don't speak TCS bus just yet :)
changed to 00008414
14:36:24 - 15 minutes ago
changed to 00008410
14:36:24 - 15 minutes ago
changed to 0000840C
14:36:24 - 15 minutes ago
changed to 00008408
14:36:24 - 15 minutes ago
changed to 00008404
14:36:23 - 15 minutes ago
changed to 00008400
14:36:23 - 15 minutes ago
changed to 810E88C6
14:36:23 - 15 minutes ago
changed to 00005800
14:36:23 - 15 minutes ago
changed to 00002481
14:35:29 - 16 minutes ago
changed to 00002281
14:34:33 - 17 minutes ago
changed to 0E88C681
14:34:29 - 17 minutes ago
changed to 00002281
14:34:21 - 17 minutes ago
changed to 0E88C681
14:34:21 - 17 minutes ago
```

### Which version of the ESPHome Doorman firmware config are you running?

? (Hardware Doorman-S3 1.5.0) -> good idea to show FW version on web interface?

### How do you manage your Doorman's updates?

OTA Updates

### If you're using an ESPHome YAML config, which version of ESPHome are you running?

_No response_

### ESPHome Config

_No response_

AzonInc, 2025-01-11:
Hi, could you please send me the webserver logs?
But you need to set loglevel do DEBUG first. Please compile the firmware using
```
substitutions:
  log_level: "DEBUG"
```

The debug logs contain everything that I need to know :) Also the decoded commands including AS address and payloads.

falschparker82, 2025-01-12:
Hi Flo, here are the logs:

```
## MAIN ENTRANCE
[17:05:36][D][sensor:093]: 'Bus Voltage': Sending state 3.02800 V with 2 decimals of accuracy
[17:05:37][D][tc_bus:246]: Received command 0E88C683
[17:05:37][D][tc_bus:441]: [Parsed] Type: DOOR_CALL, Address: 3, Payload: 0, Serial: 952518
[17:05:37][D][text_sensor:064]: 'Last Bus Command': Sending state '0E88C683'
[17:05:37][D][binary_sensor:036]: 'Second Entrance Doorbell': Sending state ON
[17:05:37][D][tc_bus:572]: Send event to Home Assistant on esphome.doorman
[17:05:37][D][binary_sensor:036]: 'Second Entrance Doorbell': Sending state OFF
[17:05:37][D][sensor:093]: 'Bus Voltage': Sending state 2.98400 V with 2 decimals of accuracy
[17:05:38][D][sensor:093]: 'Bus Voltage': Sending state 3.01200 V with 2 decimals of accuracy
[17:05:39][D][event:015]: 'Doorbell Pattern' Triggered event 'second_entrance_single'
[17:05:39][D][tc_bus:611]: Sending command 00001103
[17:05:39][D][tc_bus:441]: [Parsed] Type: OPEN_DOOR, Address: 3, Payload: 0, Serial: 0
[17:05:39][D][text_sensor:064]: 'Last Bus Command': Sending state '00001103'

Second Outdoor Station after Setup:
Serial: 952518
Hex: E88C6
ID: 3

## SECOND ENTRANCE
[17:05:59][D][sensor:093]: 'Bus Voltage': Sending state 3.02000 V with 2 decimals of accuracy
[17:06:00][D][sensor:093]: 'Bus Voltage': Sending state 3.00000 V with 2 decimals of accuracy
[17:06:00][D][tc_bus:246]: Received command 0E88C681
[17:06:00][D][tc_bus:441]: [Parsed] Type: DOOR_CALL, Address: 1, Payload: 0, Serial: 952518
[17:06:00][D][text_sensor:064]: 'Last Bus Command': Sending state '0E88C681'
[17:06:00][D][tc_bus:572]: Send event to Home Assistant on esphome.doorman
[17:06:01][D][sensor:093]: 'Bus Voltage': Sending state 3.00000 V with 2 decimals of accuracy
[17:06:02][D][sensor:093]: 'Bus Voltage': Sending state 3.00300 V with 2 decimals of accuracy
[17:06:03][D][sensor:093]: 'Bus Voltage': Sending state 3.01500 V with 2 decimals of accuracy
[17:06:04][D][sensor:093]: 'Bus Voltage': Sending state 3.01700 V with 2 decimals of accuracy
[17:06:05][D][tc_bus:246]: Received command 00002281
[17:06:05][D][tc_bus:441]: [Parsed] Type: END_OF_RINGTONE, Address: 1, Payload: 0, Serial: 0
[17:06:05][D][text_sensor:064]: 'Last Bus Command': Sending state '00002281'
[17:06:05][D][tc_bus:572]: Send event to Home Assistant on esphome.doorman

Second Outdoor Station after Setup:
Serial: 952518
Hex: E88C6
ID: 1
```

falschparker82, 2025-01-12:
From the base.yaml I assume all of this is convention over configuration at ID = 0 and my main entrance ID = 3 seems pretty nonstandard, right?

```
# Preconfigured Open Door Button
  - platform: template
    id: open_entrance_door
    name: "Open Entrance Door"
    icon: mdi:door
    on_press:
      - tc_bus.send:
          type: open_door
          **address: 0**
    web_server:
      sorting_group_id: sorting_group_controls
      sorting_weight: -10
 ```

AzonInc, 2025-01-12:
Fixed in dev branch

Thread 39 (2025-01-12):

Disable Bluetooth

protyposis, 2025-01-12:
### Description

Hi, I'm running firmware 2024.11.2 and noticed that "Doorman-s3" shows up as an available Bluetooth device on my phone, even though my setup is completed. Is this expected behavior, and if so, what's the use case? Would it make sense to make it configurable with a system setting?

I'm not sure if I remember correctly, but I believe older firmware versions turned it off after the setup was completed, so I'm not sure whether this is a bug report or a feature request.

AzonInc, 2025-01-12:
Mhh I'm not aware of this issue.
Maybe the latest ESPHome version has a bug or smth.

protyposis, 2025-01-13:
Ok, so you're saying this is unexpected behavior.

I originally used ESPHome 2024.11.3 and just reinstalled with 2024.12.2 - Bluetooth still active.

AzonInc, 2025-01-13:
Maybe nobody ever noticed this behaviour.

I just tried to look for Bluetooth devices on my phone but can't seem to find any around here.

Is there anything in the logs about improv ble?
And does Home Assistant still discover the device?

matejbart, 2025-01-13:
Hi,

I have also noticed that (and thought it's default behavior), therefore I disabled ble improv by commenting `esp32_improv:` in the `doorman-stock.yaml`.

Regardless of whether this is a bug or should be addressed in some other way, I want to point out that the [esp32_improv doc](https://esphome.io/components/esp32_improv) also includes the following warning:

> The BLE software stack on the ESP32 consumes a significant amount of RAM on the device.

So maybe it might be worth considering to disable ble improv by default?

AzonInc, 2025-01-13:
It's in there as an easy way to setup the device for the first time.
But in the Nuki Bridge Firmware its disabled as it's incompatible with the NimBLE Stack used by the Nuki component.

Not sure how often it's used but mDNS doesnt work in some cases so I thought BLE Improv would be a nice addition.

AzonInc, 2025-01-13:
FYI: It's fixed in the dev channel. The issue is not improv, but the BLE server itself which is automatically started when using the improv component. The BLE Server will now stop as soon as wifi is connected and will start when wifi is disconnected.

Closed 2025-01-13.

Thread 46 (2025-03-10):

Homekit

findthebug, 2025-03-10:
### Description

Support to connect the door opener action to homekit would be super.

Since this is using ESP maybe there is a way to integrate HomeSpan, so the actions like doorbell, opener are exposed to homekit.

looking for a way to controll Koch TC50, door opener with homekit. This project looks promising to me.

also using Homebridge, maybe there is a way to connect Doorman with a plugin there?

findthebug, 2025-03-14:
if i see this correctly. there is a firmware for doorman & MQTT only right? Homebridge has also some MQTT plugins, maybe it's even easier to communicate directly with doorman?

AzonInc, 2025-03-14:
Yea I saw that as well but you would need to add the entire topic structure to your config and build it.

findthebug, 2025-03-14:
at the end all im looking for is a way to trigger door opener in some way. since the doorman has an IP address, is there a chance to just do some simple curl to trigger door opener?

AzonInc, 2025-03-14:
Yes of course, you can use the ESPHome API and make a call to toggle the button.

findthebug, 2025-03-14:
Ah ok. Do i need Home Assistant setup for this? Or is there a firmware i can implement this without HA?

AzonInc, 2025-03-14:
You don't need Home Assistant for it, just use the custom config and add the ESPHome API again. If you need an example I can help you.

findthebug, 2025-03-14:
A ok all good. Will check all of this as soon as i have the device. Thanks!

findthebug, 2025-04-27:
Got the Device and all was working in less then 10 minutes!

1. Did the stock firmware update to 2025.3.0
2. Did the default device setup wlan & wiring on a Koch device
3. Checked the web interface to test the device via "Open Entrance Door", which was working first press!
4. Now i use "curl  http://doorman-s3/button/open_entrance_door/press" in homebridge to trigger the action

Thanks 100times!

AzonInc, 2025-06-11:
I worked on native HomeKit support for doorbell events and door locks.
It's available in the dev branch. Its a special variant that has to be flashed.

https://dev.doorman.azon.ai/guide/firmware/installation

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

https://dev.doorman.azon.ai/guide/firmware/homekit

Closed 2025-04-27.

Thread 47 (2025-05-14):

Station with two Doors

lukaiser, 2025-05-14:
### Description

Our second station has two connected doors. You can ring all apartments from the station but depending on the indoor station one or the other door opens. Therefore, the short code e.g. „1102“ doesn’t do the trick, it needs to be the long code e.g. “16CFEA82”.

Thanks for considering the feature!
Lukas

lukaiser, 2025-05-16:
Apparently, the long code isn't enough to open the correct door. It also seems to depend on beforehand used doorbell. Does anybody know if there is a code that might work?

lukaiser, 2025-05-18:
The system seems to work as follows:
When pressing a doorbell button, the second station sends two ring commands. One to the indoor station and another ring command to one of the two [relay](https://www.tcsag.de/fileadmin/user_upload/TCS_DE/Metanavigation/Downloads/Produktinformationen/Funktionserweiterungen/PI_BRE2-SG.pdf).
The second ring command seems to prime the relay for 30 seconds.
Sending the ring command to the relay and half a second later the open door command seems to work reliable to open the correct door.
I am still trying to figure out, if there is a command to open the relay directly but haven't found anything useful yet. Any idea? Thanks for the help!

AzonInc, 2025-05-18:
Okay, could you provide the exact commands / logs when you open each door?

lukaiser, 2025-05-18:
### Log using the original system:

**Apartment 1**

1. Pressing Bell
2. 0007D082 -> Bell to Relay Door 1
3. 06CFEA82 -> Bell to Indoor Station 1
4. Pressing Door Opener
5. 16CFEA82
6. 2282
7. 2482

**Apartment 2**

1. Pressing Bell
2. 0003E882 -> Bell to Relay Door 2
3. 06CFD182 -> Bell to Indoor Station 2
4. Pressing Door Opener
5. 16CFD182
6. 2282
7. 2482

### Using Doorman Send Command:

**Door 1**

1. 0007D082 -> Bell to Relay Door 1
2. 1 Second Delay
3. 16CFEA82

**Door 2**

1. 0003E882 -> Bell to Relay Door 1
2. 1 Second Delay
3. 16CFEA82

lukaiser, 2025-05-18:
I was able to solve it with a HA Automation and a helper button.
Thanks for looking into it!

Closed 2025-05-18.

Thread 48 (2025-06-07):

Muting the apartment station/door bell

Nerdiyde, 2025-06-07:
### Description

Hi guys,
not 100% a feature request (yet):

Does anybody know if it is possible to use doorman to mute the station/doorbell within the apartment.
So far I could not observe that there is a bus command sent when the mute button on the panel is pressed.
Probably there is a GPIO on the panel that could be used? Does anybody know something about that?

The idea is that I could automatically mute the bell in case my smart home is in a certain mode (sleep, etc).

Thanks in advance and best regards
Fab

AzonInc, 2025-06-07:
Theres no easy way to achieve it.
Someone is using the Doorman relay to disconnect the speaker of the indoor station to be able to mute it.

While you can read/write the mute state, the indoor station won't accept the new setting.
Maybe we could just send a bunch of dummy commands to supress the ringtone.

Nerdiyde, 2025-06-07:
Thanks for that, I will try it.
Can you give me some more info about the last sentence ("Combining this with the settings (ringtone volume) it should be better than nothing"):
Is there an official way to set the ringtone volume via bus commands?

Nerdiyde, 2025-06-08:
Uhhh, I missed that, thanks.
I will check it and come back with feedback. :)

AzonInc, 2025-06-08:
I think the old interrupt based implementation in master branch would be able to prevent the indoor station from even receiving the command at all by interrupting the transmission.

Shorting the bus for 7ms before the last bit is received (when it's a doorbell command for your serial number)

Nerdiyde, 2025-06-24:
Thanks again for all the hints. I installed the latest version and checked the Volume option. Unfortunately it's not possible to lower the volume to zero (at least then the volume is not off with the lowest setting).
My solution for now is to deactivate the speaker permanently at the indoor panel and then react only via doorman events on the doorbell.
(Unfortunately there seems to be a restart issue with the current release, but I will open another issue for that.)
At that point thanks again for the awesome work on that project. :)
Best regards
Fab

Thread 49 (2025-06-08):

Different behavior depending on the power source

MHordecki, 2025-06-08:
Hi!

I've been setting up my Doorman unit recently. There is not enough current on the intercom bus so the unit is powered from the USB-C port.

In my custom YAML config, I've set up the unit to open the door after the entrance doorbell is pressed four times in quick succession. This works nicely, but only when the Doorman unit is powered from a Macbook (I have two Macbooks at home, both work). When I power the Doorman from a wall USB-C charger or a USB-C powerbank, the button is not recognized at all. Other functions, such as the web interface or MQTT-driven control of the TC bus, are unaffected.

This is very bizarre. I've attached log files with level=VERBOSE, collected through MQTT. Nothing there stands out to me. When running off wall socket power, logs for binary_sensor simply do not appear.

Thanks in advance for any ideas!

[doorman-s3.yaml.txt](https://github.com/user-attachments/files/20646308/doorman-s3.yaml.txt)
[mqtt-log-with-wallpower.txt](https://github.com/user-attachments/files/20646310/mqtt-log-with-wallpower.txt)
[mqtt-log-with-macbook.txt](https://github.com/user-attachments/files/20646309/mqtt-log-with-macbook.txt)

AzonInc, 2025-06-08:
That sounds like a ground noise issue.

The same issue might occur when you connect your MacBook to the charger while it's connected to the Doorman PCB. I tested powering the PCB with my notebook, which worked fine—until I charged it.

You could try using an isolated power supply. Some power supplies work, while others don't, as they seem to cause a significant amount of noise.

I'm going to verify the isolator solution in 1–2 weeks when I can test it.

Let me know if you find out anything new.

Might be worth adding possible solutions to the docs as well.

AzonInc, 2025-06-08:
I'll also verify which hardware revisions are affected, since I have one of each version here.

Hopefully, we can identify whether the issue can be fixed by changing the design.

MHordecki, 2025-06-09:
Good observation! I've repeated the test using a plugged-in Macbook and indeed it doesn't recognize the button press anymore. I've also repeated the test with an USB-C power bank. I had previously reported that this combination also doesn't work; upon retry, I can report that it does in fact work, it's just that the power bank turns off due to the very low power draw of the ESP32. Last time, I had been too slow in pressing the buttons and the power bank had powered down the device.

I've also tried the experiment with my bench-top power supply - it didn't work, but the power supply isn't fully isolated, so it makes sense.

I'm considering getting an isolated AC/DC power supply, as you have suggested. Would something like [Traco Power TMPW](https://www.tracopower.com/series/tmpw-5-t) fit the bill?

AzonInc, 2025-06-17:
I tried a one of the USB-Isolator based on Adum3160, which workfs fine for now using my computer.
For example [this one](https://www.amazon.de/Tsadeer-Isolator-ADUM3160-Digital-Unterst%C3%BCTzt-Transparentes-Schwarz/dp/B0BV11F63M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)

But I got mine on aliexpress for ~ 4€

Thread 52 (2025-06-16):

identification of TCS ISH 1030 fails

schildbach, 2025-06-16:
### Description

The automatic identification of my ISH 1030 fails. See log below.

Label inside indoor station:
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

Product description: https://www.tcsag.de/fileadmin/user_upload/TCS_DE/Metanavigation/Downloads/ARCHIV/Innenstationen/PI_ISH1030_1A.pdf

### Logs

```plain text
[11:16:42][D][tc_bus:876]: Identifying device model (Category 0) using serial number: 628747...
[11:16:42][D][tc_bus:419]: Sending Command - Type: SELECT_DEVICE_GROUP | Address: 0 | Payload: 0x0 | Serial-Number: 628747 | Length: 16-bit | Raw Data: 0x00005800
[11:16:42][D][text_sensor:064]: 'Last Bus Command': Sending state '5800'
[11:16:42][D][sensor:093]: 'Heap Free': Sending state 85920.00000 B with 0 decimals of accuracy
[11:16:42][D][sensor:093]: 'Heap Max Block': Sending state 30720.00000 B with 0 decimals of accuracy
[11:16:42][D][sensor:093]: 'Free PSRAM': Sending state 6659336.00000 B with 0 decimals of accuracy
[11:16:42][D][tc_bus:685]: Received command 0x00005800, but ignoring it as it matches the last sent command.
[11:16:42][I][remote.raw:041]: Received Raw: -6024, 1976, -2005, 3995, -2006, 3994, -4010, 1990, -2005, 1995, -2006, 1994, -2005, 1995, -2006, 1994, -2005, 1995, -2006, 2232, -5711, 2079, -1901, 2079, -1901, 4097, -1904
[11:16:43][D][tc_bus:419]: Sending Command - Type: REQUEST_VERSION | Address: 0 | Payload: 0x0 | Serial-Number: 628747 | Length: 32-bit | Raw Data: 0x59980BC0
[11:16:43][D][text_sensor:064]: 'Last Bus Command': Sending state '59980BC0'
[11:16:43][D][tc_bus:685]: Received command 0x59980BC0, but ignoring it as it matches the last sent command.
[11:16:43][E][tc_bus:294]: Unable to identify Hardware! Unknown model. Data received: 08080048
[11:16:43][I][remote.raw:028]: Received Raw: -6020, 3980, -2006, 3994, -2006, 3994, -4009, 1991, -2005, 3995, -4011, 1989, -2005, 3995, -4009, 1991, -2005, 1995, -2006, 1994, -2005, 1995, -4011, 1989, -4009, 3991, -4011, 3989, -2006, 1994, -2005, 1995, -2006, 1994, -4010, 2623, -6665,
[11:16:43][I][remote.raw:041]:   4466, -2199, 2272, -2199, 2279, -4431, 2271, -2199, 2272, -2198, 2272, -2199, 2282, -4430, 2271, -2200, 2271, -2199, 2271, -2200, 2271, -2199, 2272, -2198, 2272, -2199, 4469, -2199, 2282, -4430, 2272, -2199, 2253, -4431
```

### Which version of the ESPHome Doorman firmware config are you running?

_No response_

### How do you manage your Doorman's updates?

None

### If you're using an ESPHome YAML config, which version of ESPHome are you running?

_No response_

### ESPHome Config

```YAML

```

AzonInc, 2025-06-16:
Should be fixed by ec60a14

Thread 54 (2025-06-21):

tc_bus.send: command missing

lsrs7, 2025-06-21:
### Description

hi,

following command stops working:

button:
  - platform: template
    name: "Klingel E1"
    on_press:
      - tc_bus.send:
          command: 0x5DCF540

result:
[command] is an invalid option for [tc_bus.send]

Did I miss any migration in terms of the API?

### Logs

```plain text

```

### If you're using an ESPHome YAML config, which version of ESPHome are you running?

_No response_

### ESPHome Config

```YAML

```

AzonInc, 2025-06-21:
I'm gonna add a note to the breaking changes changelog section.

lsrs7, 2025-06-26:
Yes, now it works as before! Thx.

Closed 2025-07-06.

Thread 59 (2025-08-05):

False triggers in confirmable open door notification blueprint

tr4nt0r, 2025-08-05:
The blueprint seems to falsely trigger when the event entities change back to their previous state from the unavailable state. The unknown and unavailable states should be filtered out to prevent false triggers.

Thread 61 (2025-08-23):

crash when accessing webserver

matejbart, 2025-08-23:
### Description

Hi @AzonInc,

lately I updated my doorman(s)(hardware revs v1.4 & v1.5) to `2025.3.0` via USB and I have noticed firmware reboots once the webserver is simply just accessed (it's actually same stacktrace as posted in https://github.com/AzonInc/Doorman/issues/56#issuecomment-3128463043)

It's not a critical issue for me, because the crash doesn't occur if the entities are set via HA, but I just want to let you know.

BR

### Logs

```plain text
[17:04:41]Guru Meditation Error: Core  0 panic'ed (LoadProhibited). Exception was unhandled.
[17:04:41]
[17:04:41]Core  0 register dump:
[17:04:41]PC      : 0x42003e69  PS      : 0x00060c30  A0      : 0x8201bc3a  A1      : 0x3fcaef30
WARNING Decoded 0x42003e69: std::__cxx11::basic_string<char, std::char_traits<char>, std::allocator<char> >::_M_data() const at /Users/test/.platformio/packages/toolchain-xtensa-esp32s3/xtensa-esp32s3-elf/include/c++/12.2.0/bits/basic_string.h:234
 (inlined by) std::__cxx11::basic_string<char, std::char_traits<char>, std::allocator<char> >::basic_string(std::__cxx11::basic_string<char, std::char_traits<char>, std::allocator<char> > const&) at /Users/test/.platformio/packages/toolchain-xtensa-esp32s3/xtensa-esp32s3-elf/include/c++/12.2.0/bits/basic_string.h:544
[17:04:41]A2      : 0x3fcaef68  A3      : 0x00000000  A4      : 0x3fcaef70  A5      : 0x00000000
[17:04:41]A6      : 0x00000000  A7      : 0x00000000  A8      : 0x8201ff2f  A9      : 0x3fcaf080
[17:04:41]A10     : 0x0000000b  A11     : 0x00000000  A12     : 0x00000000  A13     : 0x00000001
[17:04:41]A14     : 0xb33fffff  A15     : 0xb33fffff  SAR     : 0x0000000a  EXCCAUSE: 0x0000001c
[17:04:41]EXCVADDR: 0x00000000  LBEG    : 0x400554b9  LEND    : 0x400554dd  LCOUNT  : 0x8201ff5d
[17:04:41]
[17:04:41]
[17:04:41]Backtrace: 0x42003e66:0x3fcaef30 0x4201bc37:0x3fcaef60 0x4201bcb9:0x3fcaefc0 0x4201ffbf:0x3fcaefe0 0x42020015:0x3fcaf020 0x4201aafd:0x3fcaf040 0x420245b5:0x3fcaf060 0x4201ff15:0x3fcaf080 0x4201ff2c:0x3fcaf0a0 0x4201cfdf:0x3fcaf0c0 0x4201d012:0x3fcaf110 0x420ce349:0x3fcaf130 0x420ce3f3:0x3fcaf150 0x42022f9c:0x3fcaf170 0x420261a2:0x3fcaf1a0 0x4200ba2e:0x3fcaf1c0
WARNING Found stack trace! Trying to decode it
WARNING Decoded 0x42003e66: std::__cxx11::basic_string<char, std::char_traits<char>, std::allocator<char> >::_Alloc_hider::_Alloc_hider(char*, std::allocator<char>&&) at /Users/test/.platformio/packages/toolchain-xtensa-esp32s3/xtensa-esp32s3-elf/include/c++/12.2.0/bits/basic_string.h:204
 (inlined by) std::__cxx11::basic_string<char, std::char_traits<char>, std::allocator<char> >::_Alloc_hider::_Alloc_hider(char*, std::allocator<char>&&) at /Users/test/.platformio/packages/toolchain-xtensa-esp32s3/xtensa-esp32s3-elf/include/c++/12.2.0/bits/basic_string.h:204
 (inlined by) std::__cxx11::basic_string<char, std::char_traits<char>, std::allocator<char> >::basic_string(std::__cxx11::basic_string<char, std::char_traits<char>, std::allocator<char> > const&) at /Users/test/.platformio/packages/toolchain-xtensa-esp32s3/xtensa-esp32s3-elf/include/c++/12.2.0/bits/basic_string.h:541
WARNING Decoded 0x4201bc37: esphome::web_server::WebServer::event_json(esphome::event::Event*, std::__cxx11::basic_string<char, std::char_traits<char>, std::allocator<char> > const&, esphome::web_server::JsonDetail) at /Users/test/doorman_s3/firmware/configurations/.esphome/build/doorman-s3/src/esphome/components/web_server/web_server.cpp:1743
WARNING Decoded 0x4201bcb9: esphome::web_server::WebServer::event_all_json_generator[abi:cxx11](esphome::web_server::WebServer*, void*) at /Users/test/doorman_s3/firmware/configurations/.esphome/build/doorman-s3/src/esphome/components/web_server/web_server.cpp:1740
WARNING Decoded 0x4201ffbf: esphome::web_server_idf::AsyncEventSourceResponse::deferrable_send_state(void*, char const*, std::__cxx11::basic_string<char, std::char_traits<char>, std::allocator<char> > (*)(esphome::web_server::WebServer*, void*)) at /Users/test/doorman_s3/firmware/configurations/.esphome/build/doorman-s3/src/esphome/components/web_server_idf/web_server_idf.cpp:508
 (inlined by) esphome::web_server_idf::AsyncEventSourceResponse::deferrable_send_state(void*, char const*, std::__cxx11::basic_string<char, std::char_traits<char>, std::allocator<char> > (*)(esphome::web_server::WebServer*, void*)) at /Users/test/doorman_s3/firmware/configurations/.esphome/build/doorman-s3/src/esphome/components/web_server_idf/web_server_idf.cpp:482
WARNING Decoded 0x42020015: esphome::web_server_idf::AsyncEventSource::deferrable_send_state(void*, char const*, std::__cxx11::basic_string<char, std::char_traits<char>, std::allocator<char> > (*)(esphome::web_server::WebServer*, void*)) at /Users/test/doorman_s3/firmware/configurations/.esphome/build/doorman-s3/src/esphome/components/web_server_idf/web_server_idf.cpp:306
WARNING Decoded 0x4201aafd: esphome::web_server::ListEntitiesIterator::on_event(esphome::event::Event*) at /Users/test/doorman_s3/firmware/configurations/.esphome/build/doorman-s3/src/esphome/components/web_server/list_entities.cpp:180
WARNING Decoded 0x420245b5: esphome::ComponentIterator::advance() at /Users/test/doorman_s3/firmware/configurations/.esphome/build/doorman-s3/src/esphome/core/component_iterator.cpp:350
WARNING Decoded 0x4201ff15: esphome::web_server_idf::AsyncEventSourceResponse::loop() at /Users/test/doorman_s3/firmware/configurations/.esphome/build/doorman-s3/src/esphome/components/web_server_idf/web_server_idf.cpp:418
WARNING Decoded 0x4201ff2c: esphome::web_server_idf::AsyncEventSource::loop() at /Users/test/doorman_s3/firmware/configurations/.esphome/build/doorman-s3/src/esphome/components/web_server_idf/web_server_idf.cpp:293
WARNING Decoded 0x4201cfdf: esphome::web_server::WebServer::loop() at /Users/test/doorman_s3/firmware/configurations/.esphome/build/doorman-s3/src/esphome/components/web_server/web_server.cpp:282
WARNING Decoded 0x4201d012: non-virtual thunk to esphome::web_server::WebServer::loop() at /Users/test/doorman_s3/firmware/configurations/.esphome/build/doorman-s3/src/esphome/components/web_server/web_server.h:210
WARNING Decoded 0x420ce349: esphome::Component::call_loop() at /Users/test/doorman_s3/firmware/configurations/.esphome/build/doorman-s3/src/esphome/core/component.cpp:77
WARNING Decoded 0x420ce3f3: esphome::Component::call() at /Users/test/doorman_s3/firmware/configurations/.esphome/build/doorman-s3/src/esphome/core/component.cpp:104
WARNING Decoded 0x42022f9c: esphome::Application::loop() at /Users/test/doorman_s3/firmware/configurations/.esphome/build/doorman-s3/src/esphome/core/application.cpp:74
WARNING Decoded 0x420261a2: loop() at /Users/test/doorman_s3/firmware/configurations/.esphome/build/doorman-s3/firmware/configurations/../components/ring-to-open.yaml:247
WARNING Decoded 0x4200ba2e: esphome::loop_task(void*) at /Users/test/doorman_s3/firmware/configurations/.esphome/build/doorman-s3/src/esphome/components/esp32/core.cpp:73 (discriminator 1)
```

### Which version of the ESPHome Doorman firmware config are you running?

2025.3.0

### How do you manage your Doorman's updates?

ESPHome YAML Config

### If you're using an ESPHome YAML config, which version of ESPHome are you running?

2025.3.1

### ESPHome Config

```YAML
No custom configs - I'm using this one (with v1.4):
esp32-s3-quad.ha.stock.master.example.yaml

and the "non-quad" for hardware rev v1.5
```

Closed 2025-10-07.

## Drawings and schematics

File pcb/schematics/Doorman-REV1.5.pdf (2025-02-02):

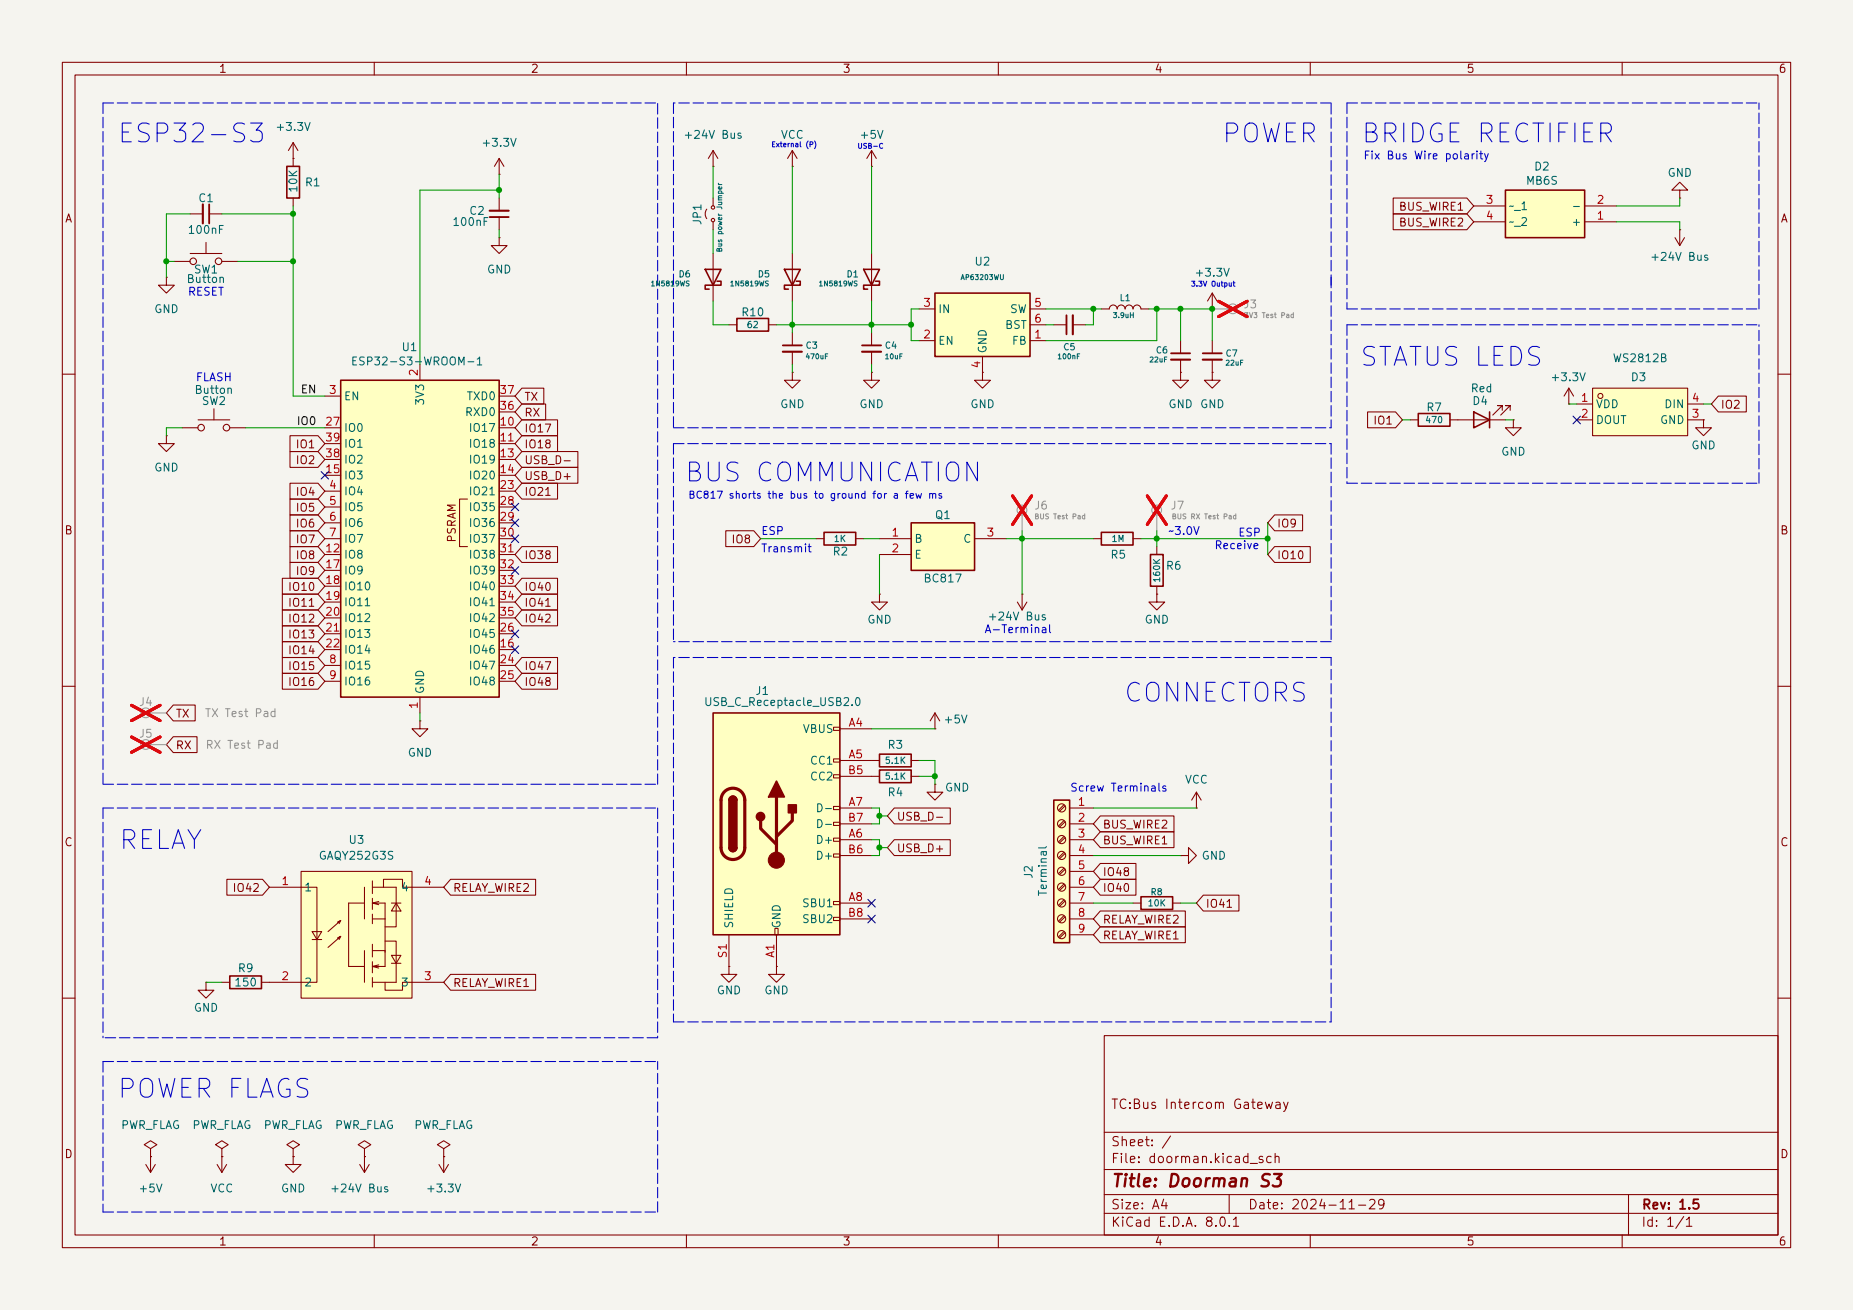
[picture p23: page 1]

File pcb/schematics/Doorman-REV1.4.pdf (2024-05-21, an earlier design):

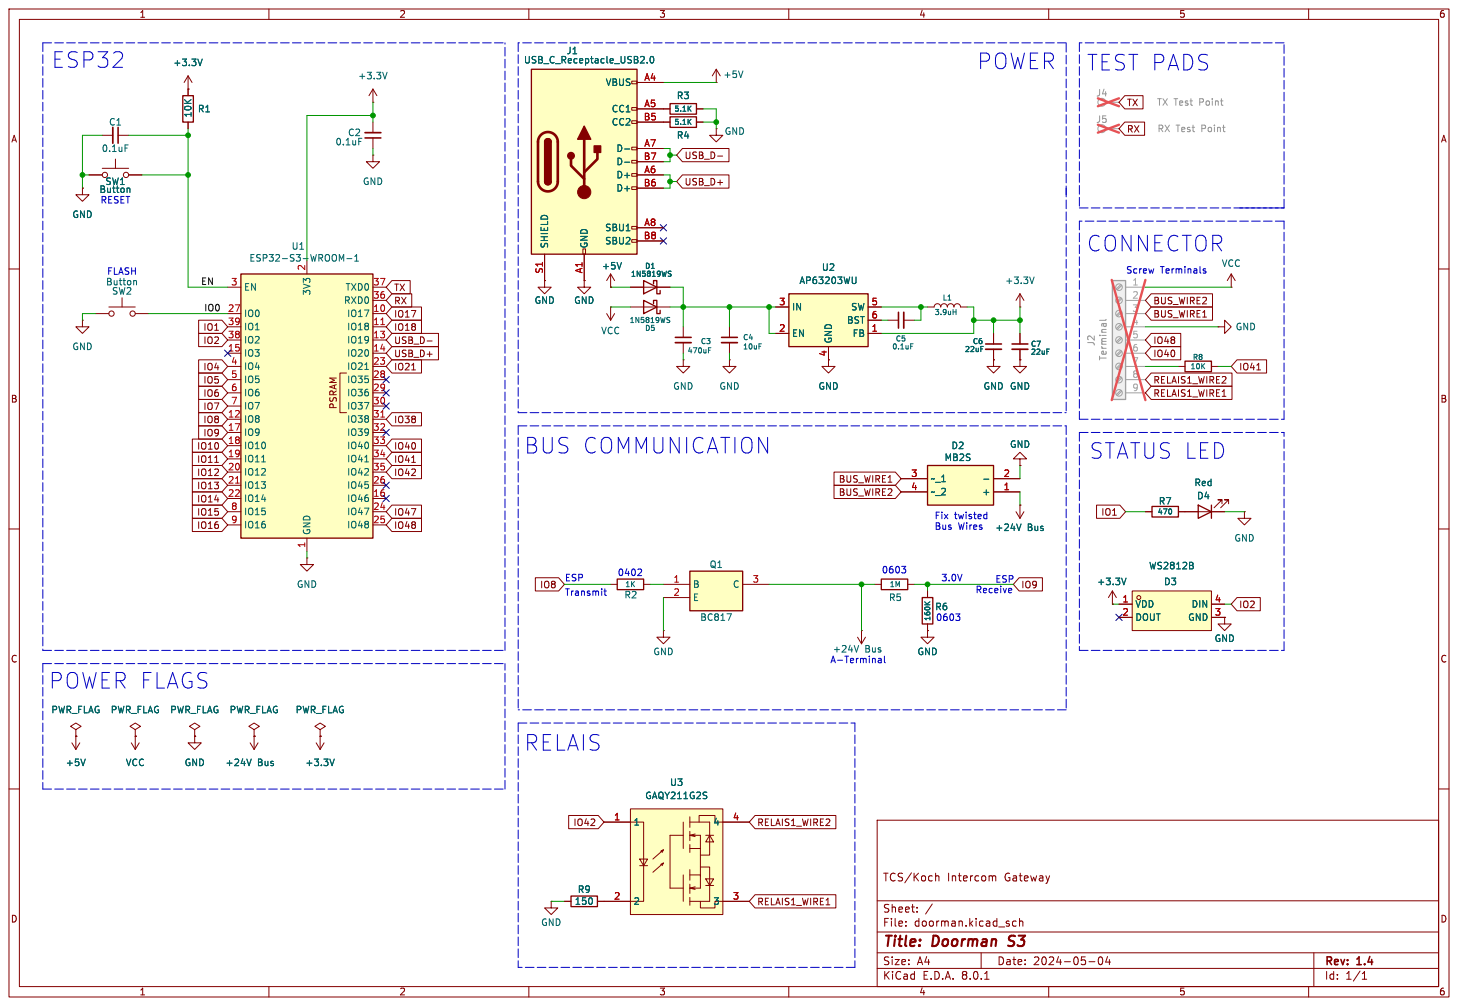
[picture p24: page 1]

Screw Terminals STATUS LED

Fix twisted Bus Wires POWER FLAGS

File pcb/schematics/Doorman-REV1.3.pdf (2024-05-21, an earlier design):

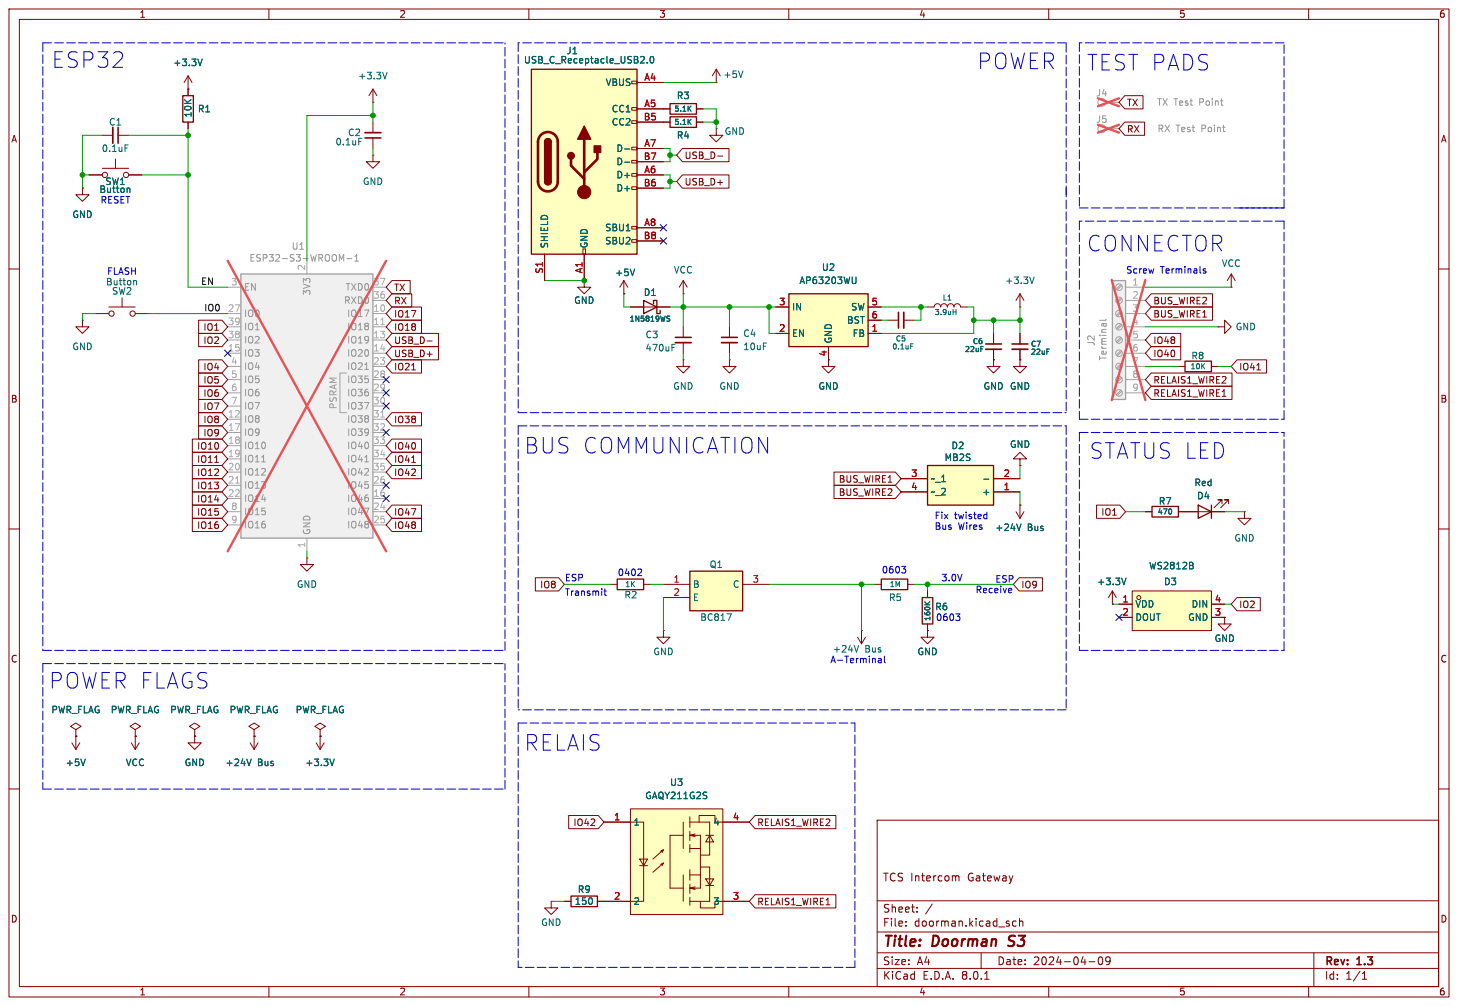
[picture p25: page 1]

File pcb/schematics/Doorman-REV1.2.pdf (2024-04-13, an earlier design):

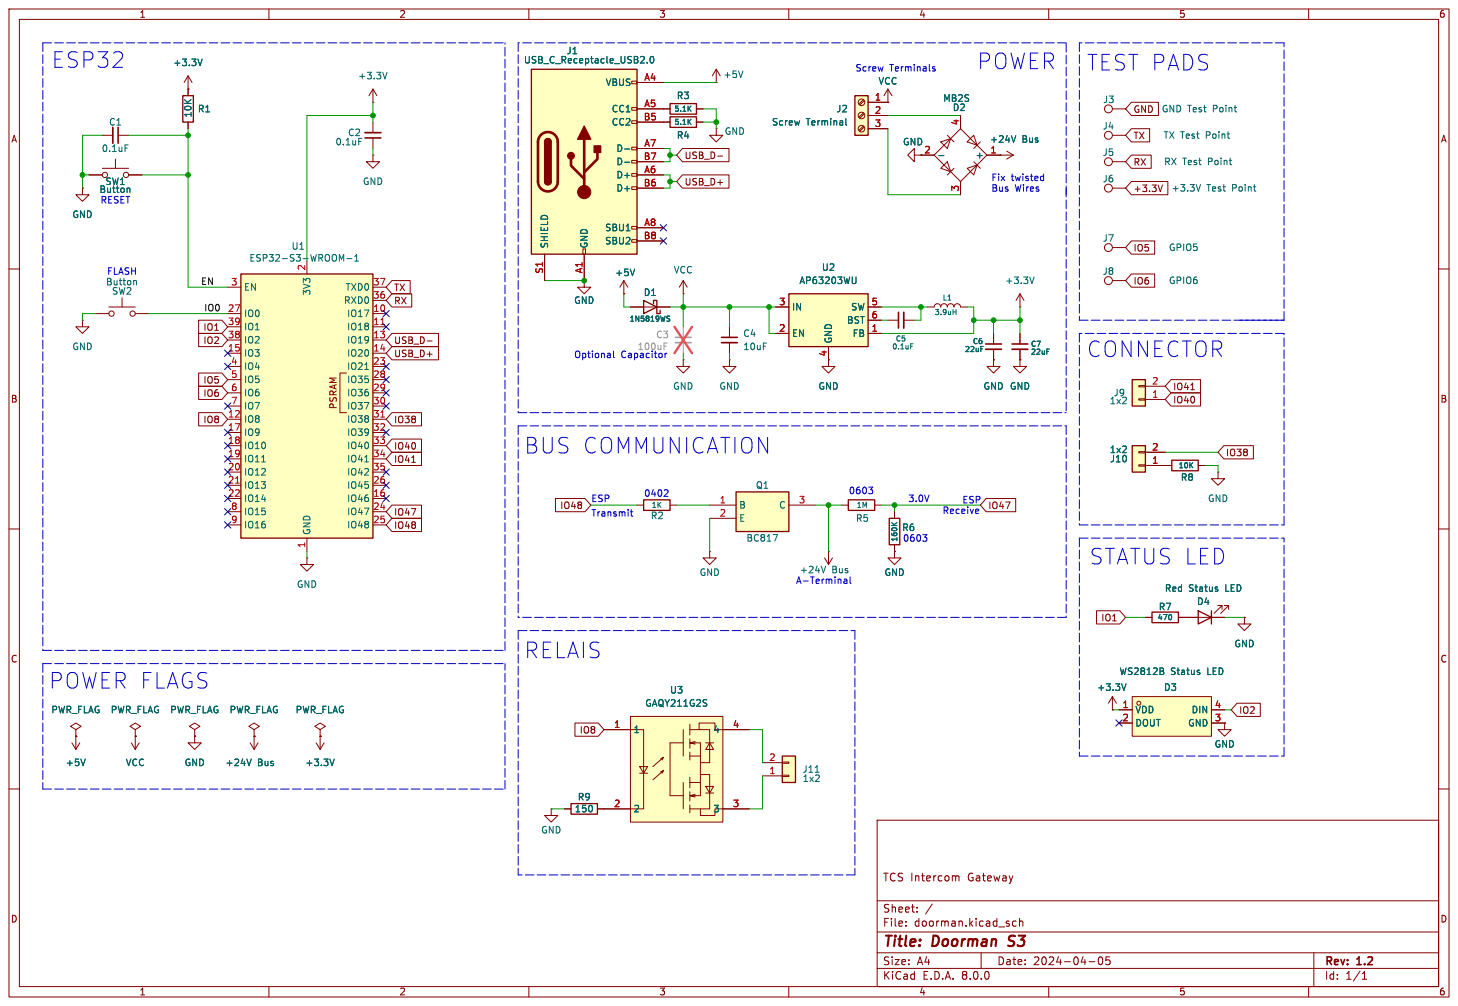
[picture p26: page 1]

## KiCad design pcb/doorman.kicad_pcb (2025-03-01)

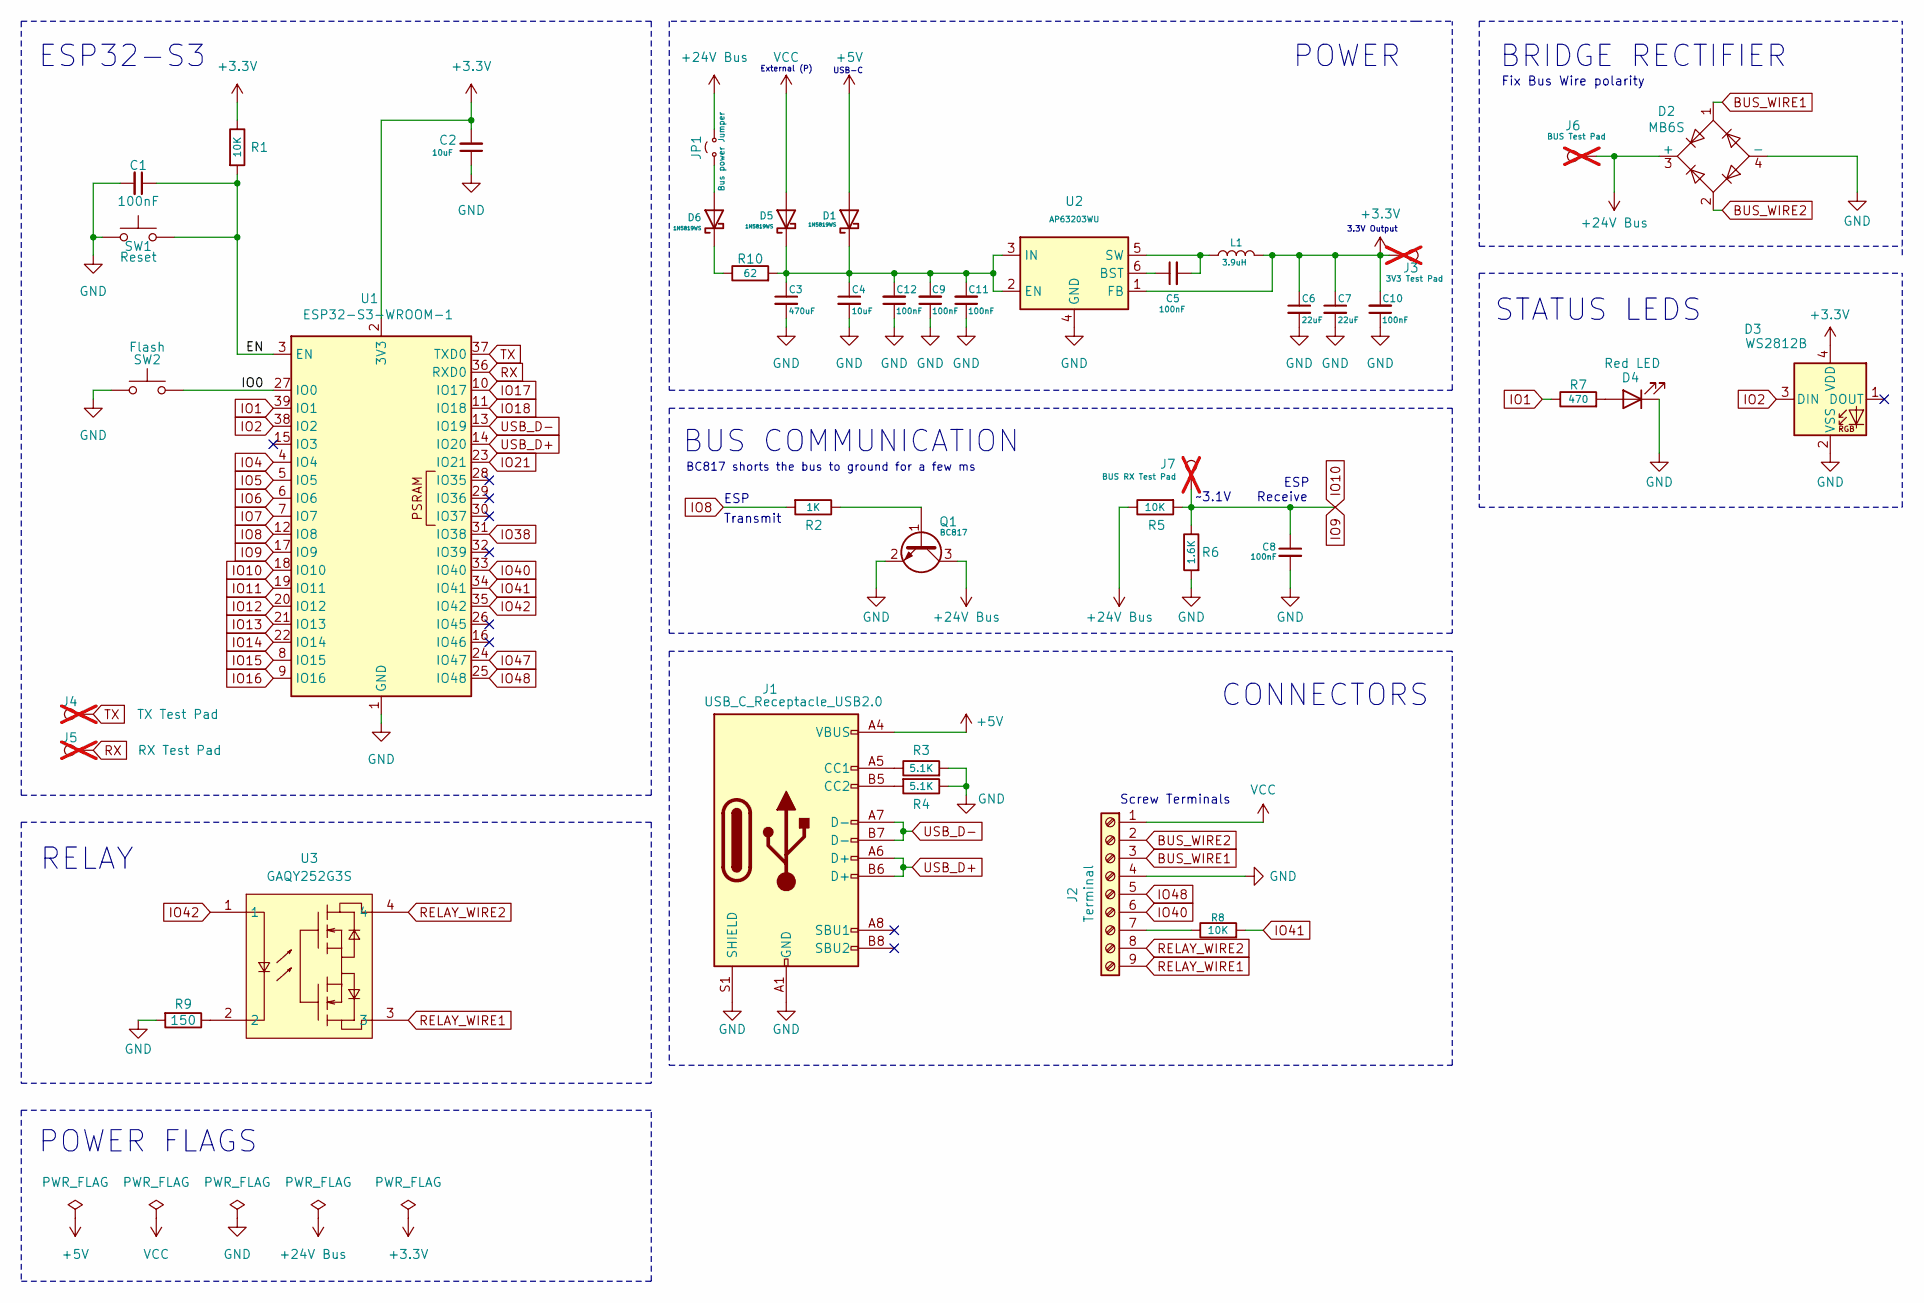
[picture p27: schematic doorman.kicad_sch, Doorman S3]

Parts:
C1, C5, C8, C9, C10, C11, C12: 100nF; C_0603_1608Metric; MPN CC0603KRX7R9BB104; LCSC C14663
C2: 10uF; C_0603_1608Metric; MPN CC0603KRX7R9BB104; LCSC C14663
C3: 470uF; CP_Elec_8x10; MPN EMZS350ARA471MHA0G; LCSC C2164331
C4: 10uF; C_1206_3216Metric; MPN CL31A106KBHNNNE; LCSC C13585
C6, C7: 22uF; C_0603_1608Metric; MPN CL10A226MQ8NRNC; LCSC C59461
D1, D5, D6: 1N5819WS; D_SOD-323; MPN 1N5819WS; LCSC C5451629
D2: MB6S; TO-269AA; MPN MB6S; LCSC C3011144
D3: WS2812B; LED_WS2812B-2020_PLCC4_2.0x2.0mm; MPN WS2812B-2020; LCSC C965555
D4: Red LED; LED_0603_1608Metric; MPN XL-1608SURC-06; LCSC C965799
J1: USB_C_Receptacle_USB2.0; USB_C_Receptacle_HRO_TYPE-C-31-M-12; MPN TYPE-C 16PIN 2MD(073); LCSC C2765186
J2: Terminal; CONN-TH_9P-P2.54_KF128-2.54-9P; MPN DB125-2.54-9P-GN-S; LCSC C918127
J3: 3V3 Test Pad; TestPoint_Pad_D1.0mm; not fitted
J4: TX Test Pad; TestPoint_Pad_D1.0mm; not fitted
J5: RX Test Pad; TestPoint_Pad_D1.0mm; not fitted
J6: BUS Test Pad; TestPoint_Pad_D1.0mm; not fitted
J7: BUS RX Test Pad; TestPoint_Pad_D1.0mm; not fitted
JP1: Bus power Jumper; PinHeader_1x02_P1.27mm_Vertical; MPN DZ127R-11-02-25; LCSC C2935942
L1: 3.9uH; L_Abracon_ASPI-4030S; MPN SWPA4030S3R9MT; LCSC C96899
Q1: BC817; SOT-23; MPN BC817-25,215; LCSC C39828
R1, R5, R8: 10K; R_0603_1608Metric; MPN 0603WAF1002T5E; LCSC C25804
R2: 1K; R_0402_1005Metric; MPN 0402WGF1001TCE; LCSC C11702
R3, R4: 5.1K; R_0402_1005Metric; MPN 0402WGF5101TCE; LCSC C25905
R6: 1.6K; R_0603_1608Metric; MPN 0603WAF1002T5E; LCSC C25804
R7: 470; R_0603_1608Metric; MPN 0603WAF4700T5E; LCSC C23179
R9: 150; R_0402_1005Metric; MPN 0402WGF1500TCE; LCSC C25082
R10: 62; R_1206_3216Metric; MPN 1206W4F620JT5E; LCSC C17971
SW1: Reset; SW_SPST_B3U-1000P-B; MPN B3U-1000P; LCSC C231329
SW2: Flash; SW_SPST_B3U-1000P-B; MPN B3U-1000P; LCSC C231329
U1: ESP32-S3-WROOM-1; MPN ESP32-S3-WROOM-1-N8R8; LCSC C2913201
U2: AP63203WU; TSOT-23-6; MPN AP63203WU-7; LCSC C780769
U3: GAQY252G3S; SOP-4_L4.4-W4.0-P2.54-LS7.0-TL; MPN GAQY252G3S; LCSC C7435106

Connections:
+3.3V: C2.2, C6.1, C7.1, C10.2, D3.4 (VDD), J3.1, L1.2, R1.1, U1.2 (3V3), U2.1 (FB)
+5V: D1.2 (A), J1.A4 (VBUS), J1.A9 (VBUS), J1.B4 (VBUS), J1.B9 (VBUS)
+24V Bus: D2.3 (+), J6.1, JP1.2 (B), Q1.3 (C), R5.1
/EN: C1.1, R1.2, SW1.1, U1.3 (EN)
/IO0: SW2.1, U1.27 (IO0)
BUS_WIRE1: D2.1, J2.3
BUS_WIRE2: D2.2, J2.2
GND: C1.2, C2.1, C3.2, C4.2, C6.2, C7.2, C8.2, C9.1, C10.1, C11.1, C12.1, D2.4 (-), D3.2 (VSS), D4.1 (K), J1.A1 (GND), J1.A12 (GND), J1.B1 (GND), J1.B12 (GND), J1.S1 (SHIELD), J2.4, Q1.2 (E), R3.2, R4.1, R6.2, R9.2, SW1.2, SW2.2, U1.1 (GND), U1.40 (GND), U1.41 (GND), U2.4 (GND)
IO1: R7.1, U1.39 (IO1)
IO2: D3.3 (DIN), U1.38 (IO2)
IO4: U1.4 (IO4)
IO5: U1.5 (IO5)
IO6: U1.6 (IO6)
IO7: U1.7 (IO7)
IO8: R2.2, U1.12 (IO8)
IO10: C8.1, J7.1, R5.2, R6.1, U1.17 (IO9), U1.18 (IO10)
IO11: U1.19 (IO11)
IO12: U1.20 (IO12)
IO13: U1.21 (IO13)
IO14: U1.22 (IO14)
IO15: U1.8 (IO15)
IO16: U1.9 (IO16)
IO17: U1.10 (IO17)
IO18: U1.11 (IO18)
IO21: U1.23 (IO21)
IO38: U1.31 (IO38)
IO40: J2.6, U1.33 (IO40)
IO41: R8.2, U1.34 (IO41)
IO42: U1.35 (IO42), U3.1
IO47: U1.24 (IO47)
IO48: J2.5, U1.25 (IO48)
unnamed: C3.1, C4.1, C9.2, C11.2, C12.2, D1.1 (K), D5.1 (K), R10.2, U2.2 (EN), U2.3 (IN)
unnamed: D4.2 (A), R7.2
unnamed: D6.2 (A), JP1.1 (A)
unnamed: D6.1 (K), R10.1
unnamed: J1.A5 (CC1), R3.1
unnamed: J1.B5 (CC2), R4.2
unnamed: J2.7, R8.1
unnamed: Q1.1 (B), R2.1
unnamed: R9.1, U3.2
unnamed: C5.1, U2.6 (BST)
unnamed: C5.2, L1.1, U2.5 (SW)
RELAY_WIRE1: J2.9, U3.3
RELAY_WIRE2: J2.8, U3.4
RX: J5.1, U1.36 (RXD0)
TX: J4.1, U1.37 (TXD0)
USB_D+: J1.A6 (D+), J1.B6 (D+), U1.14 (IO20)
USB_D-: J1.A7 (D-), J1.B7 (D-), U1.13 (IO19)
VCC: D5.2 (A), J2.1

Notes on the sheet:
Screw Terminals
USB-C
ESP
POWER
~3.1V
Transmit
CONNECTORS
3.3V Output
STATUS LEDS
External (P)
ESP32-S3
Fix Bus Wire polarity
RELAY
BRIDGE RECTIFIER
BC817 shorts the bus to ground for a few ms
POWER FLAGS
Receive
BUS COMMUNICATION

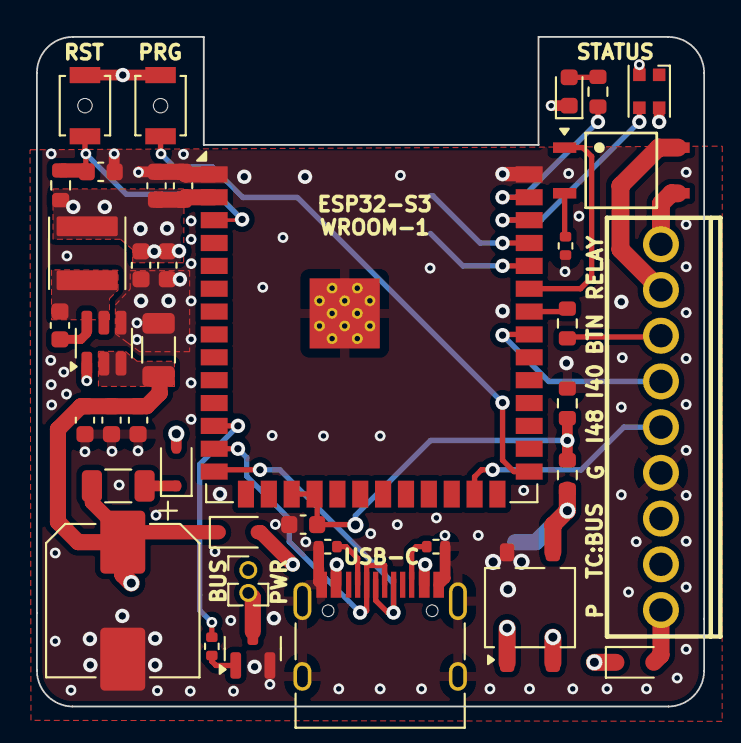
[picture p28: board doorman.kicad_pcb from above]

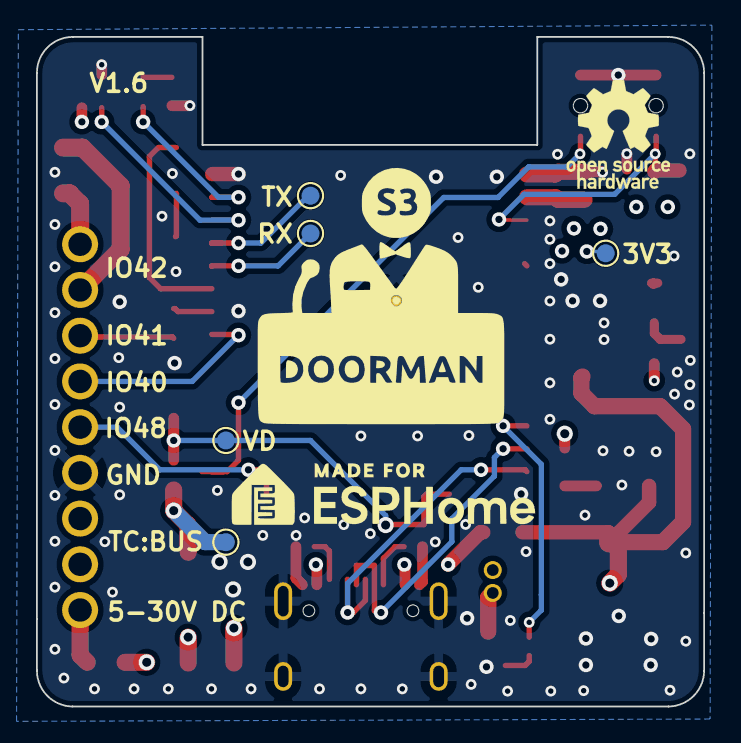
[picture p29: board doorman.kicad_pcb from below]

Board: 4 copper layers, 37.1 x 37.2 mm, 43 parts (5 on the bottom side), 34 nets.

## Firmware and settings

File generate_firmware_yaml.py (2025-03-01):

import os
from itertools import product

def get_host_architectures():
    """Get host architectures from firmware/hosts directory"""
    hosts_dir = os.path.join('firmware', 'hosts')
    if not os.path.exists(hosts_dir):
        raise FileNotFoundError(f"Hosts directory not found: {hosts_dir}")
    
    hosts = []
    for file in os.listdir(hosts_dir):
        if file.endswith('.yaml'):
            # Remove .yaml extension
            host = os.path.splitext(file)[0]
            hosts.append(host)
    
    if not hosts:
        raise ValueError("No host configuration files found in firmware/hosts directory")
    
    return sorted(hosts)  # Sort for consistent order

def get_packages(host, api_variant, firmware, branch):
    # Define packages in exact order with their conditions
    is_esp32 = 'esp32' in host.lower()
    has_psram = host in ['esp32-s2', 'esp32-s3', 'esp32-s3-quad']
    has_status_led = is_esp32

    packages_config = [
        ('host', f'!include ../hosts/{host}.yaml', True),
        
        ('rgb_status_led', '!include ../components/rgb-status-led.yaml', has_status_led),
        ('rgb_status_led', '!include ../components/rgb-status-led.dummy.yaml', not has_status_led),
        
        ('base', '!include ../base.yaml', True),
        ('bluedroid_ble', '!include ../components/bluedroid-ble.yaml', is_esp32 and firmware != 'nuki-bridge'),
        
        ('ota_updates', '!include ../components/ota-updates.yaml', api_variant == 'ha'),
        ('ota_updates_default_dev', '!include ../components/ota-updates-default-dev.yaml', api_variant == 'ha' and branch == 'dev'),
        ('dashboard_import', '!include ../components/dashboard-import.yaml', api_variant == 'ha'),
        
        ('api', '!include ../components/api-homeassistant.yaml', api_variant == 'ha'),
        ('api', '!include ../components/api-mqtt.yaml', api_variant == 'mqtt'),
        ('api', '!include ../components/api-custom.yaml', api_variant == 'custom'),

        ('debug_utilities', '!include ../components/debug-utilities.yaml', branch == 'dev'),
        ('debug_utilities_psram', '!include ../components/debug-utilities.psram.yaml', branch == 'dev' and has_psram),
        ('debug_utilities_non_esp32', '!include ../components/debug-utilities.non-esp32.yaml', branch == 'dev' and not is_esp32),

        ('pattern_events', '!include ../components/pattern-events.yaml', True),
        ('ring_to_open', '!include ../components/ring-to-open.yaml', True),
        ('intercom_settings', '!include ../components/intercom-settings.yaml', True),
        ('addon_nuki_bridge', '!include ../components/nuki-bridge.yaml', firmware == 'nuki-bridge'),
        ('interactive_setup', '!include ../components/interactive-setup.yaml', True),
    ]
    
    return [(name, path) for name, path, condition in packages_config if condition]

def generate_yaml_content(host, api_variant, firmware, branch):
    content = [
        'substitutions:',
        f'  branch: "{branch}"',
        f'  firmware_type: "{firmware}"',
        f'  api_variant: "{api_variant}"',
        f'  host_platform: "{host}"',
        '',
        'packages:'
    ]
    
    packages = get_packages(host, api_variant, firmware, branch)
    for name, path in packages:
        content.append(f'  {name}: {path}')
    
    return '\n'.join(content)

def generate_example_yaml(host, api_variant, firmware, branch):

    filename = f'github://azoninc/doorman/firmware/configurations/{host}.{api_variant}.{firmware}.{branch}.yaml@{branch}'
    
    content = [
        f'# Doorman {"Nuki Bridge" if firmware == "nuki-bridge" else "Stock"} Firmware ({"Home Assistant" if api_variant == "ha" else "MQTT"})',
        f'# Base Board {host.upper()}',
        '',
        '# You can change a few options here.',
        'substitutions:',
        '  name: "doorman-s3"',
        '  friendly_name: "Doorman S3"',
        '  # log_level: "ERROR"',
        '  # led_pin: "GPIO1"',
        '  # rgb_led_pin: "GPIO2"',
        '  # relay_pin: "GPIO42"',
        '  # external_button_pin: "GPIO41"',
        '  # adc_input_pin: "GPIO10"',
        '',
        '# Import Doorman Firmware Config',
        'packages:',
        f'  AzonInc.Doorman{"-Nuki-Bridge" if firmware == "nuki-bridge" else ""}: ' +
        f'{filename}',
        '',
        'wifi:',
        '  ssid: !secret wifi_ssid',
        '  password: !secret wifi_password'
    ]

    if api_variant == 'mqtt':
        content.extend([
            '',
            'mqtt:',
            '  broker: "10.10.0.2"',
            '  username: ""',
            '  password: ""'
        ])
    
    return '\n'.join(content)


# Configuration options
HOST_ARCHITECTURES = get_host_architectures()

API_VARIANTS = ['ha', 'mqtt', 'custom']
FIRMWARES = ['stock', 'nuki-bridge']
BRANCHES = ['master', 'dev']


def main():
    os.makedirs('firmware/configurations', exist_ok=True)
    os.makedirs('firmware/examples', exist_ok=True)
    
    combinations = product(HOST_ARCHITECTURES, API_VARIANTS, FIRMWARES, BRANCHES)
    for host, api_variant, firmware, branch in combinations:
        filename = f'{host}.{api_variant}.{firmware}.{branch}.yaml'
        example_filename = f'{host}.{api_variant}.{firmware}.{branch}.example.yaml'
        
        config_content = generate_yaml_content(host, api_variant, firmware, branch)
        example_content = generate_example_yaml(host, api_variant, firmware, branch)

        # Write config YAML
        config_filepath = os.path.join('firmware', 'configurations', filename)
        with open(config_filepath, 'w', encoding='utf-8') as f:
            f.write(config_content)
        
        # Write example YAML
        example_filepath = os.path.join('firmware', 'examples', example_filename)
        with open(example_filepath, 'w', encoding='utf-8') as f:
            f.write(example_content)
        
        print(f'Generated: {filename}')

if __name__ == '__main__':
    main()

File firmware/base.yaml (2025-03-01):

# Configurable Options
substitutions:
  name: "doorman-s3"
  friendly_name: "Doorman S3"
  log_level: "INFO"

# Essential ESPHome Configuration Options
esphome:
  name: ${name}
  friendly_name: ${friendly_name}
  name_add_mac_suffix: false
  min_version: "2025.2.0"
  project:
    name: "AzonInc.Doorman"
    version: "2025.3.0"

# Enable logging
# Prevent component warning spam
logger:
  level: ${log_level}
  logs:
    component: ERROR # avoids component warning spam
    sensor: WARN  # avoids logging debug sensor updates

web_server:
  version: 3
  sorting_groups:
    - id: sorting_group_controls
      name: "Controls"
      sorting_weight: -11
    - id: sorting_group_doorman_settings
      name: "Doorman Settings"
      sorting_weight: -10
    - id: sorting_group_intercom_settings
      name: "TC:BUS Intercom Settings"
      sorting_weight: -9
    - id: sorting_group_listeners
      name: "Doorman Listeners"
      sorting_weight: -7
    - id: sorting_group_nuki
      name: "Nuki Lock"
      sorting_weight: -5
    - id: sorting_group_nuki_settings
      name: "Nuki Lock Settings"
      sorting_weight: -4
    - id: sorting_group_nuki_bridge_settings
      name: "Nuki Bridge"
      sorting_weight: -3
    - id: sorting_group_system
      name: "System"
      sorting_weight: -2
    - id: sorting_group_diagnostic
      name: "Diagnostic"
      sorting_weight: -1

wifi:
  ap:
    ssid: "${friendly_name} Setup"
    password: "open-sesame"

captive_portal:

# Improv for easy provisioning
improv_serial:

# Import TC:BUS Component
external_components:
  - source: github://azoninc/doorman@${branch}
    components: [ tc_bus ]
    refresh: 60s

# Setup TC:BUS Component
tc_bus:
  id: tc_bus_intercom
  event: "doorman"
  
number:
  - platform: tc_bus
    serial_number:
      id: serial_number
      name: "Serial Number"
      icon: "mdi:numeric"
      disabled_by_default: true
      web_server:
        sorting_group_id: sorting_group_intercom_settings
        sorting_weight: -20

  - platform: template
    id: entrance_door_station_id
    name: "Entrance Door Station ID"
    mode : box
    icon: "mdi:counter"
    restore_value: true
    initial_value: '0'
    max_value: 63
    min_value: 0
    step: 1
    optimistic: true
    disabled_by_default: true
    entity_category: CONFIG
    web_server:
      sorting_group_id: sorting_group_intercom_settings
      sorting_weight: -20

  - platform: template
    id: second_door_station_id
    name: "Second Door Station ID"
    mode : box
    icon: "mdi:counter"
    restore_value: true
    initial_value: '63'
    max_value: 63
    min_value: 0
    step: 1
    optimistic: true
    disabled_by_default: true
    entity_category: CONFIG
    web_server:
      sorting_group_id: sorting_group_intercom_settings
      sorting_weight: -20

text_sensor:
  - platform: tc_bus
    hardware_version:
      id: doorman_hardware_version
      name: "Hardware"
      icon: "mdi:router-wireless"
      disabled_by_default: true
      entity_category: DIAGNOSTIC
      web_server:
        sorting_group_id: sorting_group_diagnostic
        sorting_weight: -20
    bus_command:
      id: last_bus_command
      name: "Last Bus Command"
      web_server:
        sorting_group_id: sorting_group_listeners
        sorting_weight: -99

  - platform: template
    id: doorman_firmware_version
    name: "Firmware"
    icon: mdi:new-box
    lambda: |-
      return to_string(ESPHOME_PROJECT_VERSION);
    entity_category: DIAGNOSTIC
    web_server:
      sorting_group_id: sorting_group_diagnostic
      sorting_weight: -20

switch:
  # Preconfigured Relay Switch
  - platform: gpio
    name: Relay
    icon: mdi:electric-switch
    id: doorman_relay
    restore_mode: RESTORE_DEFAULT_OFF
    disabled_by_default: true
    pin: ${relay_pin}
    web_server:
      sorting_group_id: sorting_group_controls
      sorting_weight: -7
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

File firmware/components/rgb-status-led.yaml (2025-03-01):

light:
  - platform: esp32_rmt_led_strip
    id: doorman_rgb_status_led
    icon: "mdi:led-on"
    name: RGB Status LED
    internal: true
    restore_mode: ALWAYS_OFF
    rgb_order: GRB
    pin: ${rgb_led_pin}
    num_leds: 1
    chipset: ws2812
    gamma_correct: 1
    default_transition_length: 0ms
    effects:
      - pulse:
          name: pulse
          transition_length: 250ms
          update_interval: 250ms
          min_brightness: 0%
          max_brightness: 40%
      - pulse:
          name: slow_pulse
          transition_length: 1s
          update_interval: 2s
          min_brightness: 0%
          max_brightness: 40%
      - pulse:
          name: slow_partymode
          transition_length: 4s
          update_interval: 2s
          min_brightness: 0%
          max_brightness: 40%
    web_server:
      sorting_group_id: sorting_group_system
      sorting_weight: -8

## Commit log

2024-03-26 Update Files
    [TSR_1-2450.step, doorman.kicad_pcb, doorman.kicad_sch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]
2024-03-28 Update PCB
    [doorman.kicad_pcb, doorman.kicad_sch]
2024-03-28 Rename Layers in favor of JLCPCB Plugin
    [doorman.kicad_pcb]
2024-04-01 Add LED Boot Sequence
2024-04-13 Add Enclosure
    [Cover.stl, Enclosure.stl, doorman.kicad_pcb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]
2024-04-13 Adjust Flash Size to new Design
    [Cover.stl, Enclosure.stl, MB2S.step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]
2024-04-13 Update Enclosure to new Layout
    [Bottom.stl, Cover.stl, Enclosure.stl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]
2024-04-14 Update wiring docs
2024-04-14 Change Text Position
    [doorman.kicad_pcb]
2024-04-16 Prevent short circuit when using a terminal as power source
    [doorman.kicad_pcb, doorman.kicad_sch]
2024-05-03 Small PCB fixes
    [doorman.kicad_pcb]
2024-05-04 Update Docs
    [doorman.kicad_sch]
2024-05-19 Update RGB LED Logic
2024-05-19 Revert Framework change
2024-05-21 Update PCB Files
    [doorman.kicad_pcb]
2024-05-21 Fix Nuki Bridge Firmware
    [base.yaml]
2024-05-22 Change LED Brightness
2024-05-31 Update BOM
    [doorman.kicad_pcb, doorman.kicad_sch]
2024-06-03 Update Readme to reflect current wiring options
    [doorman.kicad_pcb, doorman.kicad_sch]
2024-06-05 Add missing sensors & update examples
    [doorman.kicad_sch]
2024-06-13 Change Enclosure Tolerance
    [Bottom.stl, Top.stl]
2024-06-17 Fix OTA Breaking Change
    [base.yaml]
2024-08-08 Update ESPHome Logo
    [doorman.kicad_pcb]
2024-08-08 Update Enclosure STL
    [Bottom.stl, Top.stl]
2024-08-12 Restore Config Text Sensors
2024-08-12 Add Factory Settings Button
2024-08-12 Remove obsolete sensor
2024-08-13 Correct unit of delay
    [base.yaml]
2024-08-13 Move Nuki Battery Sensors to Diagnostic
2024-08-13 Rename Sensors
2024-08-13 Fix empty value check
    [base.yaml]
2024-08-13 Change Status LED
2024-08-13 Take care of Nuki pairing mode status led
2024-08-13 Add Board variant
2024-08-14 Add Uptime Sensor & Web Server
2024-08-14 Fix Uptime Sensor id duplicate
    [base.yaml]
2024-08-15 Disable Uptime Sensor by default
2024-08-15 Add Update Sensor to Docs
2024-08-15 Change Doorbell Device Class
2024-08-15 Revert "Change Doorbell Device Class"
    This reverts commit e6cfc616b13b822a6bcf8f281fd2cc66ec52fe19.
    [base.yaml]
2024-08-16 Add Light Button
2024-08-28 Fix initial Interactive Setup condition
    [base.yaml]
2024-08-28 Rename Light Button ids and entities
2024-09-18 Prevent Status LED from turning off
2024-10-11 Update Number State based on current settings
2024-10-11 Fix build on non ESP32 devices
    [tc_bus.cpp]
2024-10-11 Fix entrance doorbell pattern for single stations
    [base.yaml]
2024-10-14 Hardware revision 1.5
    [doorman.kicad_pcb, doorman.kicad_sch]
2024-10-14 Add interactive BOM to assets
2024-10-14 Add interactive BOM to docs & update dev reference
2024-10-14 Correct Hardware Model Name
    [tc_bus.cpp]
2024-10-14 Add Bus voltage Sensor
2024-10-17 Move Sensors to sensors
2024-10-17 Add Door readiness Sensor
2024-10-18 Fix Control Function Button
    [base.yaml]
2024-10-18 Status LED workaround
2024-11-18 Update Enclosure Bottom
    [Bottom.stl]
2024-12-07 Update Enclosure Files
    [Top.stl]
2024-12-07 Update Schematic
    [doorman.kicad_sch]
2024-12-07 Add switch to turn off ring to open led status
2025-01-06 Refactor doorbell event configuration to support per-button event tracking (#37)
2025-01-13 Remove Arduino sdk options
2025-01-13 Switch to new Security Pin Action
2025-01-13 Fix Pin Entity Mode
2025-01-16 Add device category retrieval and update model settings in documentation
2025-01-16 Add support for additional device models and update documentation
2025-01-19 Improve memory footprint for Nuki bridge addon
2025-01-20 Add experimental update switch, separate framework options
2025-01-21 Add icons to debug utilities and Nuki pin
2025-01-26 Fix model detection and remove serial_number if not needed
    [tc_bus.cpp]
2025-01-31 Switch to Nuki master branch
2025-02-07 Rearrange config files, bump version, switch to nuki idf
2025-02-08 Update component
    [doorman.kicad_pcb, doorman.kicad_sch]
2025-02-09 Supress sensor logs
2025-02-09 Update firmware configuration and add diagnostic sensors
2025-02-09 Add functionality for toggling Ring To Open automation with function button and update related documentation
2025-02-09 Change Switch to Select
2025-02-09 Refactor command data handling and add WiFi signal debugging sensor
2025-02-11 Update entity documentation and changelog for LED indicators and minimum ESPHome version
2025-02-11 Change log level to warn for failed setting write
    [tc_bus.cpp]
2025-02-12 Add firmware version sensor and remove debug loop time sensor
2025-02-12 Add Nuki Security Pin Status Entity
2025-03-01 Fix stable non esp32 config
    [generate_firmware_yaml.py]
